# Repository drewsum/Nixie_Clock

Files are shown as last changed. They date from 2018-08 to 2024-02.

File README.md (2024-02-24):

# Nixie_Clock

Rev B Hardware designed with KiCad 7.0.1

Rev B MCU Firmware written with MPLAB X IDE v6.15, compiled with Microchip XC32 2.30 Compiler - NOT COMPATIBLE with newer compiler versions (4.30)

## Rev A Readme:
A nixie clock designed around a PIC16LF1519

Programming notes: PIC16LF1519 (U501) is programmed through PICKIT3 interface header (J501). Firmware included in GIT repository should already be built and the hex file can be programmed directly into the flash on the PIC. If you wish to build it yourself, use Microchip's XC8 compiler, and ensure that the User ID bytes located in NVM match the expected_user_ID[] byte array saved in RAM. The values programmed into NVM are set in /mcc_generated_files/mcc.c, and are set with the line #pragma config IDLOCx = _ . Reference page 44 of the PIC16LF1519 datasheet. If you don't feel like altering user ID's, leave them unchanged in source code, and just build it as is. If user IDs and device IDs do not match, the clock will brick itself until reprogrammed with matching values.

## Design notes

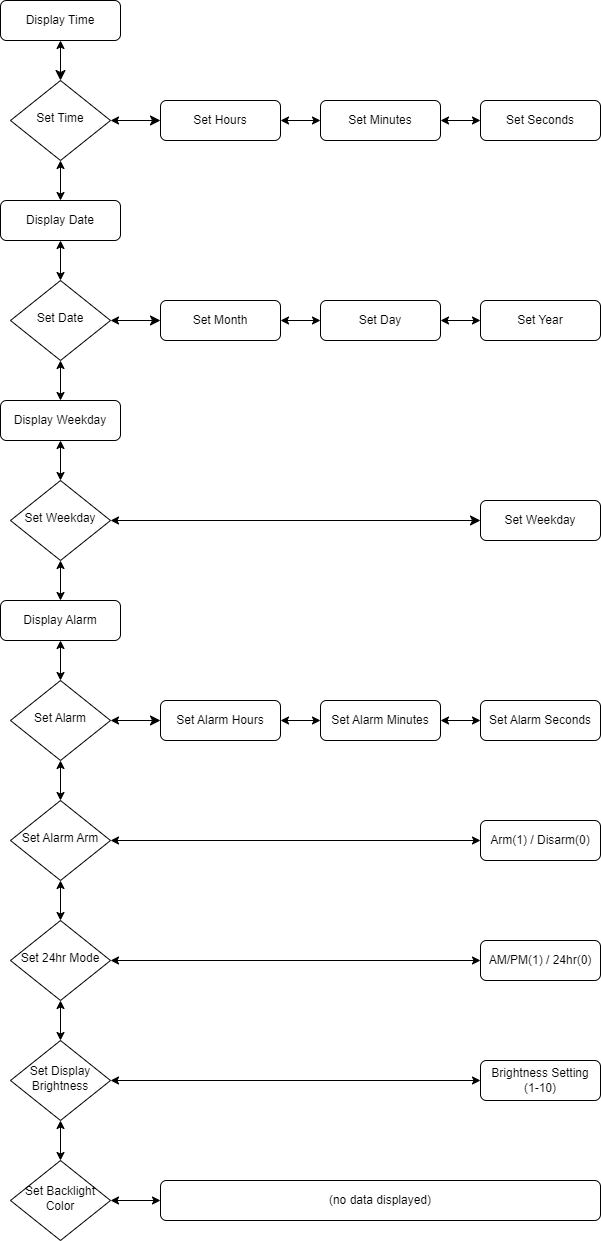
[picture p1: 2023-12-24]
rev_b/doc/pushbutton_menu_flow_chart.png

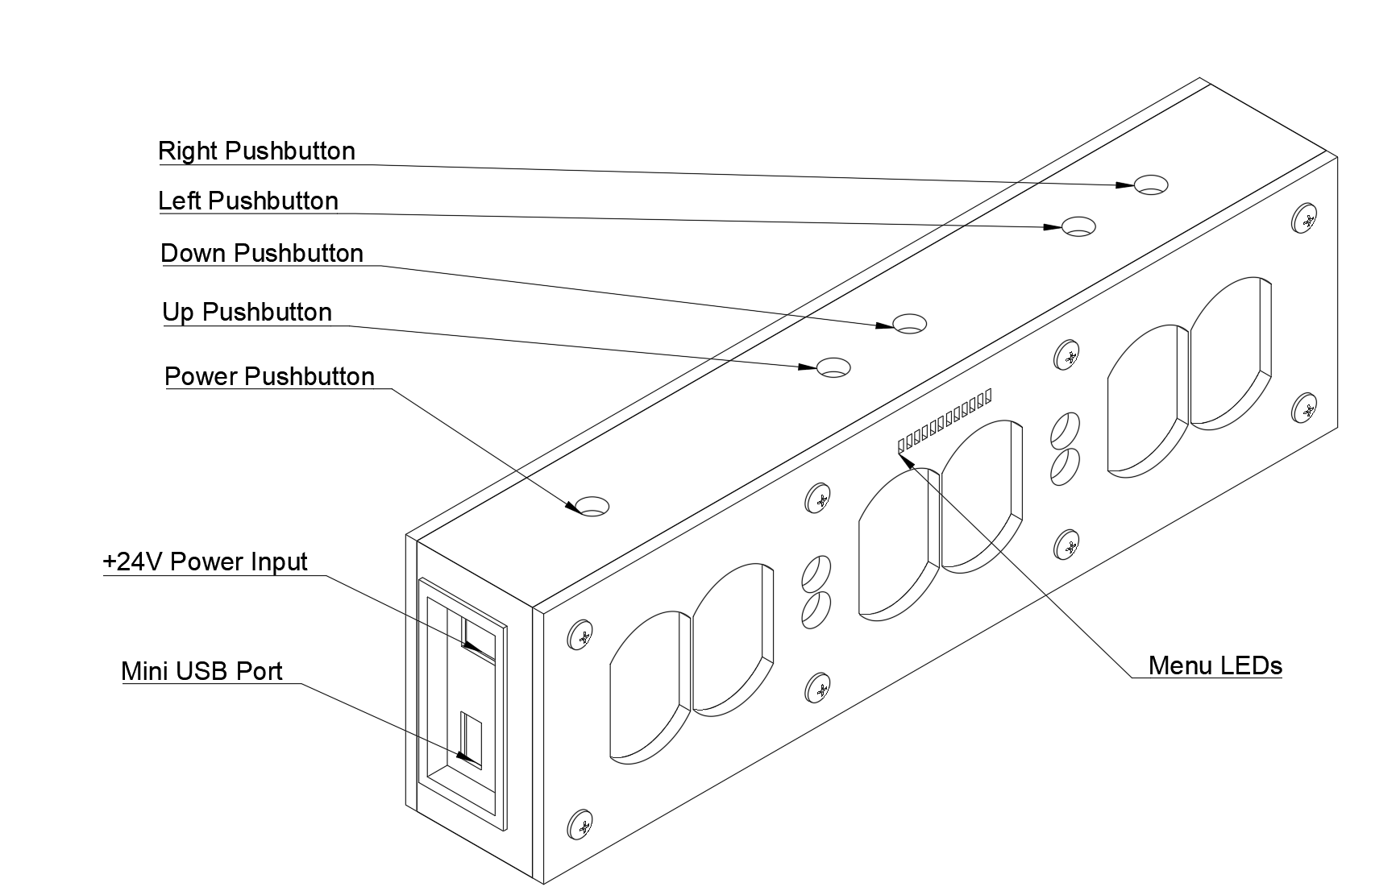
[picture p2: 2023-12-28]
rev_b/doc/IN-12_Variant_Iso_View.png

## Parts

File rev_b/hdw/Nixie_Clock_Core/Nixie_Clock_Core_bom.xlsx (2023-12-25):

References | Value | Configuration | Footprint | Quantity | Digi-Key PN
BT1201 | CR1616 | BACKUP_RTC |  | 1 | P034-ND
BT1202 | CR1616_Holder | BACKUP_RTC | BAT_BU1632SM-JJ-GTR | 1 | BU1632SM-JJ-GCT-ND
BZ2101 | CST-931RP-A |  | MagneticBuzzer_CUI_CST-931RP-A | 1 | 102-1461-ND
C409 C1308 C1309 | 47pF |  | C_0603 | 3 | 13-CC0603JPNPO9BN470CT-ND
C203 C404 C607 | 10nF |  | C_0603 | 3 | 1276-1009-1-ND
C204 C406 C604 C605 C610 C614 C801 C802 C901 C902 C905 C906 C909 C910 C913 C914 C1101 C1102 C1103 C1301 C1302 C1303 C1305 C1306 C1307 C1310 C1312 C1501 C1502 C1503 C1504 C1505 C1601 C1602 C1603 C1604 C1701 C1702 C1703 C1801 C1802 C1804 C2101 C2102 | 0.1uF |  | C_0603 | 44 | 1276-1935-1-ND
C1201 C1203 C1204 C1205 | 0.1uF | BACKUP_RTC | C_0603 | 4 | 1276-1935-1-ND
C1404 | 0.1uF | ETC | C_0603 | 1 | 1276-1935-1-ND
C609 C611 C612 | 0.1uF |  | C_1206 | 3 | 399-C1206C104K2RECAUTOCT-ND
C613 C1901 C1902 | 1.5uF |  | C_2220 | 3 | 565-4697-1-ND
C402 C608 C1803 C1805 | 4.7uF |  | C_0805 | 4 | 1276-2970-1-ND
C405 C903 C904 C907 C908 C911 C912 C915 C916 C1104 C1105 C1304 C1311 C1313 | 10uF |  | C_0603 | 14 | 1276-1871-1-ND
C1202 | 10uF | BACKUP_RTC | C_0603 | 1 | 1276-1871-1-ND
C1401 C1402 C1403 | 10uF | ETC | C_0603 | 3 | 1276-1871-1-ND
C201 C202 C205 C206 C401 C403 C407 C408 C601 C602 C603 C606 C1903 | 10uF |  | C_1206 | 13 | 1276-6767-1-ND
C207 | 47uF |  | CP_EIA-7343-43_Kemet-X | 1 | 399-16639-1-ND
D1401 | BAT48JFILM | ETC | D_SOD-323 | 1 | 497-5711-1-ND
D401 | BAT48JFILM |  | D_SOD-323 | 1 | 497-5711-1-ND
D1302 D1501 D1502 D1504 D1505 D1601 | Green |  | LED_0603 | 6 | 754-1121-1-ND
D801 | PESD3V3L5UY |  | SOT-363_SC-70-6 | 1 | 1727-3828-1-ND
D1503 D1602 D1603 D1604 | Red |  | LED_0603 | 4 | 754-1117-1-ND
D601 D602 D603 D2101 | SMD1200PL |  | D_SOD-123F | 4 | SMD1200PL-TPMSCT-ND
D1301 | Yellow |  | LED_0603 | 1 | 754-1124-1-ND
J1901 | Conn_02x32_Top_Bottom |  | CONN_5120527-1_TYC | 1 | A97407CT-ND
J1301 | USB_B_Mini |  | USB_Mini-B | 1 | 732-2109-1-ND
L401 | 2.2uH |  | L_Vishay_IHLP-2020 | 1 | 541-1268-1-ND
L601 | 680uH |  | Wurth_7447709681 | 1 | 732-1700-1-ND
L801 L802 L901 L902 L1101 L1102 L1301 L1302 | 600R 0.5A |  | L_0603 | 8 | 490-1014-1-ND
N201 | 24V PSU |  |  | 1 | 1939-1835-ND
Q401 Q801 Q2101 | BSS214NW |  | SOT-323_SC-70 | 3 | BSS214NWH6327XTSA1CT-ND
Q601 | IRFL214 |  | SOT-223-3_TabPin2 | 1 | IRFL214PBFCT-ND
Q402 | ZXMS6004FFTA |  | SOT-23 | 1 | ZXMS6004FFCT-ND
R206 R406 | 0.02 |  | R_0612 | 2 | P16010CT-ND
R611 | 0.36 |  | R_0805 | 1 | RL12S.36FCT-ND
R616 | 1.5 |  | R_0612 | 1 | RCL06121R20FKEA
R401 R801 R803 R1103 R1104 R2110 | 10 |  | R_0603 | 6 | 541-10.0HCT-ND
R2106 | 10 | ETC | R_0603 | 1 | 541-10.0HCT-ND
R2109 | 10 | BACKUP_RTC | R_0603 | 1 | 541-10.0HCT-ND
R1308 R1309 | 27 |  | R_0603 | 2 | 541-5306-1-ND
R602 | 330 |  | R_0603 | 1 | 541-330HCT-ND
R805 R1301 R1310 R1502 R1503 R1504 R1505 R1506 R1603 R1604 R1607 R1608 | 1k |  | R_0603 | 12 | 541-1.00KHCT-ND
R609 | 1.33k |  | R_0603 | 1 | 541-1.33KHCT-ND
R211 | 1.6k |  | R_0603 | 1 | 541-5237-1-ND
R201 | 1.78k |  | R_0603 | 1 | 541-1.78KHCT-ND
R603 | 3.4k |  | R_0603 | 1 | 541-3.40KHCT-ND
R1303 | 6.04k |  | R_0603 | 1 | 541-CRCW06036K04FKEBCT-ND
R610 | 6.49k |  | R_0603 | 1 | 541-5537-1-ND
R203 R204 R207 R210 R212 R402 R404 R605 R612 R802 R804 R1001 R1002 R1101 R1102 R1105 R1106 R1203 R1305 R1501 R1601 R1602 R1605 R1606 R1701 R1702 R1703 R1801 R1802 R1803 R1805 R1806 R2102 R2104 R2105 R2107 R2108 R2111 | 10k |  | R_0603 | 38 | 541-10.0KHCT-ND
R606 | 10k |  | R_0603 | 1 | 541-10.0KHCT-ND
R604 | 14k |  | R_0603 | 1 | 541-CRCW060314K0FKTACT-ND
R403 | 18.2k |  | R_0603 | 1 | 541-18.2KHCT-ND
R614 | 28.7k |  | R_0603 | 1 | 541-28.7KHCT-ND
R1304 | 40.2k |  | R_0603 | 1 | 541-5412-1-ND
R607 R1306 R1307 R1311 R1312 | 100k |  | R_0603 | 5 | 541-100KHCT-ND
R202 | 200k |  | R_0603 | 1 | 541-4027-1-ND
R1202 | 220k | BACKUP_RTC | R_0603 | 1 | 541-4039-1-ND
R409 | 309k |  | R_0603 | 1 | 541-309KHCT-ND
R1302 | 487k |  | R_0603 | 1 | 541-487KHCT-ND
R1201 | 1M | BACKUP_RTC | R_0603 | 1 | 541-1.00MHCT-ND
R408 | 1M |  | R_0603 | 1 | 541-1.00MHCT-ND
R2101 | 1.07M |  | R_0603 | 1 | 541-1.07MHCT-ND
R601 | 1.6M |  | R_0603 | 1 | 541-1.60MHCT-ND
R608 R613 | 1.6M |  | R_0603 | 2 | 541-1.60MHCT-ND
RN1701 RN1702 RN1703 RN1801 RN1802 | 10k |  | R_Array_Convex_8x0602 | 5 | Y1103CT-ND
U1101 | 74LVC1G97 |  | SOT-363_SC-70-6 | 1 | 296-15582-1-ND
U1303 U1601 U1602 U1603 U1604 | 74LVC1G97 |  | SOT-363_SC-70-6 | 5 | 296-15582-1-ND
U1501 U1502 U1504 U1505 | 74LVC1G97 |  | SOT-363_SC-70-6 | 4 | 296-15582-1-ND
U1503 | 74LVC1G97 |  | SOT-363_SC-70-6 | 1 | 296-15582-1-ND
U2102 | 74LVC1G97 |  | SOT-363_SC-70-6 | 1 | 296-15582-1-ND
U1701 U1702 U1703 U1802 | 74VHC541 |  | WQFN-20-1EP_2.5x4.5mm_P0.5mm_EP1x2.9mm | 4 | 1727-7068-1-ND
U1401 | DS1683 | ETC | SOIC-8_3.9x4.9mm_Pitch1.27mm | 1 | DS1683S+-ND
U1201 | DS3231MZ | BACKUP_RTC | SOIC-8_3.9x4.9mm_P1.27mm | 1 | DS3231MZ+-ND
U1302 | FT234XD |  | DFN-12-1EP_3x3mm_Pitch0.45mm | 1 | 768-1178-1-ND
U1304 | ISO7321C |  | SOIC-8_3.9x4.9mm_P1.27mm | 1 | 296-42102-1-ND
U602 | LT3757 |  | DFN-10-1EP_3x3mm_Pitch0.5mm | 1 | LT3757IDD#PBF
U401 | LT8609A-DD |  | DFN-10-1EP_3x3mm_Pitch0.5mm | 1 | 505-LT8609AEDDM#TRPBFCT-ND
U2101 | LTC6900 |  | SOT-23-5 | 1 | LTC6900CS5#TRMPBFCT-ND
U1001 | PIC32MZ2048EFG100_IPF |  | TQFP-100_14x14mm_Pitch0.5mm | 1 | PIC32MZ0512EFE100-I/PF-ND
U1801 | TCA9803 |  | VSSOP-8_3.0x3.0mm_P0.65mm | 1 | 296-47829-1-ND
U1202 | TLV6700 | BACKUP_RTC | SOT-23-6 | 1 | 296-51696-1-ND
U601 U603 U1301 | TLV6700 |  | SOT-23-6 | 3 | 296-51696-1-ND
U1305 | TPD3S014DBVR |  | SOT-23-6 | 1 | 296-38835-1-ND
U201 | TPS26600RHFT |  | QFN-24-1EP_4x5mm_Pitch0.5mm | 1 | 296-45478-1-ND
X1101 | ASE-8.000MHz |  | Oscillator_SMD_Abracon_ASE-4Pin_3.2x2.5mm | 1 | 535-9558-1-ND
X1102 | ECS-327KE |  | ECS-327KE | 1 | XC1751CT-ND

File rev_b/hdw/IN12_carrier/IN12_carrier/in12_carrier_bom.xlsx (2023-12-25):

References | Value | Configuration | Footprint | Quantity Per PCB | Digi-Key PN
C1007 C1008 C1009 C1010 C1016 | 10nF |  | C_0603 | 5 | 1276-1009-1-ND
C707 C708 C709 C1001 C1002 C1003 C1004 C1005 C1006 C1011 C1012 C1013 C1014 C1015 C1017 | 0.1uF |  | C_0603 | 15 | 1276-CL10B104KB8NNNLCT-ND
C304 C305 | 0.1uF | ETC | C_0603 | 2 | 1276-CL10B104KB8NNNLCT-ND
C301 C302 C303 | 10uF | ETC | C_0603 | 3 | 1276-1871-1-ND
C701 C702 C703 C704 C705 C706 | 10uF |  | C_0603 | 6 | 1276-1871-1-ND
D701 D702 D703 D704 D705 D706 D707 D708 | ASMB-MTB0-0A3A2 |  | LED_Avago_PLCC4_3.2x2.8mm_CW | 8 | 516-3279-1-ND
D901 D1001 D1002 D1003 D1004 D1005 D1006 D1007 D1008 D1009 D1010 D1011 | Amber |  | LED_0603 | 12 | 732-150060AS75000CT-ND
D301 | BAT48JFILM | ETC | D_SOD-323 | 1 | 497-5711-1-ND
J201 | Conn_02x32_Top_Bottom |  | CONN_5120528-1_TYC | 1 | A104089CT-ND
MK1107 MK1108 MK1115 MK1116 MK1123 MK1124 MK1131 MK1132 MK1133 MK1134 MK1135 MK1136 MK1137 MK1138 MK1139 MK1140 | Screw |  |  | 16 | 36-9900-ND
MK1101 MK1102 MK1103 MK1104 MK1105 MK1106 MK1109 MK1110 MK1111 MK1112 MK1113 MK1114 MK1117 MK1118 MK1119 MK1120 MK1121 MK1122 MK1125 MK1126 MK1127 MK1128 MK1129 MK1130 | Standoff |  |  | 8 | 1772-2080-ND
MK1101 MK1102 MK1103 MK1104 MK1105 MK1106 MK1109 MK1110 MK1111 MK1112 MK1113 MK1114 MK1117 MK1118 MK1119 MK1120 MK1121 MK1122 MK1125 MK1126 MK1127 MK1128 MK1129 MK1130 | Standoff |  |  | 16 | 1772-1220-ND
Q401 Q402 Q403 Q407 Q408 Q409 Q501 Q502 Q503 Q504 Q505 Q506 Q507 Q508 Q509 Q510 Q511 Q512 Q513 Q514 Q515 | MMSTA42 |  | SOT-323_SC-70 | 21 | MMSTA42-FDICT-ND
Q404 Q405 Q406 Q410 Q411 Q412 | MMSTA92 |  | SOT-323_SC-70 | 6 | MMSTA92-TPCT-ND
R901 R1001 R1002 R1003 R1004 R1005 R1006 R1007 R1008 R1009 R1010 R1011 R1016 R1017 R1018 R1019 R1021 | 499 |  | R_0603 | 17 | 541-CRCW0603499RFKEBCT-ND
R704 R705 R706 | 3.65k |  | R_0603 | 3 | 541-3.65KHCT-ND
R701 R1012 R1013 R1014 R1015 R1020 | 10k |  | R_0603 | 6 | 541-10.0KHCT-ND
R301 R302 R305 | 10k | ETC | R_0603 | 3 | 541-10.0KHCT-ND
R401 R402 R403 R413 R414 R415 R501 R502 R503 R504 R505 R506 R507 R508 R509 R510 R511 R512 R513 R515 R516 | 10k |  | R_0603 | 21 | 541-10.0KHCT-ND
R601 R602 R603 R604 | 10k |  | R_0805 | 4 | 541-3015-1-ND
R410 R411 R412 R422 R423 R424 R514 | 18k |  | R_0805 | 7 | 541-18.0KCCT-ND
R407 R408 R409 R419 R420 R421 | 100k |  | R_0805 | 6 | 541-4318-1-ND
R303 | 392k | ETC | R_0603 | 1 | 541-392KHCT-ND
R404 R405 R406 R416 R417 R418 R801 R802 R803 R804 R805 R806 R807 R808 R809 R810 R811 R812 R813 R814 R815 R816 R817 | 470k |  | R_0805 | 23 | 541-470KCCT-ND
R304 | 1M | ETC | R_0603 | 1 | 541-2990-1-ND
U1002 | 24AA02-OT |  | SOT-23-5 | 1 | 24AA02E64T-I/OT
U1003 U1004 U1005 U1006 U1007 | AT42QT1010-TSHR |  | SOT-23-6 | 5 | AT42QT1010-TSHRCT-ND
U301 | DS1683 | ETC | SOIC-8_3.9x4.9mm_Pitch1.27mm | 1 | DS1683S+-ND
U701 U702 U703 | LP5009 |  | UQFN-20-1EP_3x3mm_Pitch0.4mm | 3 | 296-LP5009RUKRCT-ND
U302 | LTC4316DD | ETC | DFN-10-1EP_3x3mm_Pitch0.5mm | 1 | LTC4316IDD#PBF-ND
U1001 | TCA9555RGER |  | QFN-24-1EP_4x4mm_P0.5mm_EP2.6x2.6mm | 1 | 296-44537-1-ND
MK1001 | Pushbutton Cable |  |  | 1 | SAM8931-ND
MK1002 MK1003 MK1004 MK1005 MK1006 | Pushbuttons |  |  | 5 | 36-7600-ND
MK1101 | Feet |  |  | 1 | SJ5523-0-ND

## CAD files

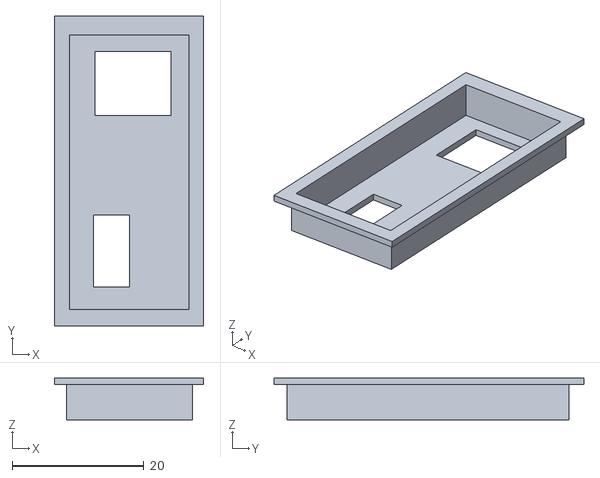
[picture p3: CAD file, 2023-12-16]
rev_b/misc/Nixie_Clock_Case_Connector Plate v2.stl
22.6 x 47.1 x 6.35

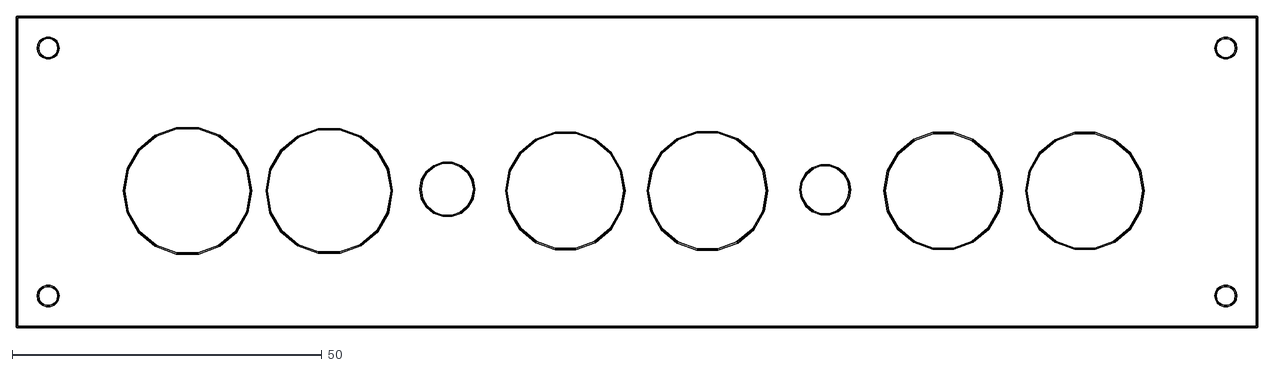
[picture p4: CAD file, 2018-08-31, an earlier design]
rev_a/Nixie Clock/Models/Nixie Test-Dwgs.User.dxf
200.2 x 50.2

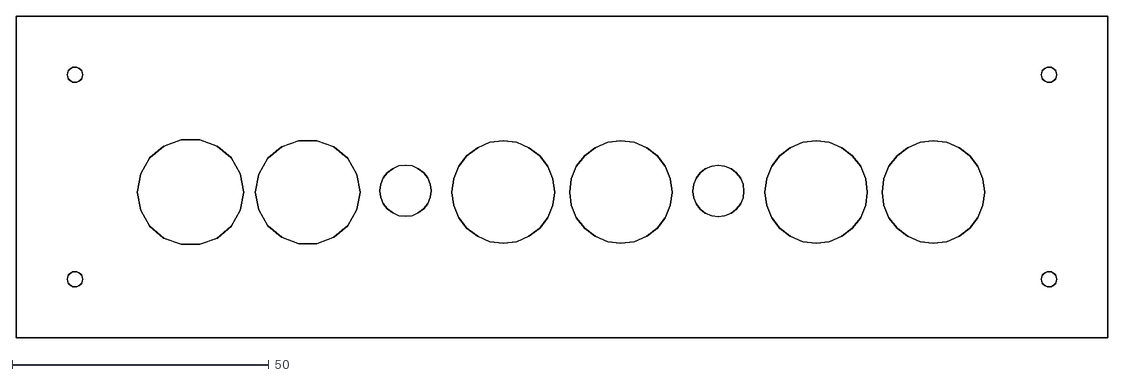
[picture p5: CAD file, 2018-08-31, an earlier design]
rev_a/Nixie Clock/Models/TopPlate.dxf
212.7 x 62.7

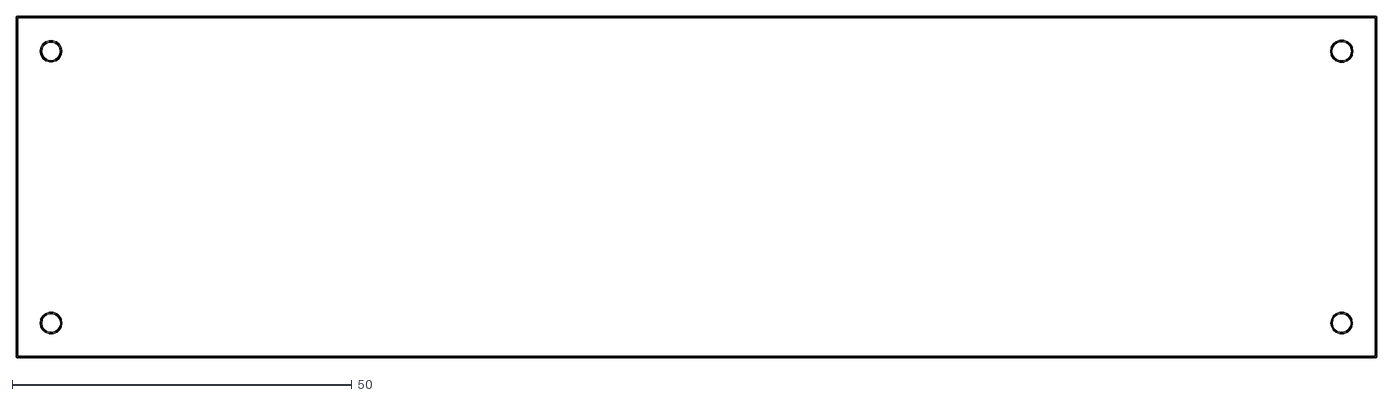
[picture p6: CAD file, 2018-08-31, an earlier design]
rev_a/Nixie Clock/Models/Nixie Clock-Dwgs.User.dxf
200.2 x 50.2

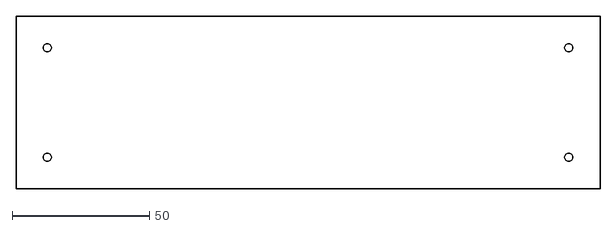
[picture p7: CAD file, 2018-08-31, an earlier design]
rev_a/Nixie Clock/Models/BottomPlate.dxf
212.7 x 62.7

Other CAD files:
rev_a/sfw/U501_Firmware/NixieClock.X/dist/default/production/NixieClock.X.production.obj
rev_a/Nixie Clock/Gerbers/SketchupModel.skp
rev_a/Nixie Clock/Gerbers/SketchupModel~.skp
rev_a/Nixie Clock/Models/BottomPlate.skp
rev_a/Nixie Clock/Models/BottomPlate~.skp
rev_a/Nixie Clock/Models/EnclosureWalls.skp
rev_a/Nixie Clock/Models/EnclosureWalls~.skp
rev_a/Nixie Clock/Models/SketchupModel.skp
rev_a/Nixie Clock/Models/TopPlate.skp
rev_b/misc/Nixie_Clock_Case v67.f3z

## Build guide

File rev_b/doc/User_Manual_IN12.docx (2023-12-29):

Drew Maatman

# Nixie clock redux

IN-12 VARIANT (ИН-12Б)

User Manual

# 1. Warnings

- This design contains high voltages that can be dangerous
- Ever effort has been made to keep this project safe, but the user assumes all risk
- The high voltage power supply has been designed with a low current limit to try to mitigate risk
- If any internal circuitry becomes exposed, do not touch it while the power cord is plugged in
- Do not use this project outside of its casing
- If the nixie tubes break, do not touch the metal elements inside. Remove power from the clock immediately
- The case is not waterproof
- The USB port is electrically isolated to mitigate risk of electrical stress to a host PC should a fault occur
- If the internal battery (CR1616 coin cell) needs to be replaced, do not leave the clock powered while changing the battery
- I am always willing to help troubleshoot issues, reach me at drewmaatman@gmail.com
- Nixie tubes age and degrade over time. Every effort has been made to maximize their lifetime within this design. The nixie tubes can be replaced if elements within them fail. Only do this when the clock is unpowered, and use care to not damage adjacent tubes

# 2. Clock Overview


Figure 1: Overview

- The clock requires a +24V DC power supply which can provide at least 12W of power
- The DC barrel jack for power input is center positive polarity
- The USB port is a USB 2.0 Mini B connector. This provides a serial interface and cannot power the clock (see USB/Serial Interface)
- The menu LEDs indicate the following menu settings, from left to right (see Pushbutton Interface)
  - Display Time
  - Set Time
  - Display Date
  - Set Date
  - Display Weekday
  - Set Weekday
  - Display Alarm
  - Set Alarm
  - Set Alarm Arm/Disarm
  - Set 24hr or AM/PM Format
  - Set Tube Brightness
  - Set RGB Backlight Color

# 3. Clock Features

- The tubes can be configured to display:
  - Time (24 hour or AM/PM)
  - Date (MM/DD/YY)
  - Weekday (Numbered from 1 to 7)
  - Alarm Time (24 hour or AM/PM)
  - Alarm Arm (Armed or Disarmed), see Setting the Alarm, Arming/Disarming the Alarm (with pushbuttons) as well as Setting the Alarm and Arming the Alarm (with USB/Serial Interface).
  - Time/Date/Weekday and Alarm Setting Modes (set through pushbuttons or USB serial port)
  - Tube Brightness Setting (10% to 100%)
  - Tube RGB Backlight Color (build option)
- Additional Features:
  - USB Serial Port
  - Tube Elapsed Time Counter (build option, see Supported Serial Commands)
    - Nixie tubes age, this can track how long voltage has been applied, as well as how many times voltage has been cycled
  - Clock Elapsed Time Counter (build option, see Supported Serial Commands)
    - Tracks total time clock has input power applied, power cycles
  - Capacitive Touch Pushbuttons for Power On/Off and user interface
  - Battery Backed Real Time Clock (build option), battery backed time is updated whenever time is set on clock through pushbuttons or USB serial port
  - Internal Telemetry (build option, see Supported Serial Commands)
  - Input Power Protection
    - Reverse Polarity Protection
    - Input Under/Overvoltage Protection
    - Input Current Limit
  - Tube RGB Backlight Brightness (adjustable over USB, see Supported Serial Commands)

# 4. Pushbutton Interface


Figure 2: Pushbutton Menus

## A. Description

The pushbuttons allow setting time, date, weekday, alarm time, arming and disarming the alarm, the time hours format (AM/PM vs 24hr), tube brightness, and the tube RGB backlight color, if supported. The pushbuttons also allow for the selection of which data to be displayed on the clock, including time, date, weekday, and alarm time.

The up, down, left, and right pushbuttons allow for navigation through the menu displayed in Figure 2: Pushbutton Menus. The current menu item setting (leftmost column in Figure 2: Pushbutton Menus) is set using the up/down pushbuttons, and the menu item setting is displayed on the menu LEDs on the top edge of the clock. This is slightly counter-intuitive, as the menu items are visualized vertically and set using up/down pushbuttons, but the menu item LEDs are arranged left to right, for circuit layout reasons.

The top menu item (Display Time) is the left-most indicator when displayed on the menu LEDs, and the bottom menu item (Set Backlight Color) is the right-most indicator when displayed on the menu LEDs.

When navigating through the menu items using the up/down pushbuttons, the menu LEDs will update, and the data displayed on the tubes will change. The menu sub-items (the items further to the right within the menus described in Figure 2: Pushbutton Menus) can be navigated to using the left/right pushbuttons. The menu sub-item current selected for changing will blink on the tubes when it is selected. That data can then be changed using the up/down pushbuttons.

To finalize the change, the left/right pushbuttons should be used to move back to the menu item, such that no tubes are blinking. The sub-menus “wrap around,” such that when the user selects the sub-menu furthest to the right, a single push of the right pushbutton will leave the sub-menu for the main menu item. Then, the up/down pushbuttons can be used to navigate back to the “display time” menu item, or any other menu item desired.

## B. Setting the Time

            a. The clock must be powered on
            b. Start from the “Display Time” menu item (upper-most menu item in Figure 2, no tubes will be blinking). The left-most menu LED should be illuminated
            c. Press the down pushbutton once. The “Set Time” menu LED (second from the left) will be the only menu LED illuminated. No tubes will blink, but all four colons will be solid, instead of blinking
            d. Press the right pushbutton once. The “Set Hours” sub menu is now active. The left set of nixie tubes will be blinking, indicating the user is setting the hours
            e. Use the up and down pushbuttons to increase or decrease the hour displayed on the clock
            f. Press the right pushbutton again. The hour tubes will stop blinking, and the minute tubes will now blink, indicating that minutes are now what are being changed
            g. Use the up and down pushbuttons to increase or decrease the minutes displayed on the clock
            h. Press the right pushbutton again. The minute tubes will stop blinking, and now the second tubes will blink
            i. Use the up and down pushbuttons to set the seconds
            j. Finally, either press the right pushbutton once (to wrap around from the set-seconds sub-menu to the set time menu item), or press the left pushbutton three times. No tubes will be blinking, indicating the “Set Time” menu item is selected
            k. Press the up pushbutton once. This will change the menu item from “Set Time” to “Display Time.” The menu LEDs update, and the left-most menu LED should now be illuminated. The colons will now blink.

## C. Setting the Date

            a. The clock must be powered on
            b. Start from the “Display Time” menu item (upper-most menu item in Figure 2). The left-most menu LED should be illuminated
            c. Press the down pushbutton three times. The “Set Date” menu LED (fourth from the left) will be the only menu LED illuminated. No tubes will blink, but the lower colons will be solid, instead of blinking
            d. Press the right pushbutton once. The “Set Month” sub menu is now active. The left set of nixie tubes will be blinking, indicating the user is setting the month
            e. Use the up and down pushbuttons to increase or decrease the month displayed on the clock
            f. Press the right pushbutton again. The month tubes will stop blinking, and the day tubes will now blink, indicating that day of the month is now what is being changed
            g. Use the up and down pushbuttons to increase or decrease the day of the month displayed on the clock
            h. Press the right pushbutton again. The day tubes will stop blinking, and now the year tubes will blink (furthest to right)
            i. Use the up and down pushbuttons to set the last two digits of the year (from 2000 to 2099)
            j. Finally, either press the right pushbutton once (to wrap around from the set-year sub-menu to the set date menu item), or press the left pushbutton three times. No tubes will blink
            k. Press the up pushbutton three times. This will change the menu item from “Set Date” to “Display Time.” The menu LEDs update, and the left-most menu LED should now be illuminated. The colons will now blink.
            l. Date can be displayed by pressing the down pushbutton twice when starting at the “Display Time” menu item. This will change the menu item from “Display Time” to “Display Date.” The menu LED lit should be third from the left.

## D. Setting the Weekday

            a. The clock must be powered on
            b. Start from the “Display Time” menu item (upper-most menu item in Figure 2). The left-most menu LED should be illuminated
            c. Press the down pushbutton five times. The “Set Weekday” menu LED (sixth from the left) will be the only menu LED illuminated. No tubes will blink
            d. Press the right pushbutton once. The “Set Weekday” sub menu is now active. The right set of nixie tubes will be blinking, indicating the user is setting the weekday (1-7, 1 being Sunday)
            e. Use the up and down pushbuttons to increase or decrease the weekday displayed on the clock
            f. Either press the right pushbutton once (to wrap around from the set-weekday sub-menu to the set weekday menu item), or press the left pushbutton once. No tubes will blink
            g. Press the up pushbutton five times. This will change the menu item from “Set Weekday” to “Display Time.” The menu LEDs update, and the left-most menu LED should now be illuminated. The colons will now blink.
            h. Weekday can be displayed by pressing the down pushbutton four times when starting at the “Display Time” menu item. This will change the menu item from “Display Time” to “Display Weekday.” The menu LED lit should be fifth from the left.

## E. Setting the Alarm

            a. The clock must be powered on
            b. Start from the “Display Time” menu item (upper-most menu item in Figure 2). The left-most menu LED should be illuminated
            c. Press the down pushbutton seven times. The “Set Alarm” menu LED (fourth from the right) will be the only menu LED illuminated. No tubes will blink
            d. Press the right pushbutton once. The “Set Alarm Hours” sub menu is now active. The left set of nixie tubes will be blinking, indicating the user is setting the alarm hours
            e. Use the up and down pushbuttons to increase or decrease the alarm hour displayed on the clock
            f. Press the right pushbutton again. The alarm hour tubes will stop blinking, and the alarm minute tubes will now blink, indicating that alarm minutes are now what are being changed
            g. Use the up and down pushbuttons to increase or decrease the alarm minutes displayed on the clock
            h. Press the right pushbutton again. The alarm minute tubes will stop blinking, and now the alarm seconds tubes will blink
            i. Use the up and down pushbuttons to set the alarm seconds
            j. Finally, either press the right pushbutton once (to wrap around from the set-alarm seconds sub-menu to the set alarm menu item), or press the left pushbutton three times. No tubes will blink
            k. Press the up pushbutton seven times. This will change the menu item from “Set Alarm” to “Display Time.” The menu LEDs update, and the left-most menu LED should now be illuminated. The colons will now blink.
            l. The time that the alarm is set to can be displayed by pressing the down pushbutton six times when starting at the “Display Time” menu item. This will change the menu item from “Display Time” to “Display Alarm.” The menu LED lit should be sixth from the right.

## F. Arming/Disarming the Alarm

            a. The clock must be powered on
            b. Start from the “Display Time” menu item (upper-most menu item in Figure 2). The left-most menu LED should be illuminated
            c. Press the down pushbutton eight times. The “Set Alarm Arm” menu LED (fourth from the right) will be the only menu LED illuminated. No tubes will blink
            d. Press the right pushbutton once. The “Set Alarm Arm” sub menu is now active. The right set of nixie tubes will be blinking, indicating the user is setting if the alarm is armed or not. “1” corresponds to the alarm being armed, “0” corresponds to the alarm being disarmed.
            e. Use the up and down pushbuttons to change the alarm arming setting, between 0 and 1.
            f. Either press the right pushbutton once (to wrap around from the set-alarm-arm sub-menu to the set alarm arm menu item), or press the left pushbutton once. No tubes will blink
            g. Press the up pushbutton eight times. This will change the menu item from “Set Alarm Arm” to “Display Time.” The menu LEDs update, and the left-most menu LED should now be illuminated. The colons will now blink. The alarm will be armed if the set-alarm-arm sub-menu is set to 1.
            h. Checking to see if the alarm is armed or disarmed is done by navigating to the same “Set Alarm Arm” menu item (by pushing the down pushbutton 8 times, from “Display Time”). There is no separate menu to view the alarm arming setting
            i. When the alarm sounds, it can be disabled by pressing any pushbutton a single time. There is no snooze feature

## G. Setting the Time Format (24hr/ AM/PM)

            a. The clock must be powered on
            b. Start from the “Display Time” menu item (upper-most menu item in Figure 2). The left-most menu LED should be illuminated
            c. Press the down pushbutton nine times, or press the up pushbutton three times. The “Set 24 Hour Mode” menu LED (third from the right) will be the only menu LED illuminated. No tubes will blink
            d. Press the right pushbutton once. The “Set 24 Hour Mode” sub menu is now active. The right set of nixie tubes will be blinking, indicating the user is setting the time format. “1” corresponds to the hours being displayed in 24 hour format (0 to 23 hours), “0” corresponds to the time being displayed in AM/PM format.
            e. Use the up and down pushbuttons to change the time format setting, between 0 and 1.
            f. Either press the right pushbutton once (to wrap around from the set-24-hour mode sub-menu to the set 24 hour menu item), or press the left pushbutton once. No tubes will blink
            g. Press the up pushbutton nine times. This will change the menu item from “Set 24 hr mode” to “Display Time”. The menu LEDs update, and the left-most menu LED should now be illuminated. The colons will now blink.
            h. When in 24 hour mode, the time is reflected in 24 hour format. When in AM/PM mode, a small decimal point is illuminated on the hours tubes to indicate if the time is PM or AM (AM lacking decimal point, PM includes decimal point). All time modes are displayed based on this setting, including “Display Time,” “Set Time,” “Display Alarm,” and “Set Alarm”

## H. Setting the Display Brightness

            a. The clock must be powered on
            b. Start from the “Display Time” menu item (upper-most menu item in Figure 2). The left-most menu LED should be illuminated
            c. Press the down pushbutton ten times, or press the up pushbutton twice. The “Set Brightness” menu LED (second from the right) will be the only menu LED illuminated. No tubes will blink
            d. Press the right pushbutton once. The “Set Brightness” sub menu is now active. The right set of nixie tubes will be blinking, indicating the user is setting the display brightness. “10” corresponds to the brightness being set to 100%. “1” corresponds to the brightness being set to 10%. Increments of 10% are available.
            e. Use the up and down pushbuttons to change the display brightness setting, between 1 and 10. The tube brightness will be actively adjusted.
            f. Either press the right pushbutton once (to wrap around from the set brightness sub-menu to the set brightness menu item), or press the left pushbutton once. No tubes will blink
            g. Press the up pushbutton ten times. This will change the menu item from “Set Brightness” to “Display Time.” The menu LEDs update, and the left-most menu LED should now be illuminated. The colons will now blink.

## I. Setting the RGB Backlight Color (if supported)

            a. The clock must be powered on
            b. Start from the “Display Time” menu item (upper-most menu item in Figure 2). The left-most menu LED should be illuminated
            c. Press the down pushbutton eleven times, or press the up pushbutton once. The “Set Color” menu LED (furthest to the right) will be the only menu LED illuminated. No tubes will blink, and no data will be displayed.
            d. Unlike other menu items, there are no submenus, so pressing the right and left pushbuttons are what change the backlight color
            e. Use the left and right pushbuttons to select the desired backlight color
            f. Press the up pushbutton eleven times. This will change the menu item from “Set Color” to “Display Time.” The menu LEDs update, and the left-most menu LED should now be illuminated. The colons will now blink.
            g. The RGB backlight brightness cannot be adjusted using the pushbuttons, see Setting the Tube RGB Backlight

# 5. USB/Serial Interface

## A. Establishing a Connection

The Nixie Clock can be communicated with through its USB port. It enumerates as an FTDI virtual COM port on Windows, Macintosh, and Linux machines. The following serial settings should be used:

- 115.2kBaud
- 8-bit Data Length
- No Parity
- 1 stop bit
- No flow control

A serial client such as PuTTY or TeraTerm can be used on Windows machines. Macintosh and Linux machines allow serial communication through the command line using the screen command. If using PuTTY, ensure that Implicit CR in every LF is enabled, Local Echo is set to Force on, and Local Line Editing is set to Force on.

## J. Beginning Communication

On reset (power on or software/hardware reset), the Nixie Clock will print startup messages and debug information about the startup code as it configures itself. This will not appear if the serial terminal is opened after boot is complete. An easy way to determine if a connection is established after boot-up is to call the *IDN? command. The clock will respond with an identification string used for automation scripts.

## K. Serial Color Scheme

- Help messages and neutral responses appear in yellow
- System parameters and affirmative responses appear in green
- Measurement responses appear in cyan
- Urgent/interrupt messages appear in magenta
- Errors and negative responses appear in red
- User input appears in white

## L. Help command

All supported serial commands, as well as arguments that can be passed with them, can be printed with the Help command. A one-line description of each supported command is also printed.

## M. Setting the Time

The internal real-time clock and calendar (RTCC) can be set over the USB interface. The real-time clock and calendar tracks time, date, and weekday. All RTCC settings can be adjusted using the Set RTCC command, which requires an argument passed for what should be adjusted, along with the value that the RTCC should be adjusted to. For example:

Set RTCC: Time: 09:30:25 would set the current time to 9:30 and 25 seconds, AM

Set RTCC: Time: 21:30:25 would set the current time to 9:30 and 25 seconds, PM (regardless of time format displayed, RTCC time must be entered in a 24-hour format)

Set RTCC: Date: 04/24/2023 would set the current date to April 24th, 2023 (only years between 2000 and 2099 are supported. All four digits of year must be entered)

Set RTCC: Weekday: Friday would set the current weekday as Friday. The RTCC weekday is set with a string, while it is displayed on the Nixie tubes as a number (1 to 7)

The Nixie Clock will respond to each of these commands indicating what RTCC settings have been adjusted to

## N. Selecting what is Displayed

The clock can be configured to display information through the USB interface in a similar fashion to what the pushbuttons can select what to display.

Set Display Mode: Time would configure the clock to show the current time (most use cases)

Set Display Mode: Date would configure the clock to show the current date

Set Display Mode: Weekday would configure the clock to show the current weekday (numbered 1 through 7, 1 being Sunday)

Set Display Mode: Alarm would configure the clock to show the time that the alarm is set for

## O. Setting the Alarm

Set Alarm: 09:30:25 would set the alarm time for 9:30 AM and 25 seconds. This must be entered in 24-hour time format. This does not actually arm the alarm to sound.

## P. Arming the Alarm

Arm Alarm: Arm would enable the alarm to sound at the time set by the Set Alarm command. Once the alarm sounds, it can be disarmed/silenced by pressing any pushbutton once, or by sending the Arm Alarm: Disarm command. There is no snooze function.

## Q. Setting the Tube RGB Backlight Settings

Set Backlight Color: Red would set the RGB tube backlight, if installed, to be a solid red color. Supported colors include Black (off, default), Red, Green, Blue, Cyan, Magenta, Yellow, and White. Any 24-bit RGB hex code can also be sent for custom colors (FFFFFF would correspond to white, for instance, while FF0000 would correspond to Red)

Set Backlight Brightness: 90 would set the RGB tube backlight, if installed, to a brightness level of 90%.

## R. Turning the clock On and Off

Set Power: On enables the clock. Set Power: Off disables the clock. Whenever the clock is turned on through either the power pushbutton or the USB interface, Time is always selected to be displayed, and the RGB backlight is disabled.

## S. Supported Serial Commands

All supported serial commands and their help messages are listed below:

Help: Prints help message for all supported serial commands

Reset: Executes an MCU software reset

Clear Screen: Clears the serial port terminal

*IDN?: Prints identification string

Repository?: Prints project Git repo location

Host Status?: Prints status of MCU host device (IDs, WDT, DMT, Prefetch, Cause of Reset, up time)

Peripheral Status? <peripheral_name>: Prints status of passed host peripheral.

Available peripherals:

Interrupts

Clocks

PMD

WDT

DMT

Prefetch

DMA

ADC

ADC Channels

I2C Master

RTCC

Timer <x> (x = 1-9)

Error Status?: Prints the status of various error handler flags

Clear Errors: Clears all error handler flags

Platform Status?: Prints current state of surrounding circuitry, including PGOOD, clock elapsed time, I2C slaves

Live Telemetry: Toggles live updates of system level telemetry

Time and Date?: Prints the current system time and date

Set RTCC: <parameter>: <parameter args>: sets a time parameter within the Real Time Clock and Calendar. Available parameters:

Date: <mm>/<dd>/<yyyy>: Sets the RTCC date

Time: <hh>:<mm>:<ss>: Sets the RTCC time. (Must be 24 hr time format)

Weekday: <weekday>: Sets the RTCC weekday

Unix Time: <decimal unix time>, <hour offset from UTC to local time>: sets the RTCC to the supplied UNIX time with hour offset from UTC

Set Backlight Color: <color/hex>: Sets the tube backlight color. Colors include Red, Green, Blue, Yellow, Magenta, Cyan, White, and any 24 bit hex color (eg FFFFFF)

Set Backlight Brightness: <percentage>: Sets the brightness of the tube backlight

Set Power: <On/Off>: Turns the clock on or off

Set Display Mode: <Time, Date, Weekday, or Alarm>: Sets the display to show different clock functions

Display Lamp Test: Tests all IN12 display Elements. This should look like a giant blur on each digit

Set Display Brightness: <percent>: Sets the IN12 display to the entered brightness as a percentage

Set Time Format: <24/AM_PM>: Sets time display format. This only impacts tube display, not USB user interface

Alarm Status?: Prints clock alarm settings

Set Alarm: <hh>:<mm>:<ss>: Sets the alarm time. (Must be 24 hr time)

Arm Alarm: <Arm/Disarm>: Arms or disarms the clock alarm

IN-12 Status?: Prints status of devices on IN-12 Carrier Board, as well as carrier SPD data. This includes tube elapsed time counter.

# 6. Project History

Git Repository: https://github.com/drewsum/Nixie_Clock

## A. Rev A

The first incarnation of this project was completed in October of 2017. It ran on a PIC16LF1519 8-bit microcontroller, supporting IN-14 tubes. It featured a 1.65F supercapacitor stack backup circuit (charge pump, LDO) that allowed the PIC16 to continue timekeeping for up to a day after being unplugged without a battery. The PIC16 utilized extensive sleep modes and low power techniques to continue operation with this supercapacitor stack. This design was only able to display and track time, it could not track date or weekday, and did not have an alarm. Time was tracked directly in RAM as standard C variables. Due to the low pin count on the PIC16, binary coded decimal encoding (and hardware decoding) was used to control all the multiplexing signals. Like the rev B design, the rev A was constructed using two printed circuit boards. The top circuit board was entirely passive, only hosting the tubes. All power, processing and multiplexing was done on the lower PCB. There was no USB port, telemetry, or debug functionality. Also like the rev B design, the rev A featured an input protection circuit for under and overvoltage lockout, and reverse polarity protection. It sports a similar, yet less refined boost converter design to the rev B project. Due to the extreme step-up ratio required to boost the +24V input to the +180V strike voltage, the boost converter is a hybrid topology, with a standard non-synchronous boost design, but with a diode/capacitor voltage doubler added to the switch node. The regulator regulates to +90V, and the diode/capacitor double doubles this to the +180V strike voltage. Both voltages are needed to properly drive nixie tubes. The upper and lower PCBs are connected through three different connectors, which makes mating the two PCBs difficult within the enclosure.

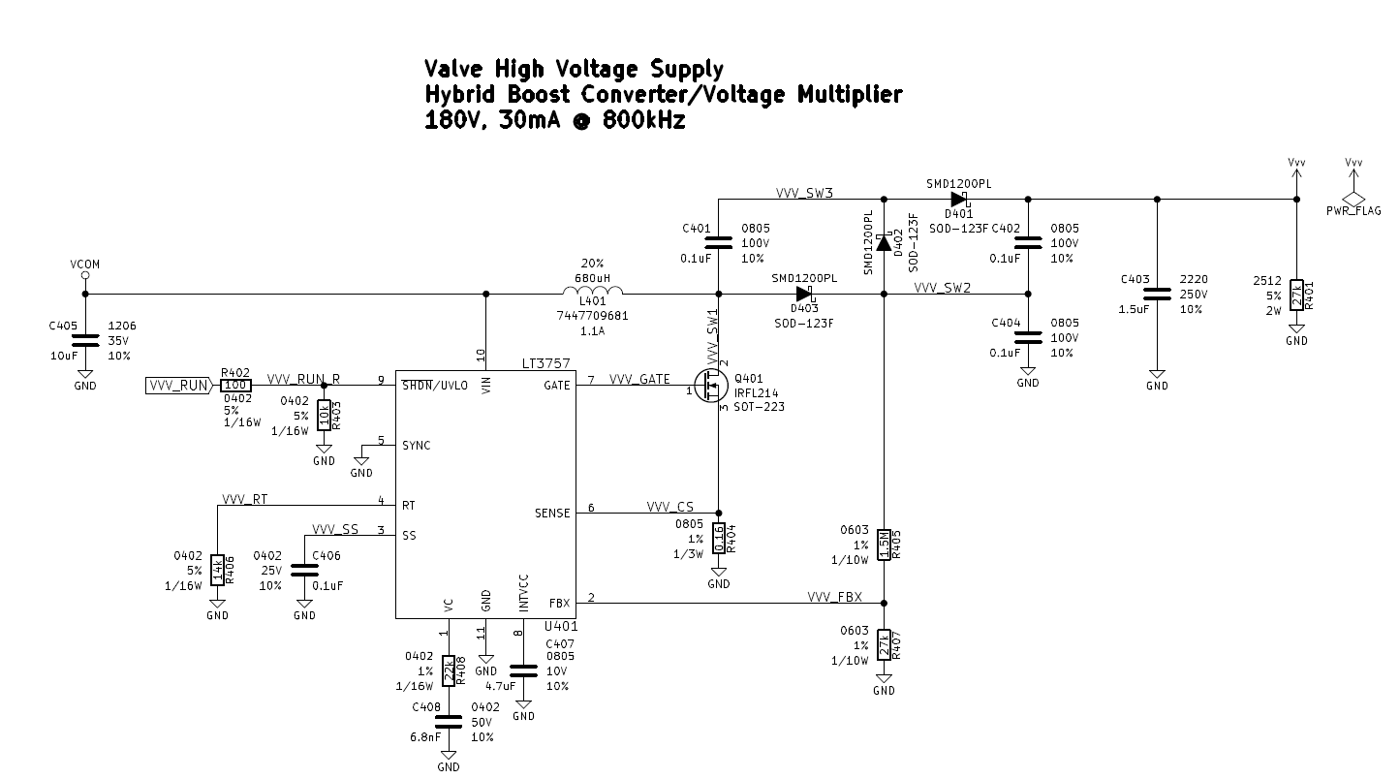
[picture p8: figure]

Figure 3: Rev A Boost Converter

## T. Rev B

The rev B design has many similar elements to rev A, but has been extensively redesigned. The original boost converter remains, although with more refined component selection. This design runs on a PIC32MZ EF 200MHz 32-bit microcontroller, which is extremely, extremely overkill. It is designed to be much more flexible from a user-interface and functionality standpoint, as well as from a configuration standpoint. Power and processing live on the lower PCB, but multiplexing and user interface support live on the upper PCB. This means that multiple tube types can be supported by swapping out the upper PCB. A single tall stacking height PMC connector bridges the two PCBs. The lower control PCB “core board” is able to detect which kinds of tubes and features are installed on the upper PCB “carrier board.”

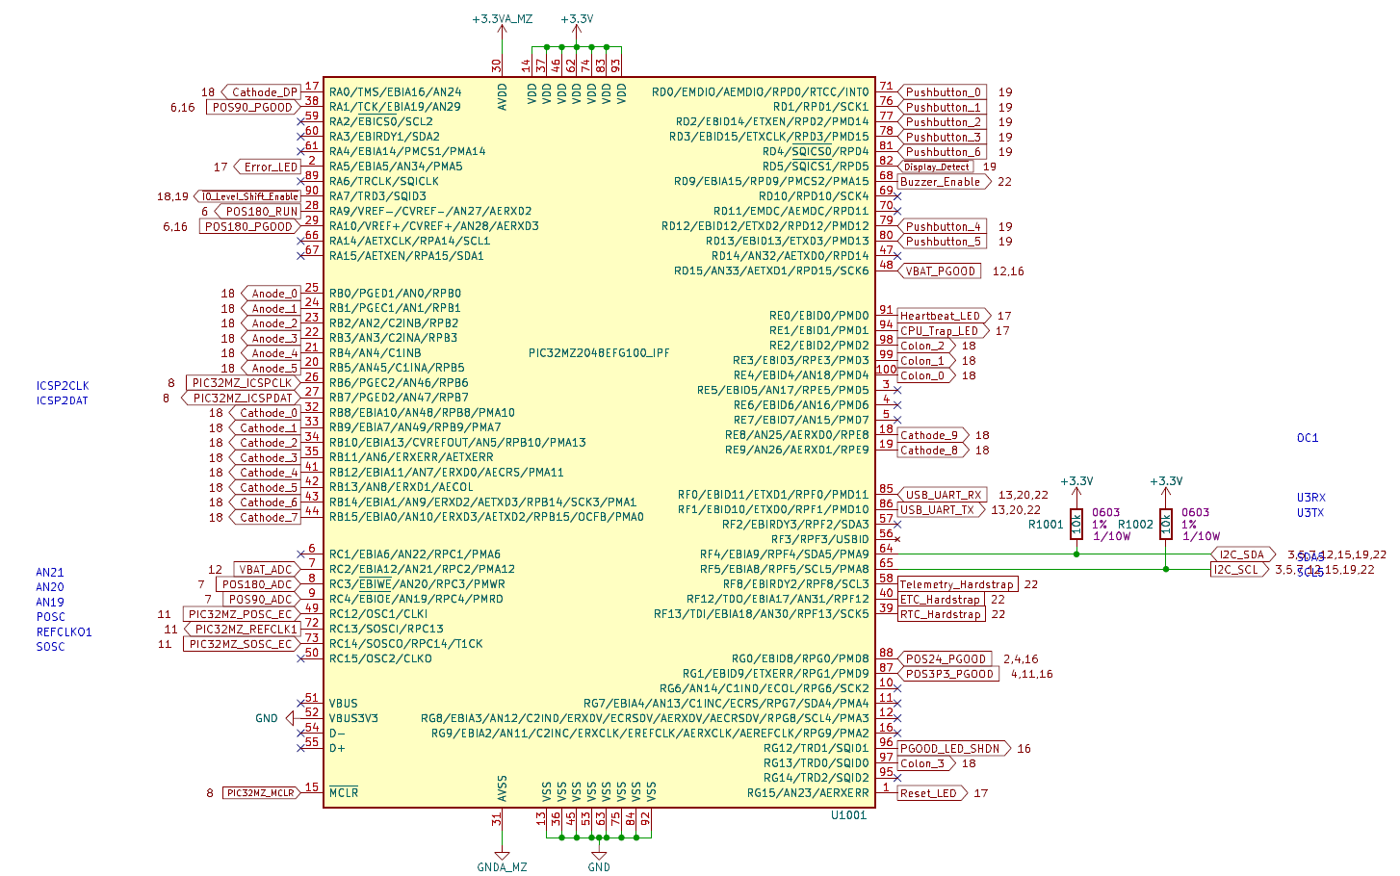
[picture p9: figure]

Figure 4: Rev B Microcontroller

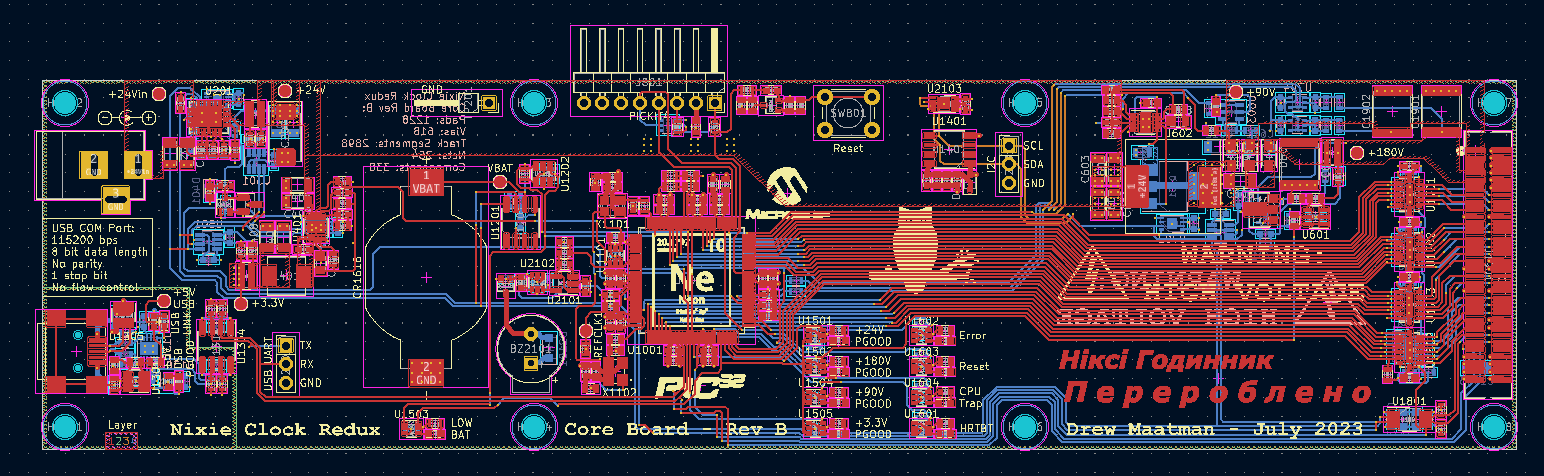
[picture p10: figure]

Figure 5: Rev B Lower/Core PCB

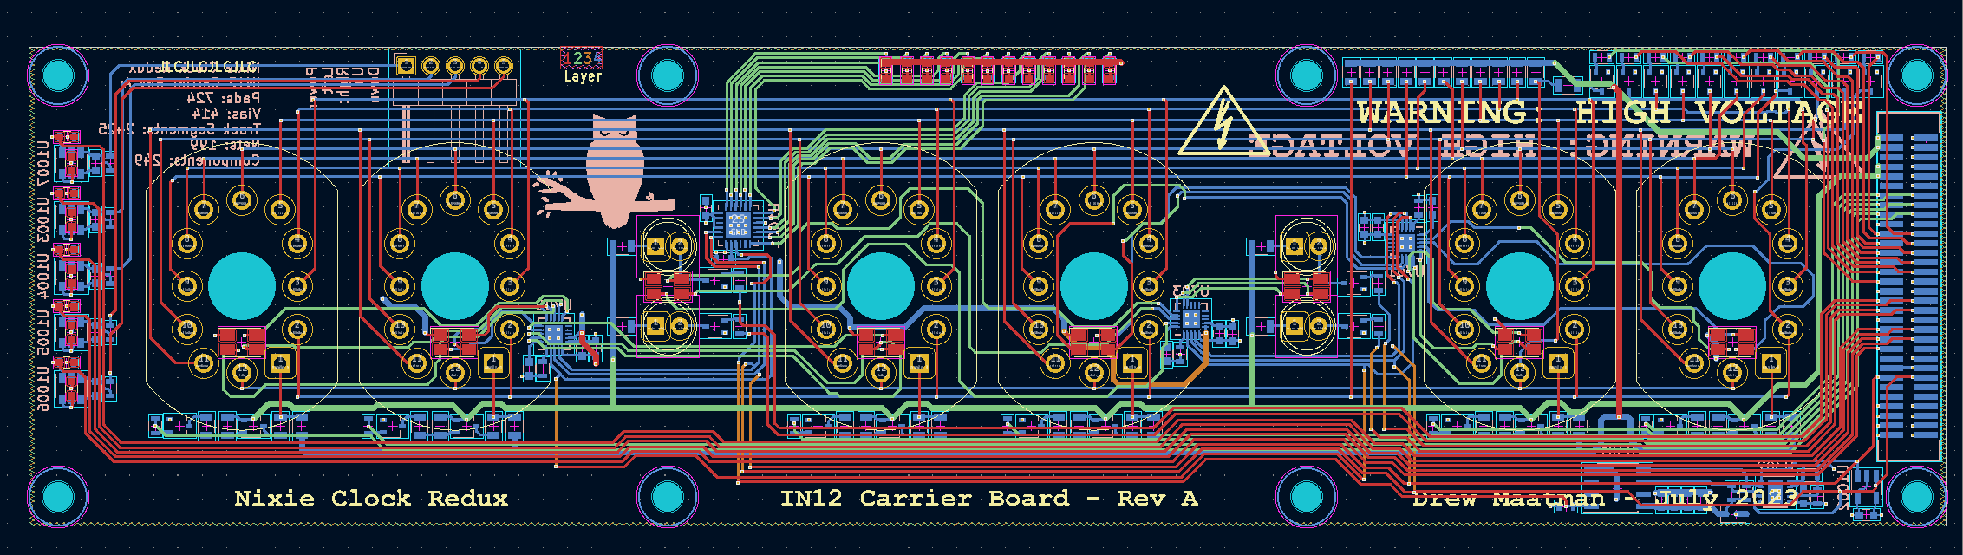
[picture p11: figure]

Figure 6: Rev B Upper/Carrier PCB (IN-12 Variant)

# 7. Nixie Tube Working Principle

## A. (Not) a Vacuum Tube

Despite appearing like a vacuum tube, Nixie tubes do not contain a vacuum. Sealed inside the tube is neon gas. This is what gives nixie tubes their orange glow when energized. Some more modern tubes also contain a mixture of mercury, which reduces sputtering – see below. This mercury creates a small blueish glow along the cathode in addition to the orange glow due to neon ionization.

## U. Ionization

Nixie tubes have anodes and cathodes, much like modern PN junction semiconductors. When a high voltage is applied from anode to cathode, electrons are stripped from the valence electron bands of the neon gas inside the tube. When a neon atom is stripped of an electron, it becomes a positive charged ion (ionization), which wants to flow towards the cathode – which is at a lower voltage potential. This is similar in principle to a neon tube sign. When these neon atoms hit the cathode, metal atoms are displaced from the cathode into the space within the tube (called sputtering). Electrons are attracted to the positively charged anode. This movement of ions and electrons is what forms an electric current, and allows charge to flow. This electric current is relatively small (~2.5mA). The light within a nixie tube is emitted through both ionization and sputtering.

## V. Common Anode

Much like some LED common-anode seven segment displays, most Nixie tubes have a single anode, constructed as a mesh, which has the high voltage applied to it through a single current limiting anode resistor. To illuminate a number within the tube, one of many cathodes is grounded, or driven to 0V. This creates the voltage potential needed for neon ionization. Most tubes have 10 cathodes and a single anode – the 10 cathodes correspond to the digits 0 to 9. The cathodes are physically arranged front to back within the tube, so that when any cathode is illuminated, they appear in the same location. Some tubes also have a decimal point cathode, which typically is rated to a much lower current. Other more rare tubes have common electrical symbols such as Ω or µ, since Nixie tubes were used within electrical measurement equipment. IN-12 tubes have their cathodes in the order 3 8 9 4 0 5 7 2 6 1. The cathodes are arranged in this manner to minimize more forward cathodes from obscuring the rear cathodes. The digit 5 is an upside down 2 to reduce unique materials, per the Soviet Union’s cost saving design philosophy.

## W. Cold Cathode

Nixie tubes do not heat up very much. There is no heating element within the tube, unlike most vacuum tubes electrical engineers would be familiar with. Other graphical tubes, such as VFDs, do require a heating element. A lack of a heater does not mean they are efficient, though. IN-12 nixie tubes dissipate approximately 0.36W each when a single cathode is lit.

## X. Strike Voltage

To light a nixie tube, a high voltage must be applied. This first voltage application, and the voltage drop developed across the tube, is known as the strike voltage. This clock design utilizes a strike voltage of +180V, which is the output of an internal boost converter on one of two internal printed circuit boards. This high DC voltage gives the neon atom valence electrons the motivation they need to be stripped from the neon atoms, turning the atoms into neon ions. The nixie tube sustains the strike voltage across its anode to the selected grounded cathode for about 100µs before the neon gas is sufficiently ionized to begin conduction. There is no current flow during this time.

## Y. Sustain Voltage

After about 100µs of strike voltage application, the voltage across the tube drops to about 140V. This is called the sustain voltage. Conduction begins and the cathode begins to glow. The tube will hold the sustain voltage across it if the cathode is grounded and the anode voltage (pre-resistor) is sustained.

## Z. Negative Resistance

The decrease in anode to cathode voltage drop from strike voltage to sustain voltage, and how this corresponds to an increase in current draw (from 0mA to around 2.5mA when conduction occurs) gives a nixie tube a negative resistance characteristic, since voltage drop is reducing while current draw is increased.

## AA. Multiplexing

Only one nixie tube within this design is on at a time. This is because the circuitry required to have all tubes on at the same time would be much more complex and require a set of 10 or 11 high voltage bipolar transistors for each tube, which is not economical or efficient. In addition, nixie tubes have a limited lifespan. Having all the tubes on constantly would wear down the lifetime more quickly.

Instead, a multiplexing technique is used. Each tube has its own anode driven individually, and the cathodes for each tube are all tied together. To turn one number in one tube on, the anode for that tube has +180V applied to it with a PNP transistor, and the shared cathode signal for the numeral desired within that tube is grounded with an NPN transistor.

The timing for multiplexing is carefully controlled such that all 6 tubes (and two sets of neon bulb colons) are cycled through in 1/60th of a second, to give a display refresh rate of 60Hz. The changes are too fast for the human eye to distinguish; the human brain blends the light for all tubes together, so that all digits appear to be on at the same time.

The timing is generated with hardware timers within the microcontroller (brains of the clock), and the code is interrupt based, meaning that the timing is deterministic, accurate and exact.

## BB. Anti-Ghosting

Nixie tubes are highly capacitive. Because the anodes and cathodes are driven with either an NPN or PNP transistor (open-collector or open-emitter instead of a push-pull or totem pole circuit topology), when a tube is energized, it holds residual charge on the anodes and cathodes (instead of being discharged to ground). If this charge has nowhere to bleed to, it will move to the subsequent tube that is next in the multiplexing sequence when voltage is applied. This would cause adjacent tubes to appear to have the same numerals falsely illuminated. This phenomenon is called ghosting. The cleanest approach to mitigating ghosting is to terminate the anode and cathode signals that are shared across all tubes together through a high value resistor. This “termination” connection is then tied to half of the strike voltage, or +90V. This is a low enough voltage to not energize the tube, but high enough to minimize switching losses when turning tubes on and off. The boost converter which generates the +180V strike voltage was also carefully designed to break out half of the output voltage magnitude for this termination level. This is a similar working principle to termination in DDR4 memory in modern computer design, just on a roughly ~100x voltage magnitude scale, and much, much slower in frequency.

# 8. Nixie Tube History

## A. From Wikipedia:

“Nixie tubes were invented by David Hagelbarger. The early Nixie displays were made by a small vacuum tube manufacturer called Haydu Brothers Laboratories, and introduced in 1955 by Burroughs Corporation, who purchased Haydu. The name Nixie was derived by Burroughs from "NIX I", an abbreviation of "Numeric Indicator eXperimental No. 1", although this may have been a backronym designed to justify the evocation of the mythical creature with this name. Hundreds of variations of this design were manufactured by many firms, from the 1950s until the 1990s. The Burroughs Corporation introduced "Nixie" and owned the name Nixie as a trademark. Nixie-like displays made by other firms had trademarked names including Digitron, Inditron and Numicator. A proper generic term is cold cathode neon readout tube, though the phrase Nixie tube quickly entered the vernacular as a generic name.”

## CC. In Soviet Russia:

From “Medium.com”:

Although the first mass-market nixie tubes were produced in the United States and created by the Hungarian Haydu Brothers, who were proudly outspoken of their hatred of the Soviet Union and their occupation of their home country: the Nixie tubes were most famously known as a Soviet technology. The Soviet Union produced more Nixie Tubes than any country in the world, they produced and used the technology up until their dissolution in 1991. As could be expected, the Soviet Union never paid any royalties to the Haydu brothers or Burroughs Corporation.

While the stealing of the Nixie Tube technology can be best described as a perfect example of copyright infringement, it is interesting to see how the Soviets modified the Nixie Tubes. As a perfect example of the Soviet school of thought, the “2” and “5” metal inserts were the exact same form — just flipped to their respective orientation. The Soviets valued simplicity and low production cost, opting for volume. The IN-18 nixie tube or biggie nixie, one of the most popular versions of the Soviet produced Nixie Tube, made use of this cost saving measure and many others.

For more than 30 years the Soviets used nixie tubes as an alternative to the new American LEDs for military and industry concerns. While the United States was able to move on to more cost effective and new technologies, the Soviet Union was stuck in the early 1960s in digital number display technology. For this reason, Nixie Tubes are abundant in ex-Soviet states.

## DD. IN-12A/B:

The IN-12 tube design dates back to the 1980s in the USSR. The datasheets available online are dated 1988. The IN-12 is offered in an “A” variant, which does not include a decimal point cathode, as well as a “B” variant, which does include a decimal point cathode. They are otherwise interchangeable.

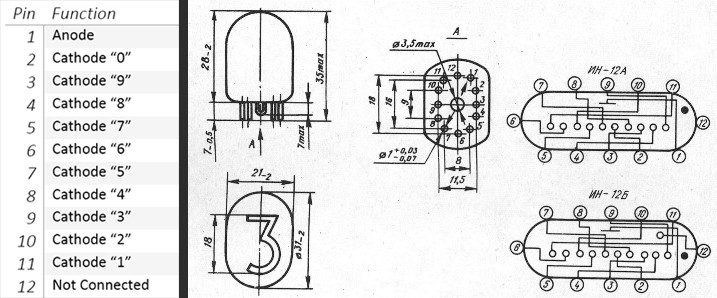
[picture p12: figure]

Figure 7: IN-12A/B Pinout

2 | Page IN-12 Variant

Nixie Clock Redux

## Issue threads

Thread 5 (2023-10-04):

Known Redux Core Board Issues/ECOs

drewsum, 2023-10-04:
- Heartbeat LED was intended to be PWM driven for breathing effect, but was driven by a non-OCx PPS compatible pin, so heartbeat LED can only be toggled (firmware toggles once per second)
- ~IO_Level_Shift_Enable net was tied to I2C carrier buffer (U1801, TCA9803) but should have been inverted. Therefore, either the I2C buffer or parallel buffers (U1700-U1802) can be active at once, not all together. The net trace was cut between U1801 and U1702 on top layer, and R1802.2 was grounded with modwire to always enable U1700-U1802. I2C buffer (U1803) is what can be toggled by firmware. U1700-U1802 will always be enabled.

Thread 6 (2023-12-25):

Pricing

drewsum, 2023-12-25:
| Item | Price for Qty:3 | Price/Unit |
|---|---|---|
| Digi-Key Cart | TBD | TBD |
| IN-12 Tubes | TBD | TBD |
| IN-3 Tubes | TBD | TBD |
| Acrylic Plates | TBD | TBD |
| Wood Case | TBD | TBD |

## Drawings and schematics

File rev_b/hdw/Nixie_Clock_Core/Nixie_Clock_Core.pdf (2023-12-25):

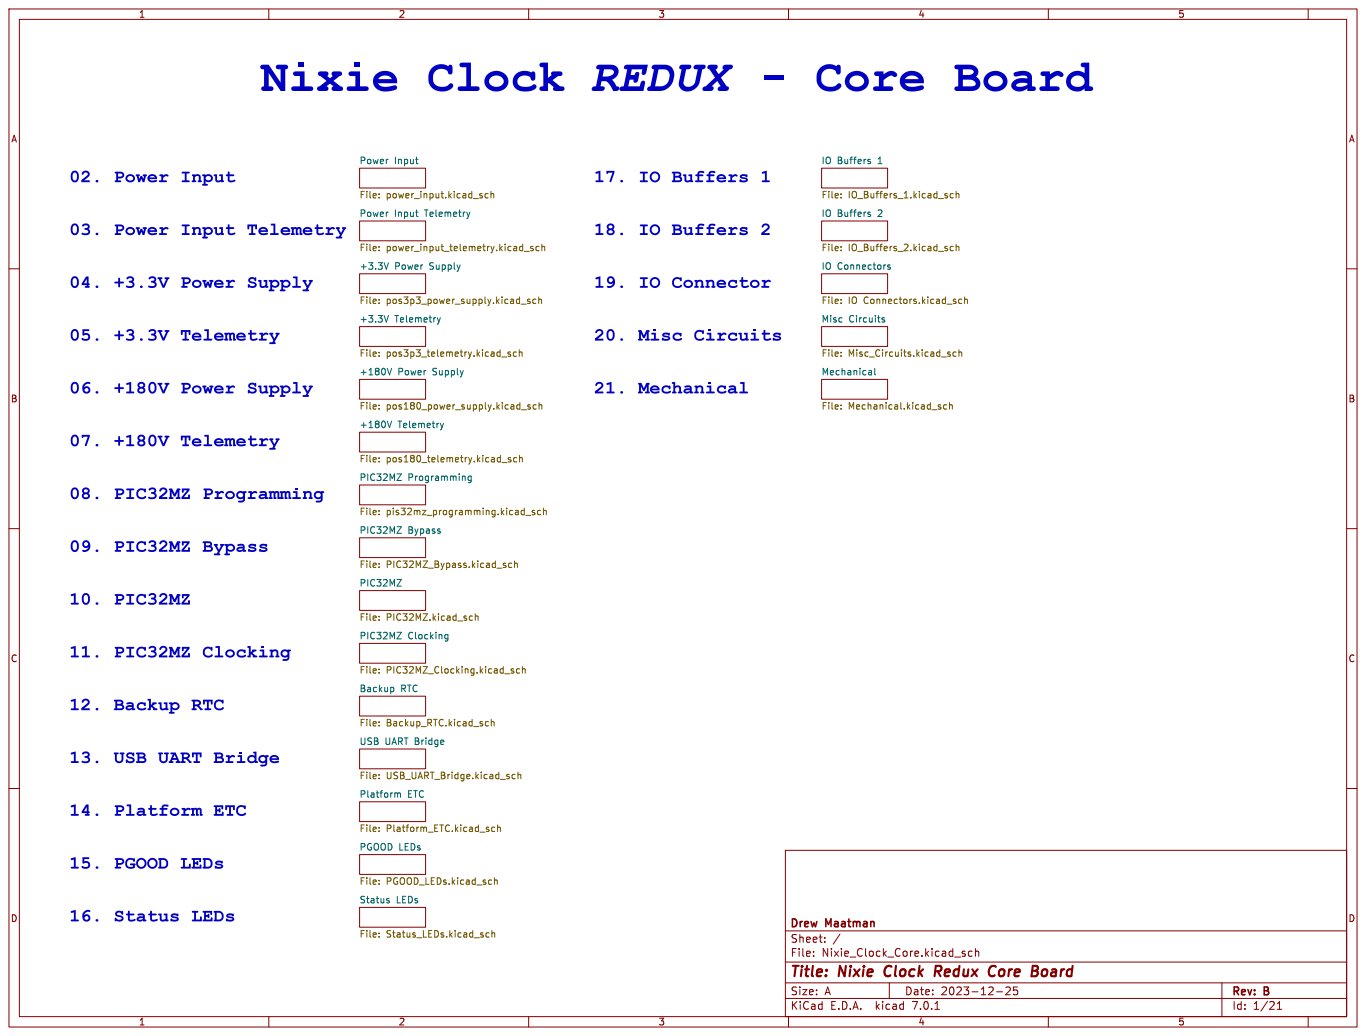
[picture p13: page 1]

+180V Telemetry File: pos180_telemetry.kicad_sch Power Input Telemetry File: power_input_telemetry.kicad_sch PIC32MZ

IO Buffers 2 File: IO_Buffers_2.kicad_sch +3.3V Telemetry File: pos3p3_telemetry.kicad_sch PIC32MZ Bypass File: PIC32MZ_Bypass.kicad_sch +3.3V Power Supply File: pos3p3_power_supply.kicad_sch PIC32MZ Programming File: pis32mz_programming.kicad_sch +180V Power Supply File: pos180_power_supply.kicad_sch

IO Connectors File: IO Connectors.kicad_sch Mechanical File: Mechanical.kicad_sch

Id: 1/21 Title: Nixie Clock Redux Core Board

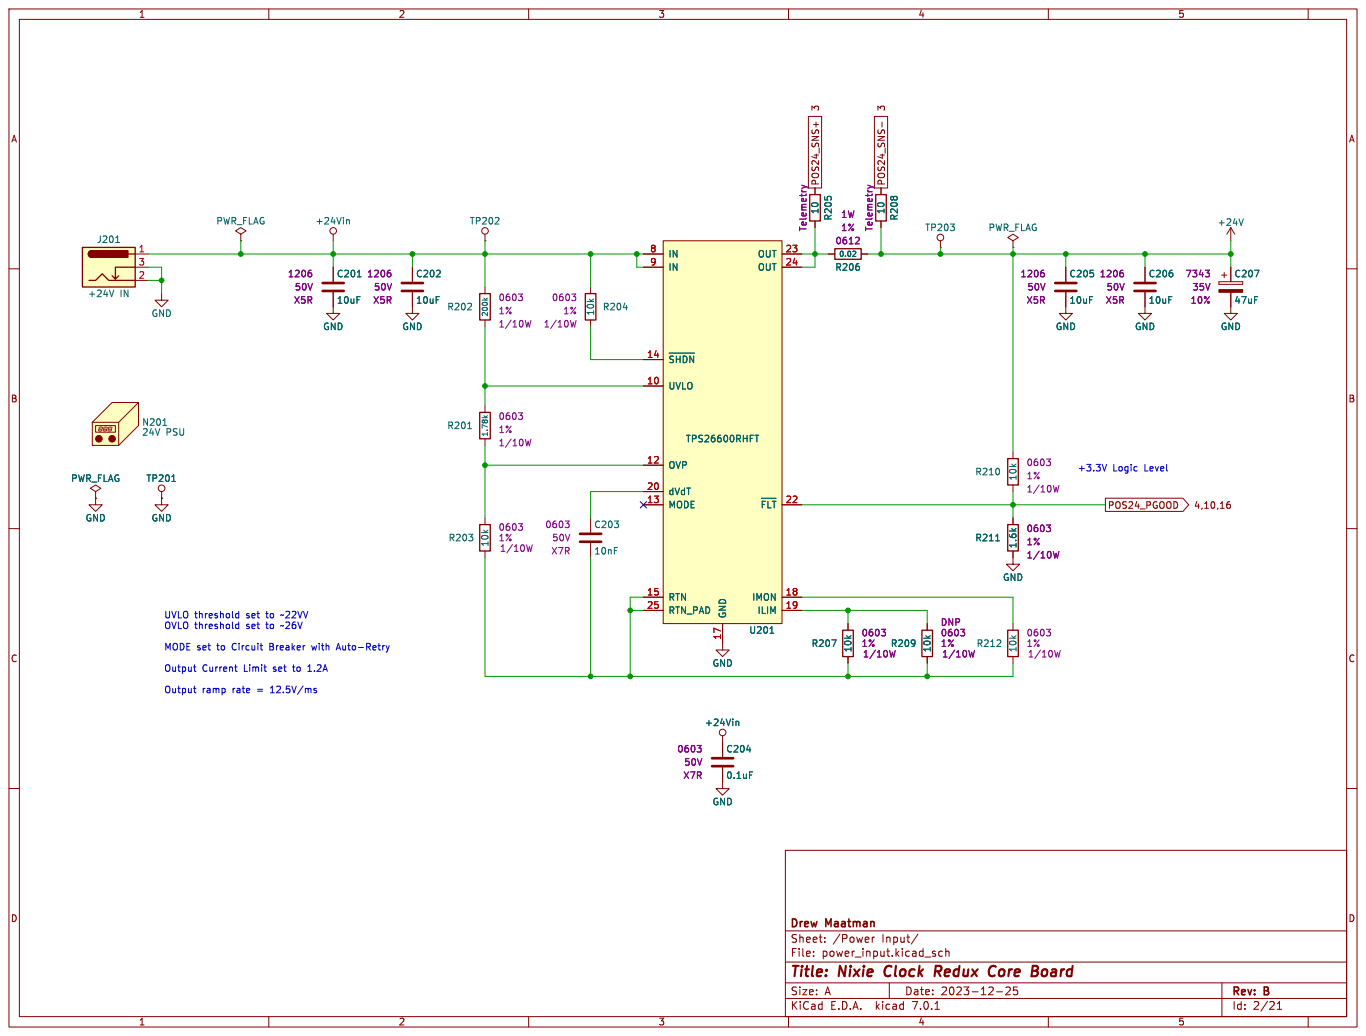
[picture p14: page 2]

Id: 2/21 Title: Nixie Clock Redux Core Board

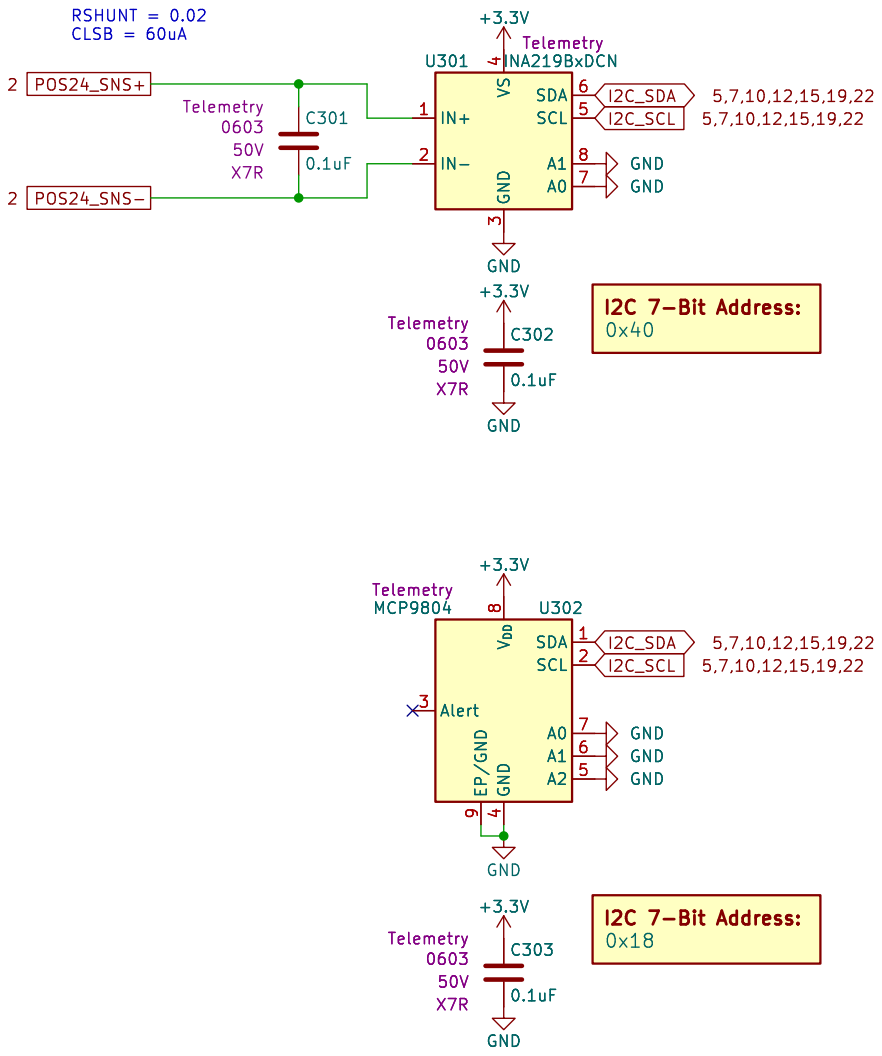
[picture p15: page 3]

Id: 3/21 Title: Nixie Clock Redux Core Board

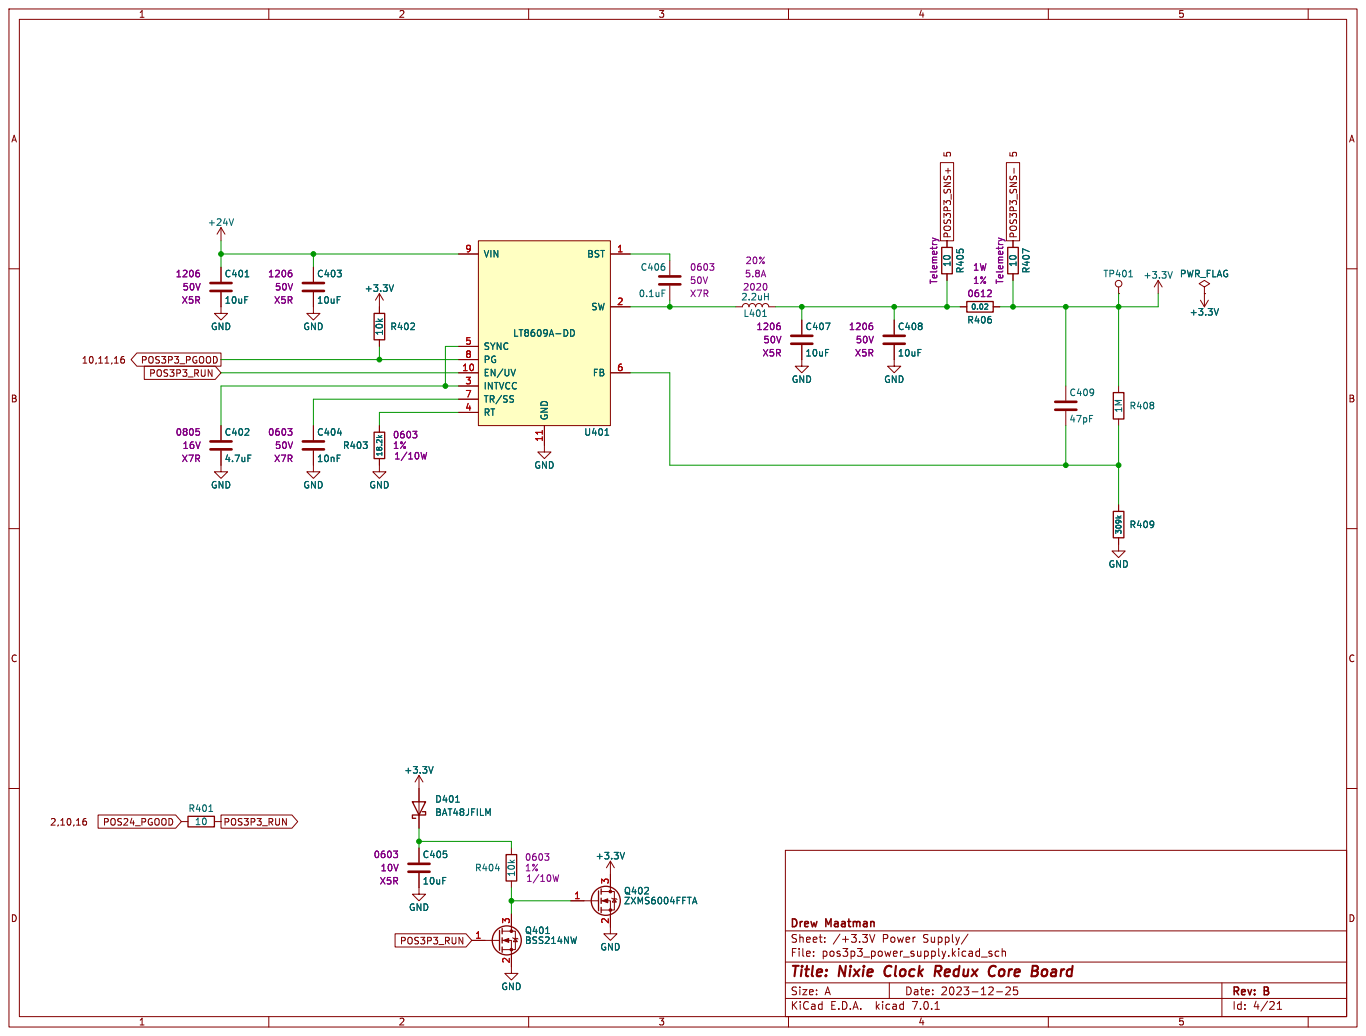
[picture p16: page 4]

Id: 4/21 Title: Nixie Clock Redux Core Board

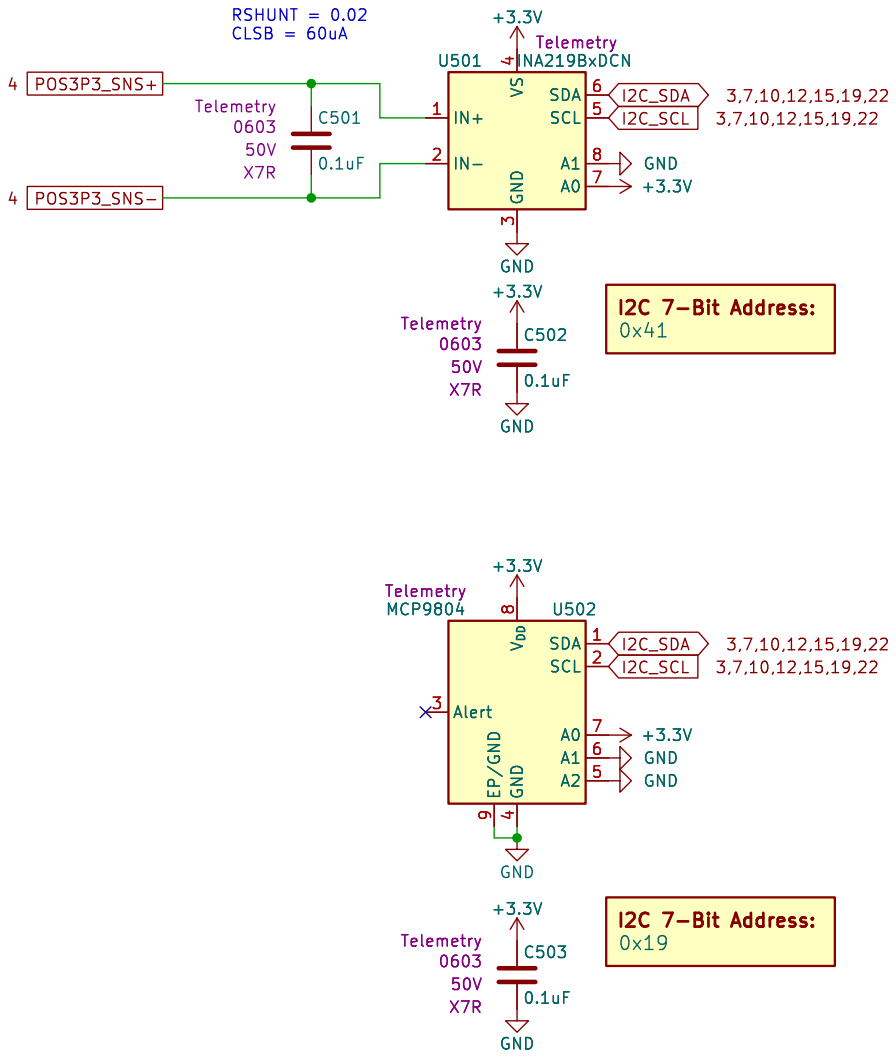
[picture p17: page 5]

4 SCL 5 SDA 6 A0 7 A1 8 +3.3V GND GND

Id: 5/21 Title: Nixie Clock Redux Core Board

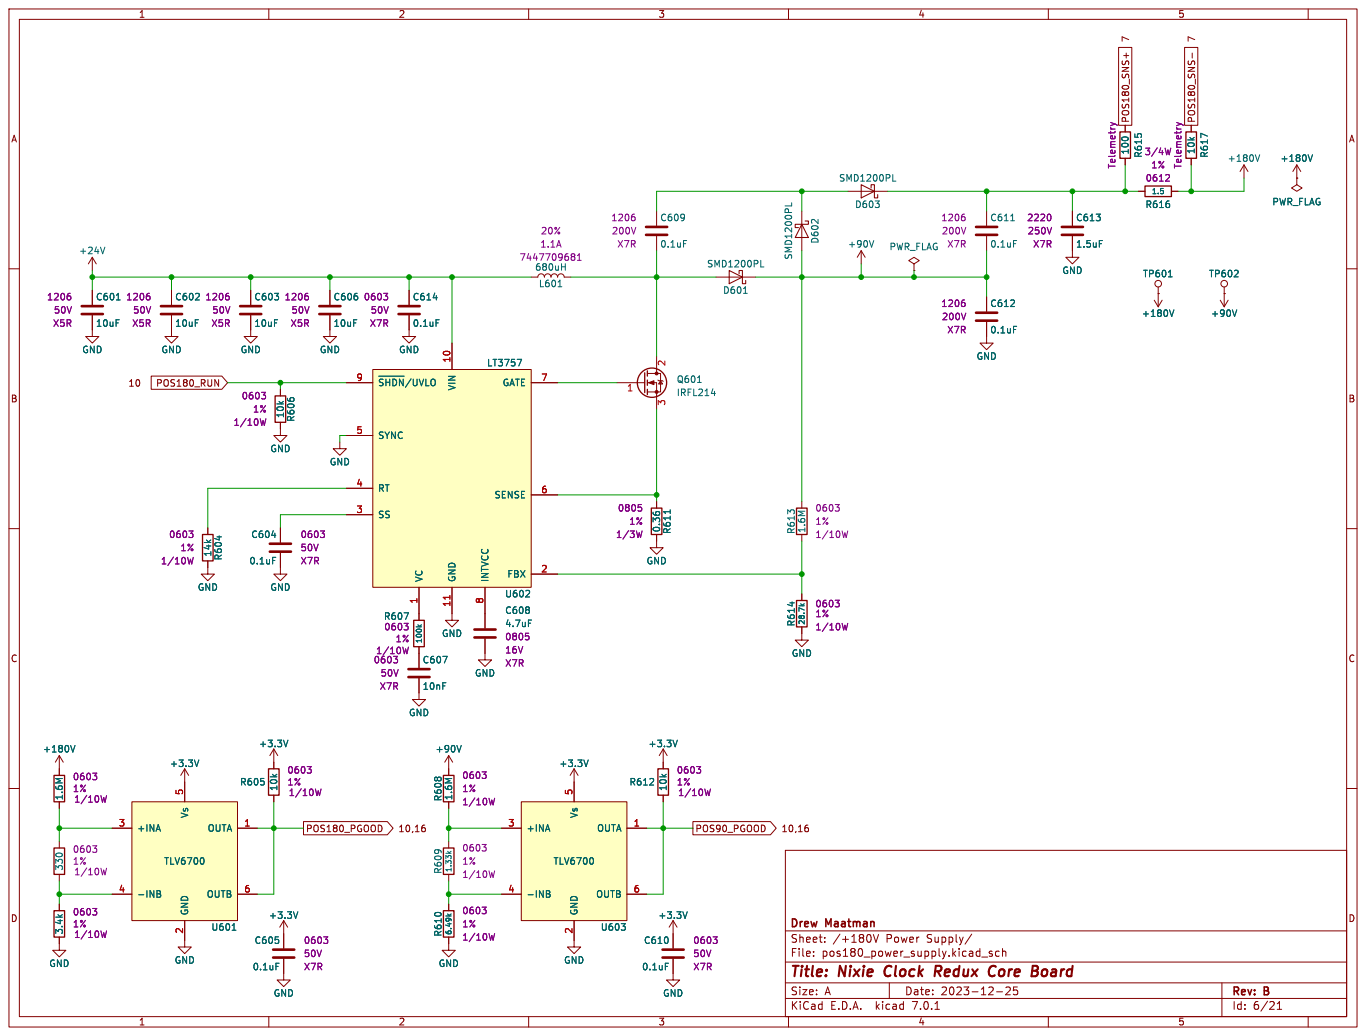
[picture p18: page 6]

1 VIN 10 GND 11 FBX 2 SS 3 RT 4 SYNC 5 SENSE 6 GATE 7 INTVCC

Id: 6/21 Title: Nixie Clock Redux Core Board

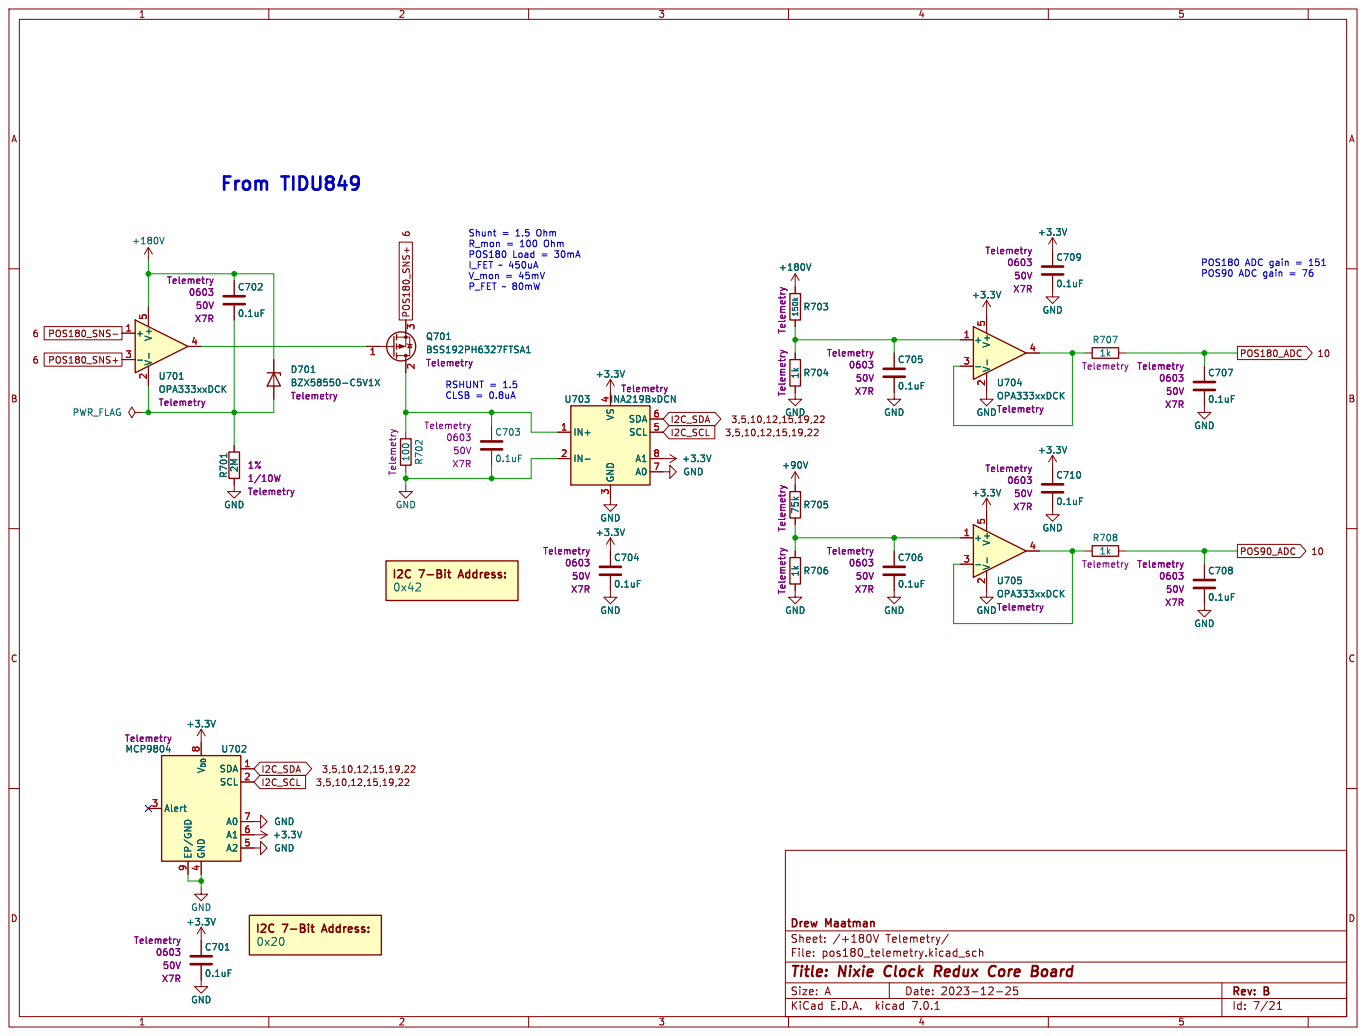
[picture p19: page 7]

POS180 ADC gain = 151 POS90 ADC gain = 76 GND R701 2M

4 SCL 5 SDA 6 A0 7 A1 8 GND GND

Id: 7/21 Title: Nixie Clock Redux Core Board

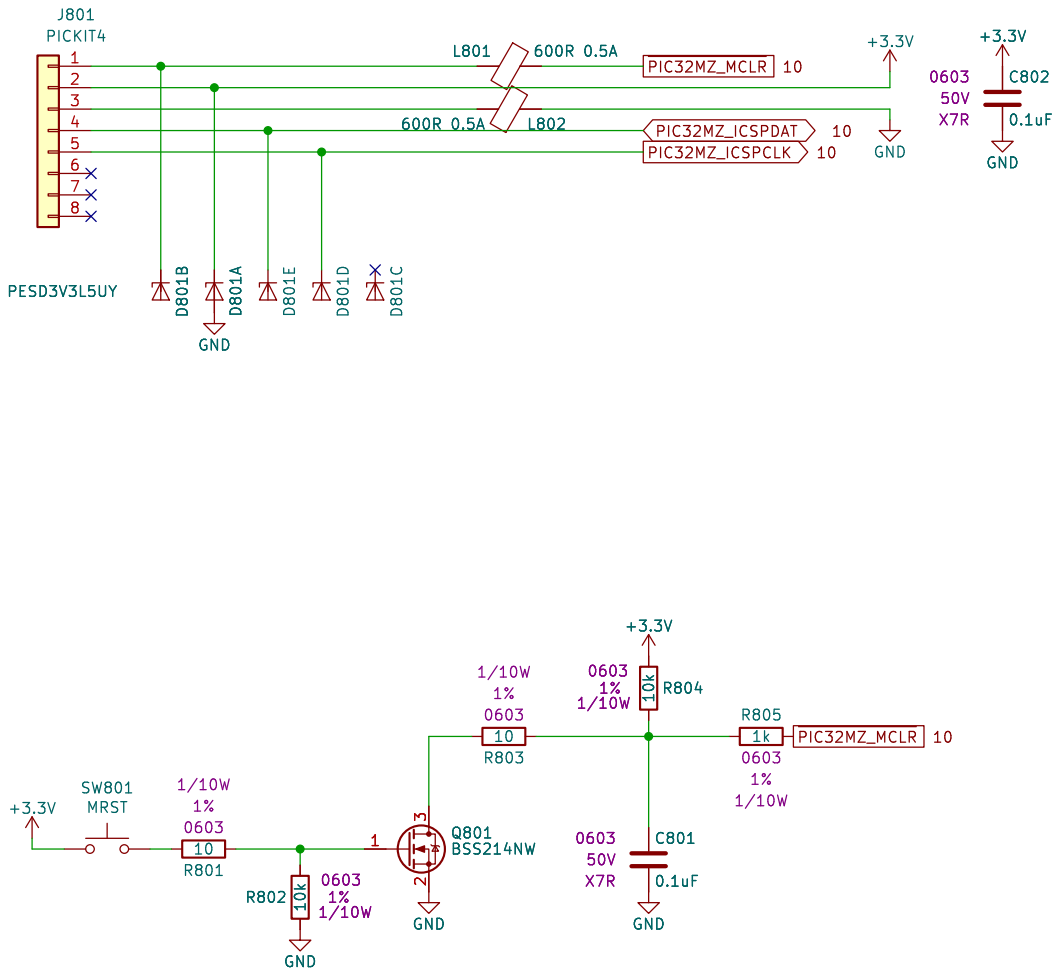
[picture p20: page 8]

Id: 8/21 Title: Nixie Clock Redux Core Board

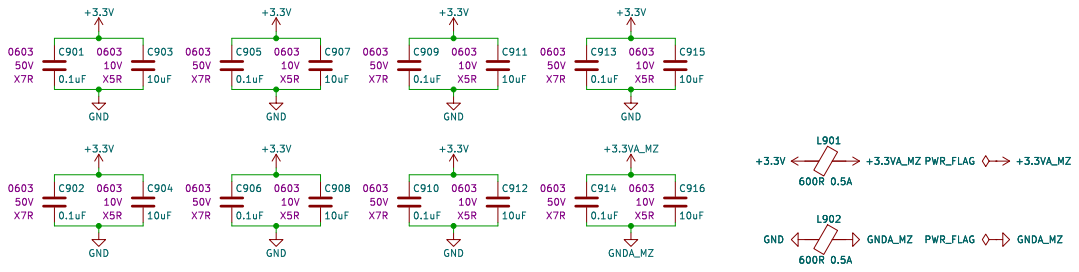
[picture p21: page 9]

Id: 9/21 Title: Nixie Clock Redux Core Board

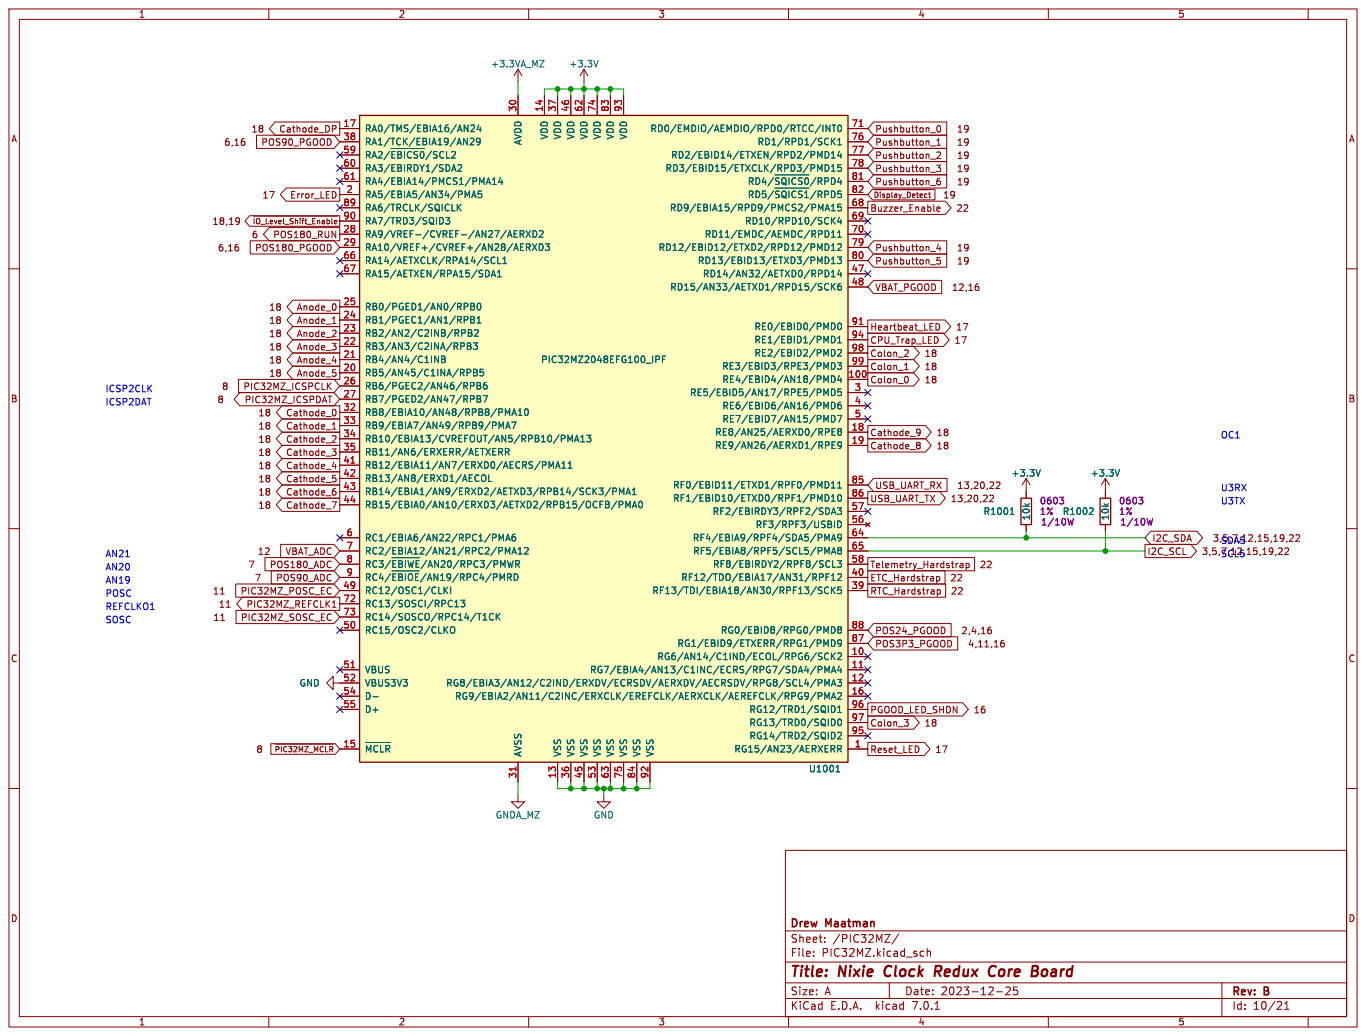
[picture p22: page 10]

Id: 10/21 Title: Nixie Clock Redux Core Board

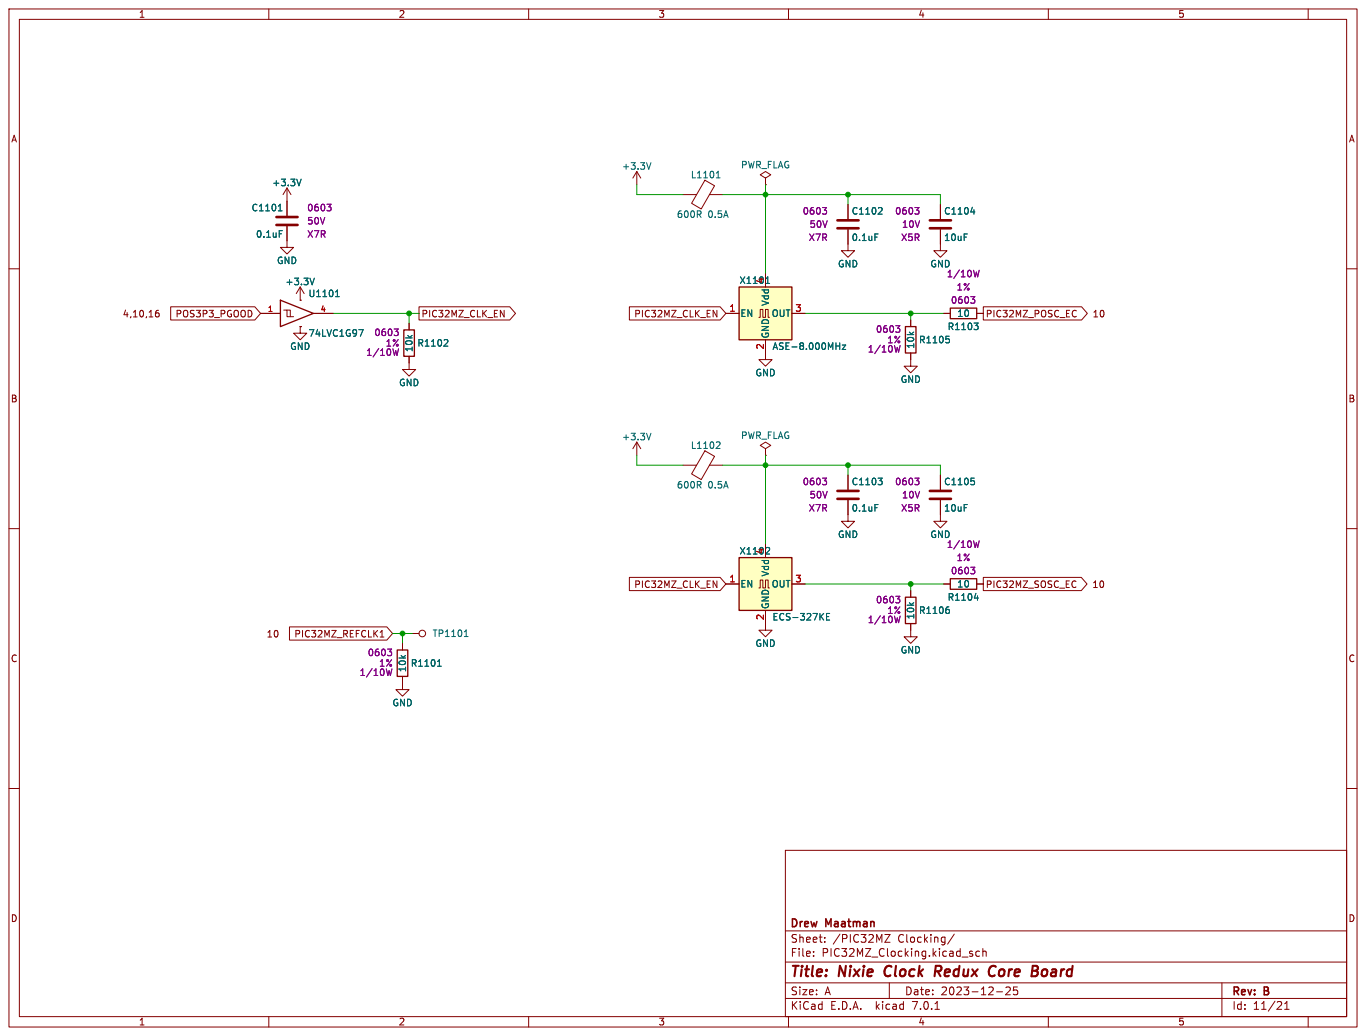
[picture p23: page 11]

2 OUT 3 Vdd X11024 ECS-327KE GND GND GND

Id: 11/21 Title: Nixie Clock Redux Core Board

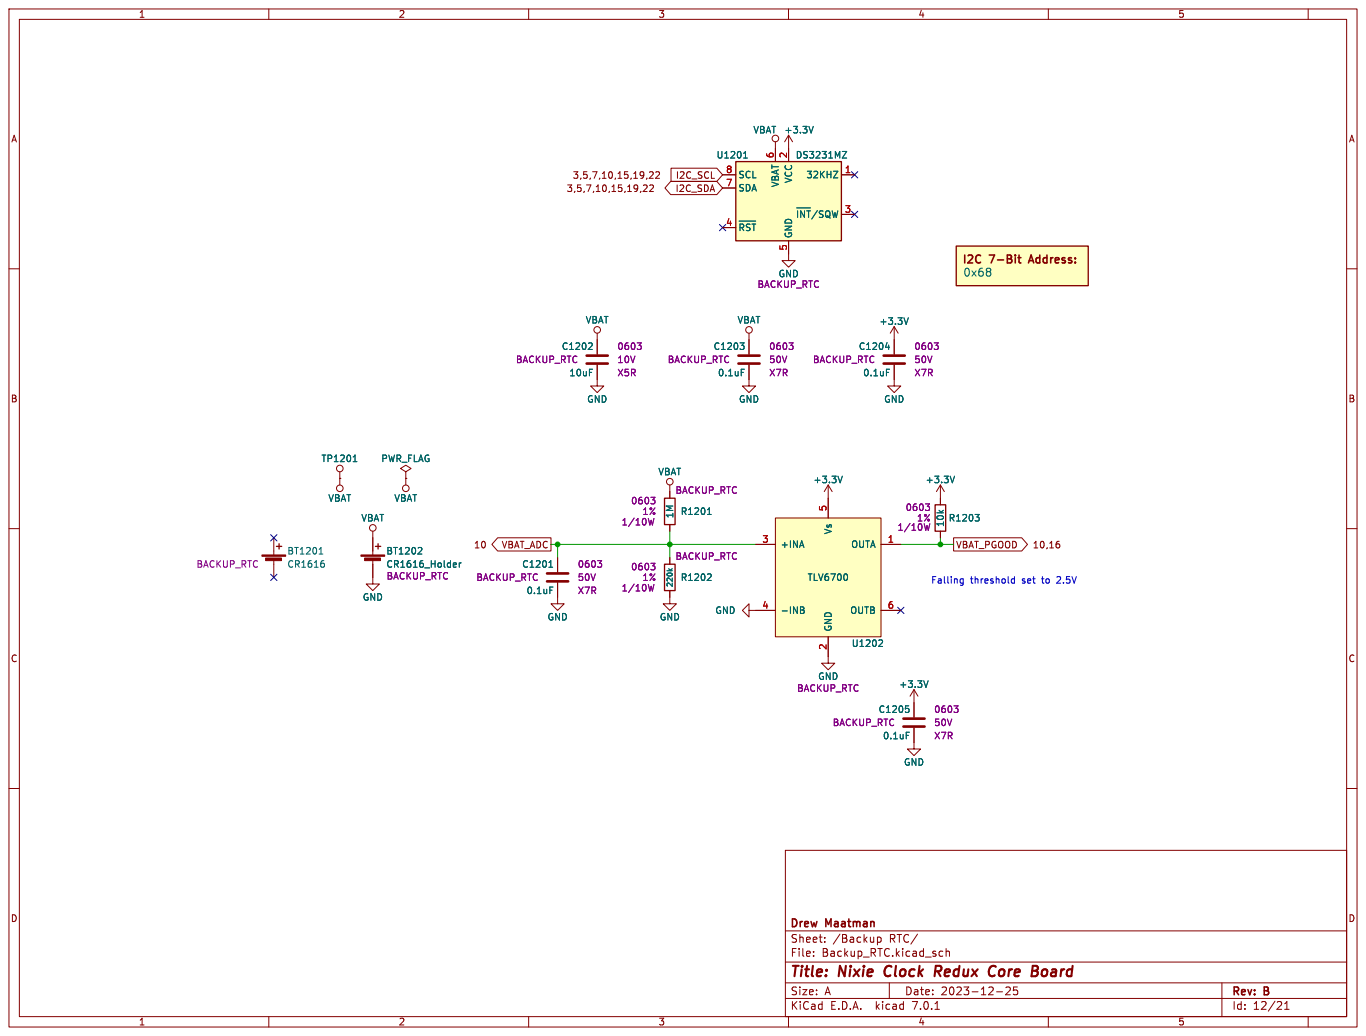
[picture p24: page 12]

Id: 12/21 Title: Nixie Clock Redux Core Board


600R 0.5A Baud Rate: Data Length: Flow Control:

Stop Bits: USB Virtual COM Port Settings: 115200 bps 8 bit None

Id: 13/21 Title: Nixie Clock Redux Core Board


Id: 15/21 Title: Nixie Clock Redux Core Board


Id: 16/21 Title: Nixie Clock Redux Core Board


Id: 17/21 Title: Nixie Clock Redux Core Board


Id: 18/21 Title: Nixie Clock Redux Core Board


4 EN 5 SDAB 6 SCLB 7 VCCB U1801 8TCA9803 R1803 10K GND

4 EN 5 SDAB 6 SCLB 7 VCCB

Id: 19/21 Title: Nixie Clock Redux Core Board


Id: 20/21 Title: Nixie Clock Redux Core Board


Id: 21/21 Title: Nixie Clock Redux Core Board


Id: 22/21 Title: Nixie Clock Redux Core Board

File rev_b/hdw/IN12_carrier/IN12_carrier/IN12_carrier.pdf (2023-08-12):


IO Connector File: IO_Connector.kicad_sch Elapsed Time Counter File: Elapsed_Time_Counter.kicad_sch

IN12 Tubes File: IN12_Tubes.kicad_sch Anode Drive File: Anode_Drive.kicad_sch

LED Driver File: LED_Driver.kicad_sch Cathode Drive File: Cathode_Drive.kicad_sch


GND GND


4 Enable 5 READY 6 SDAIN 7 SDAOUT 8 SCLOUT 9

4 Enable 5 READY 6 SDAIN 7 SDAOUT 8 SCLOUT 9 GND








5 SYNC 6 +3.3V U1003 AT42QT1010-TSHR OUT 1 VSS


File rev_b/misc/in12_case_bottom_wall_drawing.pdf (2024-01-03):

30.98 ²¹².7 | 206.35 45° 45° | (81")


1 A 2 3 4 5 6 7 8 1 2 3 4 5 6 7 8 FEDCB FEDCBA Dept. Technical reference Created by Approved by Title DWG No. Document type Document status Rev. Date of issue Sheet 1/3/2024 1/1 Bottom Wall Nixie_Clock_Case Patrick Star Drew Maatman 3.18 212.7

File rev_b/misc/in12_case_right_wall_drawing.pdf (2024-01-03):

30.98 ⁵⁶.35 62.7 | 3.18 54 ° 45° | (81")


1 A 2 3 4 5 6 7 8 1 2 3 4 5 6 7 8 FEDCB FEDCBA Dept. Technical reference Created by Approved by Title DWG No. Document type Document status Rev. Date of issue Sheet 1/3/2024 1/1 Right Wall Nixie_Clock_Case Patrick Star Drew Maatman 62.7

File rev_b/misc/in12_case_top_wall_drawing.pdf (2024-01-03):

30.98 ²⁰⁶.35 212.7 45° 54 ° | 3.18 | (81") Ø6.35Ø6.35 Ø6.35Ø6.35 Ø6.35 (41")


1 A 2 3 4 5 6 7 8 1 2 3 4 5 6 7 8 FEDCB FEDCBA Dept. Technical reference Created by Approved by Title DWG No. Document type Document status Rev. Date of issue Sheet 1/3/2024 1/1 Top Wall Nixie_Clock_Case Patrick Star Drew Maatman 212.7

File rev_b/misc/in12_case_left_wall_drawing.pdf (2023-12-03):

3.18 9.35 9.35

2.95 7.95 ⁴⁴


1 A 2 3 4 5 6 7 8 1 2 3 4 5 6 7 8 FEDCB FEDCBA Dept. Technical reference Created by Approved by Title DWG No. Document type Document status Rev. Date of issue Sheet 12/3/2023 1/1 Left Wall Nixie_Clock_Case Patrick Star Drew Maatman 62.7 56.35 45° 54 °

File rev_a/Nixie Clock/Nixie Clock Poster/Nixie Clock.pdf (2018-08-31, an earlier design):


DTM Nixie Tube Clock

Valve High Voltage Supply

Hybrid Boost Converter/Voltage Multiplier

Input power enters from a center-positive DC barrel jack, and is gated by an LTC4365 input monitor and two series N-channel
MOSFETs. Input voltage is a nominal 24V with a 22V undervoltage lockout and 26V overvoltage lockout. Input voltage presence is
sensed by two signals sent to the microcontroller. The input power is fused at 3 Amps and the 24V monitored output voltage is
the common voltage to all power converts, VCOM.

Designed from March of 2016 to October of 2017

Monolithic Buck Switching Regulator
+3.3V, 300mA @ 2.2MHz

5 VOUT 6 FAULT 7 SHDN 8 GND
LTC4365IDDB GND GND

1 OV 2 UV 3 Vin 4 Gate

Common Voltage VCOM is switched by an LT3973, a wide input voltage buck converter with an integrated switch.
This buck converter operates at a blistering 2.2MHz and supplies the main logic voltage rail, VDD/VCC depending on logic technology,
at 300mA. It has a power good signal (VCC_PGOOD) that notifies the microcontroller that the logic rail is up and running when input power
is applied.

This boost converter, controlled by an LT3757, boosts the
24V VCOM bus up to 180VDC, at a lethal 30mA. This high
voltage is needed to "strike" the nixie tubes and neon bulbs
into conduction so that they will illuminate. The controller is
actually regulating a 90V output, which is then doubled
using diodes and high voltage ceramic capacitors. The
output of this supply is the common vacuum voltage rail, VVV

5 SW 6 BOOST 7 BD 8 PG 9 RT 10 GND 11U301

This PIC16LF1519 8-bit microcontroller is the heart
of the control circuitry for the clock. It takes in various
input signals and operates on them To accurately keep
time, multiplex the nixie tubes, and keep track of time
when input power is removed. Its program was written
in the C programming language and compiled and
assembled using Microchip's MP Lab X IDE. The firmware
is uploaded via a pickit 3 programmer in circuit. It

This Binary-Coded-Decimal to Decimal decoder takes in 4-bit BCD parallel
signals from the PIC and decodes them to individual decimal bits to drive
the 10 low side switches that control the multiplexed cathodes of the
Nixie tubes. Essentially this allows four digital signals from the PIC to control
10 high voltage signals from the Nixie tubes, selecting which numeral to display
in any of the six digits on the clock. BCD and BCO encoding for the main display
signals was chosen to free up other I/O signals from the PIC for other purposes.

This LT6700-1 window comparator monitors the VVV tube
supply voltage (+180V) and presents a digital signal to the
PIC representing if the output is in regulation or not. The
digital signal "VVV_PGOOD" will be high if the VVV rail is
within 10% of 180 Volts. If it is not, the PIC will enter an
error state since something is wrong with the boost supply
circuit above, or the supply is starting up, so the PIC will
wait to start displaying the time. Surpisingly, with 1% tolerance
resistors, this window comparator is fairly accurate even when
monitoring such a high voltage.

number is chosen since it can easily be divided down with a pre-scalar in the pic to an
accurate and stable 1Hz signal, which is used for timekeeping and flashing the colons. This
part is physically built using a precisely cut piece of quartz, which vibrates electrically at a
fundamental frequency of 32.768kHz. This weak high impedance signal is buffered within
the part to drive a stronger signal to the PIC for timekeeping.

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

































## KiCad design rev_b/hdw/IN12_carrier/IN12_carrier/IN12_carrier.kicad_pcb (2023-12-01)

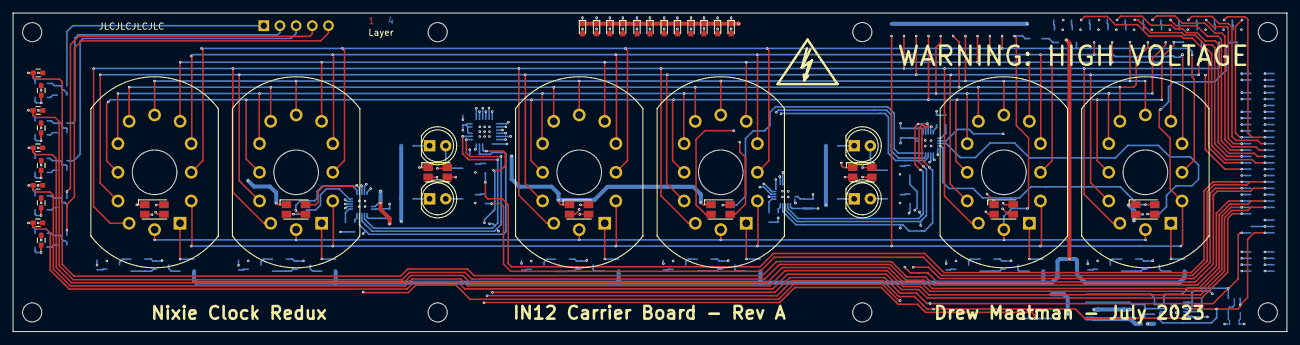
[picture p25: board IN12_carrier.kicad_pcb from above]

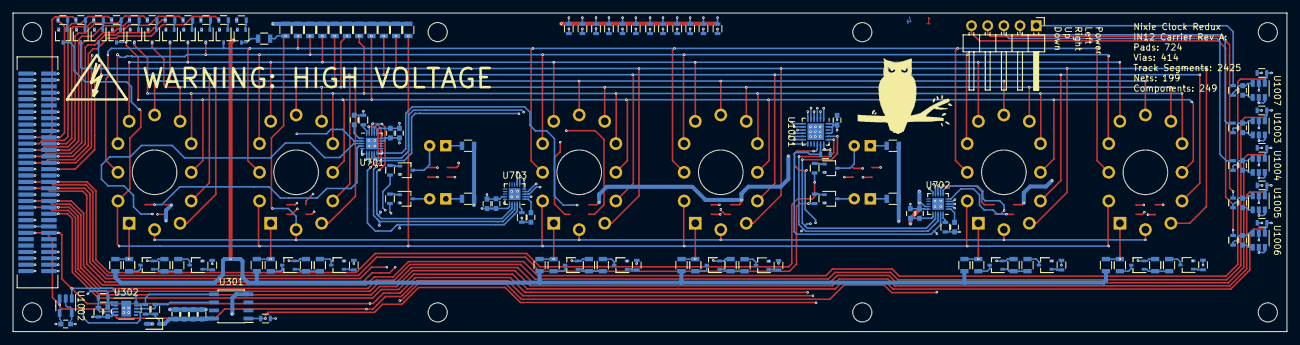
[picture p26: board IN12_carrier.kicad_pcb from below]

Board: 4 copper layers, 200.0 x 50.0 mm, 203 parts (155 on the bottom side), 172 nets.

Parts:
C301, C302, C303, C701, C702, C703, C704, C705, C706: 10uF; C_0603
C304, C305, C707, C708, C709, C1001, C1002, C1003, C1004, C1005, C1006, C1011, C1012, C1013, C1014, C1015, C1017: 0.1uF; C_0603
C1007, C1008, C1009, C1010, C1016: 10nF; C_0603
D301: BAT48JFILM; D_SOD-323
D701, D702, D703, D704, D705, D706, D707, D708: ASMB-MTB0-0A3A2; LED_Avago_PLCC4_3.2x2.8mm_CW
D901, D1001, D1002, D1003, D1004, D1005, D1006, D1007, D1008, D1009, D1010, D1011: Orange; LED_0603
H1201, H1202, H1203, H1204, H1205, H1206, H1207, H1208: MountingHole; MountingHole_3mm
J201: Conn_02x32_Top_Bottom; CONN_5120528-1_TYC
J1001: Cap SNS; PinHeader_1x05_P2.54mm_Horizontal
Q401, Q402, Q403, Q407, Q408, Q409, Q501, Q502, Q503, Q504, Q505, Q506, Q507, Q508, Q509, Q510, Q511, Q512, Q513, Q514, Q515: MMSTA42; SOT-323_SC-70
Q404, Q405, Q406, Q410, Q411, Q412: MMSTA92; SOT-323_SC-70
R301, R302, R305, R401, R402, R403, R413, R414, R415, R501, R502, R503, R504, R505, R506, R507, R508, R509, R510, R511, R512, R513, R515, R516, R701, R1012, R1013, R1014, R1015, R1020: 10k; R_0603
R303: 392k; R_0603
R304: 1M; R_0603
R404, R405, R406, R416, R417, R418, R801, R802, R803, R804, R805, R806, R807, R808, R809, R810, R811, R812, R813, R814, R815, R816, R817: 470k; R_0805
R407, R408, R409, R419, R420, R421: 100k; R_0805
R410, R411, R412, R422, R423, R424, R514: 18k; R_0805
R601, R602, R603, R604: 10k; R_0805
R704, R705, R706: 3.65k; R_0603
R901, R1001, R1002, R1003, R1004, R1005, R1006, R1007, R1008, R1009, R1010, R1011, R1016, R1017, R1018, R1019, R1021: 499; R_0603
U301: DS1683; SOIC-8_3.9x4.9mm_Pitch1.27mm
U302: LTC4316DD; DFN-10-1EP_3x3mm_Pitch0.5mm
U701, U702, U703: LP5009; UQFN-20-1EP_3x3mm_Pitch0.4mm
U1001: TCA9555RGER; QFN-24-1EP_4x4mm_P0.5mm_EP2.6x2.6mm
U1002: 24AA02-OT; SOT-23-5
U1003, U1004, U1005, U1006, U1007: AT42QT1010-TSHR; SOT-23-6
V601, V602, V603, V604, V605, V608: IN12B; IN-12B
V606, V607, V609, V610: IN3; LED_D5.0mm

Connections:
24HR_Mode_LED: R1010.1, U1001.11
+3.3V: C305.1, C704.1, C705.1, C706.1, C707.1, C708.1, C709.1, C1001.1, C1002.1, C1011.1, C1012.1, C1013.1, C1014.1, C1017.1, D301.2 (A), D701.1 (A), D702.1 (A), D703.1 (A), D704.1 (A), D705.1 (A), D706.1 (A), D707.1 (A), D708.1 (A), J201.61, J201.62, J201.63, J201.64, R304.1, U302.4 (VCC), U302.5 (Enable), U701.16 (VCC), U702.14 (ADDR0), U702.16 (VCC), U703.15 (ADDR1), U703.16 (VCC), U1001.18 (A0), U1001.21 (VCC), U1001.23 (A1), U1001.24 (A2), U1002.4 (V_{CC}), U1003.5 (VDD), U1003.6 (SYNC), U1004.5 (VDD), U1004.6 (SYNC), U1005.5 (VDD), U1005.6 (SYNC), U1006.5 (VDD), U1006.6 (SYNC), U1007.5 (VDD), U1007.6 (SYNC)
+90V: J201.33, J201.34, R801.2, R802.2, R803.2, R804.2, R805.2, R806.2, R807.2, R808.2, R809.2, R810.2, R811.2, R812.2, R813.2, R814.2, R815.2, R816.2, R817.2
+180V: J201.36, J201.37, Q404.2 (E), Q405.2 (E), Q406.2 (E), Q410.2 (E), Q411.2 (E), Q412.2 (E), R407.2, R408.2, R409.2, R419.2, R420.2, R421.2, R601.1, R602.1, R603.1, R604.1
Alarm_Enable_LED: R1009.1, U1001.10
Anode_0: R410.1, R801.1, V604.1 (Anode)
Anode_0_DSP: J201.39, R401.1
Anode_1: R422.1, R802.1, V602.1 (Anode)
Anode_1_DSP: J201.7, R413.1
Anode_2: R411.1, R803.1, V608.1 (Anode)
Anode_2_DSP: J201.40, R402.1
Anode_3: R423.1, R804.1, V605.1 (Anode)
Anode_3_DSP: J201.8, R414.1
Anode_4: R412.1, R805.1, V603.1 (Anode)
Anode_4_DSP: J201.41, R403.1
Anode_5: R424.1, R806.1, V601.1 (Anode)
Anode_5_DSP: J201.9, R415.1
COLON0_LED_B: D703.2 (BK), U703.4 (OUT2)
COLON0_LED_G: D703.3 (GK), U703.3 (OUT1)
COLON0_LED_R: D703.4 (RK), U703.2 (OUT0)
COLON1_LED_B: D706.2 (BK), U703.7 (OUT5)
COLON1_LED_G: D706.3 (GK), U703.6 (OUT4)
COLON1_LED_R: D706.4 (RK), U703.5 (OUT3)
Cathode_0: Q501.3 (C), R807.1, V601.2 (Digit0), V602.2 (Digit0), V603.2 (Digit0), V604.2 (Digit0), V605.2 (Digit0), V608.2 (Digit0)
Cathode_0_DSP: J201.43, R501.1
Cathode_1: Q506.3 (C), R808.1, V601.11 (Digit1), V602.11 (Digit1), V603.11 (Digit1), V604.11 (Digit1), V605.11 (Digit1), V608.11 (Digit1)
Cathode_1_DSP: J201.11, R506.1
Cathode_2: Q502.3 (C), R809.1, V601.10 (Digit2), V602.10 (Digit2), V603.10 (Digit2), V604.10 (Digit2), V605.10 (Digit2), V608.10 (Digit2)
Cathode_2_DSP: J201.44, R502.1
Cathode_3: Q507.3 (C), R810.1, V601.9 (Digit3), V602.9 (Digit3), V603.9 (Digit3), V604.9 (Digit3), V605.9 (Digit3), V608.9 (Digit3)
Cathode_3_DSP: J201.12, R507.1
Cathode_4: Q503.3 (C), R811.1, V601.8 (Digit4), V602.8 (Digit4), V603.8 (Digit4), V604.8 (Digit4), V605.8 (Digit4), V608.8 (Digit4)
Cathode_4_DSP: J201.45, R503.1
Cathode_5: Q508.3 (C), R812.1, V601.7 (Digit5), V602.7 (Digit5), V603.7 (Digit5), V604.7 (Digit5), V605.7 (Digit5), V608.7 (Digit5)
Cathode_5_DSP: J201.13, R508.1
Cathode_6: Q504.3 (C), R813.1, V601.6 (Digit6), V602.6 (Digit6), V603.6 (Digit6), V604.6 (Digit6), V605.6 (Digit6), V608.6 (Digit6)
Cathode_6_DSP: J201.46, R504.1
Cathode_7: Q509.3 (C), R814.1, V601.5 (Digit7), V602.5 (Digit7), V603.5 (Digit7), V604.5 (Digit7), V605.5 (Digit7), V608.5 (Digit7)
Cathode_7_DSP: J201.14, R509.1
Cathode_8: Q505.3 (C), R815.1, V601.4 (Digit8), V602.4 (Digit8), V603.4 (Digit8), V604.4 (Digit8), V605.4 (Digit8), V608.4 (Digit8)
Cathode_8_DSP: J201.47, R505.1
Cathode_9: Q510.3 (C), R816.1, V601.3 (Digit9), V602.3 (Digit9), V603.3 (Digit9), V604.3 (Digit9), V605.3 (Digit9), V608.3 (Digit9)
Cathode_9_DSP: J201.15, R510.1
Cathode_DP: R514.2, R817.1, V601.12 (DP), V602.12 (DP), V603.12 (DP), V604.12 (DP), V605.12 (DP), V608.12 (DP)
Cathode_DP_DSP: J201.48, R511.1
Colon_0_Cathode: Q513.3 (C), V606.2 (Kathode)
Colon_0_DSP: J201.50, R513.1
Colon_1_Cathode: Q512.3 (C), V607.2 (Kathode)
Colon_1_DSP: J201.18, R512.1
Colon_2_Cathode: Q515.3 (C), V609.2 (Kathode)
Colon_2_DSP: J201.51, R516.1
Colon_3_Cathode: Q514.3 (C), V610.2 (Kathode)
Colon_3_DSP: J201.19, R515.1
Display_Alarm_LED: R1007.1, U1001.7 (P06)
Display_Date_LED: R1003.1, U1001.3 (P02)
Display_Time_LED: R1001.1, U1001.1 (P00)
Display_Weekday_LED: R1005.1, U1001.5 (P04)
GND: C301.2, C302.2, C303.2, C304.2, C305.2, C701.2, C702.2, C703.2, C704.2, C705.2, C706.2, C707.2, C708.2, C709.2, C1001.2, C1002.2, C1003.2, C1004.2, C1005.2, C1006.2, C1011.2, C1012.2, C1013.2, C1014.2, C1015.2, C1017.2, D901.1 (K), D1001.1 (K), D1002.1 (K), D1003.1 (K), D1004.1 (K), D1005.1 (K), D1006.1 (K), D1007.1 (K), D1008.1 (K), D1009.1 (K), D1010.1 (K), D1011.1 (K), J201.1, J201.2, J201.3, J201.4, J201.5, J201.6, J201.10, J201.16, J201.17, J201.20, J201.24, J201.25, J201.29, J201.30, J201.31, J201.32, J201.42, J201.49, J201.52, J201.57, Q401.2 (E), Q402.2 (E), Q403.2 (E), Q407.2 (E), Q408.2 (E), Q409.2 (E), Q501.2 (E), Q502.2 (E), Q503.2 (E), Q504.2 (E), Q505.2 (E), Q506.2 (E), Q507.2 (E), Q508.2 (E), Q509.2 (E), Q510.2 (E), Q511.2 (E), Q512.2 (E), Q513.2 (E), Q514.2 (E), Q515.2 (E), R303.2, R305.2, R701.2, R704.2, R705.2, R706.2, R1012.2, R1013.2, R1014.2, R1015.2, R1020.2, U301.4 (GND), U302.1 (GND), U302.2 (XORH), U302.11 (GND), U701.14 (ADDR0), U701.15 (ADDR1), U701.21 (GND), U702.15 (ADDR1), U702.21 (GND), U703.14 (ADDR0), U703.21 (GND), U1001.9 (GND), U1001.25 (EPAD), U1002.2 (V_{SS}), U1002.5 (WP), U1003.2 (VSS), U1004.2 (VSS), U1005.2 (VSS), U1006.2 (VSS), U1007.2 (VSS)
I2C_DSP_SCL: J201.58, U302.10 (SCLIN), U701.18 (SCL), U702.18 (SCL), U703.18 (SCL), U1001.19 (SCL), U1002.1 (SCL)
I2C_DSP_SDA: J201.26, U302.7 (SDAIN), U701.17 (SDA), U702.17 (SDA), U703.17 (SDA), U1001.20 (SDA), U1002.3 (SDA)
unnamed: C301.1, C302.1, C303.1, C304.1, D301.1 (K), R301.1, R302.1, U301.8 (VCC)
unnamed: D901.2 (A), R901.2
unnamed: D1001.2 (A), R1001.2
unnamed: D1002.2 (A), R1002.2
unnamed: D1003.2 (A), R1003.2
unnamed: D1004.2 (A), R1004.2
unnamed: D1005.2 (A), R1005.2
unnamed: D1006.2 (A), R1006.2
unnamed: D1007.2 (A), R1007.2
unnamed: D1008.2 (A), R1008.2
unnamed: D1009.2 (A), R1009.2
unnamed: D1010.2 (A), R1010.2
unnamed: D1011.2 (A), R1011.2
unnamed: Q401.1 (B), R401.2
unnamed: Q401.3 (C), R404.1
unnamed: Q402.1 (B), R402.2
unnamed: Q402.3 (C), R405.1
unnamed: Q403.1 (B), R403.2
unnamed: Q403.3 (C), R406.1
unnamed: Q404.1 (B), R404.2, R407.1
unnamed: Q404.3 (C), R410.2
unnamed: Q405.1 (B), R405.2, R408.1
unnamed: Q405.3 (C), R411.2
unnamed: Q406.1 (B), R406.2, R409.1
unnamed: Q406.3 (C), R412.2
unnamed: Q407.1 (B), R413.2
unnamed: Q407.3 (C), R416.1
unnamed: Q408.1 (B), R414.2
unnamed: Q408.3 (C), R417.1
unnamed: Q409.1 (B), R415.2
unnamed: Q409.3 (C), R418.1
unnamed: Q410.1 (B), R416.2, R419.1
unnamed: Q410.3 (C), R422.2
unnamed: Q411.1 (B), R417.2, R420.1
unnamed: Q411.3 (C), R423.2
unnamed: Q412.1 (B), R418.2, R421.1
unnamed: Q412.3 (C), R424.2
unnamed: Q501.1 (B), R501.2
unnamed: Q502.1 (B), R502.2
unnamed: Q503.1 (B), R503.2
unnamed: Q504.1 (B), R504.2
unnamed: Q505.1 (B), R505.2
unnamed: Q506.1 (B), R506.2
unnamed: Q507.1 (B), R507.2
unnamed: Q508.1 (B), R508.2
unnamed: Q509.1 (B), R509.2
unnamed: Q510.1 (B), R510.2
unnamed: Q511.1 (B), R511.2
unnamed: Q511.3 (C), R514.1
unnamed: Q512.1 (B), R512.2
unnamed: Q513.1 (B), R513.2
unnamed: Q514.1 (B), R515.2
unnamed: Q515.1 (B), R516.2
unnamed: R301.2, U301.5 (SCL), U302.9 (SCLOUT)
unnamed: R302.2, U301.6 (SDA), U302.8 (SDAOUT)
unnamed: R303.1, R304.2, U302.3 (XORL)
unnamed: R704.1, U701.20 (IREF)
unnamed: C701.1, U701.1 (VCAP)
unnamed: R705.1, U702.20 (IREF)
unnamed: C702.1, U702.1 (VCAP)
unnamed: R706.1, U703.20 (IREF)
unnamed: C703.1, U703.1 (VCAP)
unnamed: C1007.1, U1003.4 (SNS)
unnamed: C1007.2, R1016.2, U1003.3 (SNSK)
unnamed: C1008.1, U1004.4 (SNS)
unnamed: C1008.2, R1017.2, U1004.3 (SNSK)
unnamed: C1009.1, U1005.4 (SNS)
unnamed: C1009.2, R1018.2, U1005.3 (SNSK)
unnamed: C1010.1, U1006.4 (SNS)
unnamed: C1010.2, R1019.2, U1006.3 (SNSK)
unnamed: C1016.1, U1007.4 (SNS)
unnamed: C1016.2, R1021.2, U1007.3 (SNSK)
unnamed: R601.2, V606.1 (Anode)
unnamed: R602.2, V607.1 (Anode)
unnamed: R603.2, V609.1 (Anode)
unnamed: R604.2, V610.1 (Anode)
Pushbutton_Down: C1005.1, J201.55, R1014.1, U1006.1 (OUT)
Pushbutton_Down_SNS: J1001.5, R1019.1
Pushbutton_Left: C1015.1, J201.21, R1020.1, U1003.1 (OUT)
Pushbutton_Left_SNS: J1001.2, R1016.1
Pushbutton_Power: C1006.1, J201.53, R1015.1, U1007.1 (OUT)
Pushbutton_Power_SNS: J1001.1, R1021.1
Pushbutton_Right: C1003.1, J201.54, R1012.1, U1004.1 (OUT)
Pushbutton_Right_SNS: J1001.3, R1017.1
Pushbutton_Up: C1004.1, J201.22, R1013.1, U1005.1 (OUT)
Pushbutton_Up_SNS: J1001.4, R1018.1
Set_Alarm_LED: R1008.1, U1001.8 (P07)
Set_Brightness_LED: R1011.1, U1001.12
Set_Color_LED: R901.1, U1001.13
Set_Date_LED: R1004.1, U1001.4 (P03)
Set_Time_LED: R1002.1, U1001.2 (P01)
Set_Weekday_LED: R1006.1, U1001.6 (P05)
TUBE0_LED_B: D701.2 (BK), U701.4 (OUT2)
TUBE0_LED_G: D701.3 (GK), U701.3 (OUT1)
TUBE0_LED_R: D701.4 (RK), U701.2 (OUT0)
TUBE1_LED_B: D704.2 (BK), U701.7 (OUT5)
TUBE1_LED_G: D704.3 (GK), U701.6 (OUT4)
TUBE1_LED_R: D704.4 (RK), U701.5 (OUT3)
TUBE2_LED_B: D707.2 (BK), U701.10 (OUT8)
TUBE2_LED_G: D707.3 (GK), U701.9 (OUT7)
TUBE2_LED_R: D707.4 (RK), U701.8 (OUT6)
TUBE3_LED_B: D702.2 (BK), U702.4 (OUT2)
TUBE3_LED_G: D702.3 (GK), U702.3 (OUT1)
TUBE3_LED_R: D702.4 (RK), U702.2 (OUT0)
TUBE4_LED_B: D705.2 (BK), U702.7 (OUT5)
TUBE4_LED_G: D705.3 (GK), U702.6 (OUT4)
TUBE4_LED_R: D705.4 (RK), U702.5 (OUT3)
TUBE5_LED_B: D708.2 (BK), U702.10 (OUT8)
TUBE5_LED_G: D708.3 (GK), U702.9 (OUT7)
TUBE5_LED_R: D708.4 (RK), U702.8 (OUT6)
Tube_ETC_Enable: R305.1, U301.1 (EVENT), U1001.16
Tube_LED_Enable: R701.1, U701.19 (EN), U702.19 (EN), U703.19 (EN), U1001.17

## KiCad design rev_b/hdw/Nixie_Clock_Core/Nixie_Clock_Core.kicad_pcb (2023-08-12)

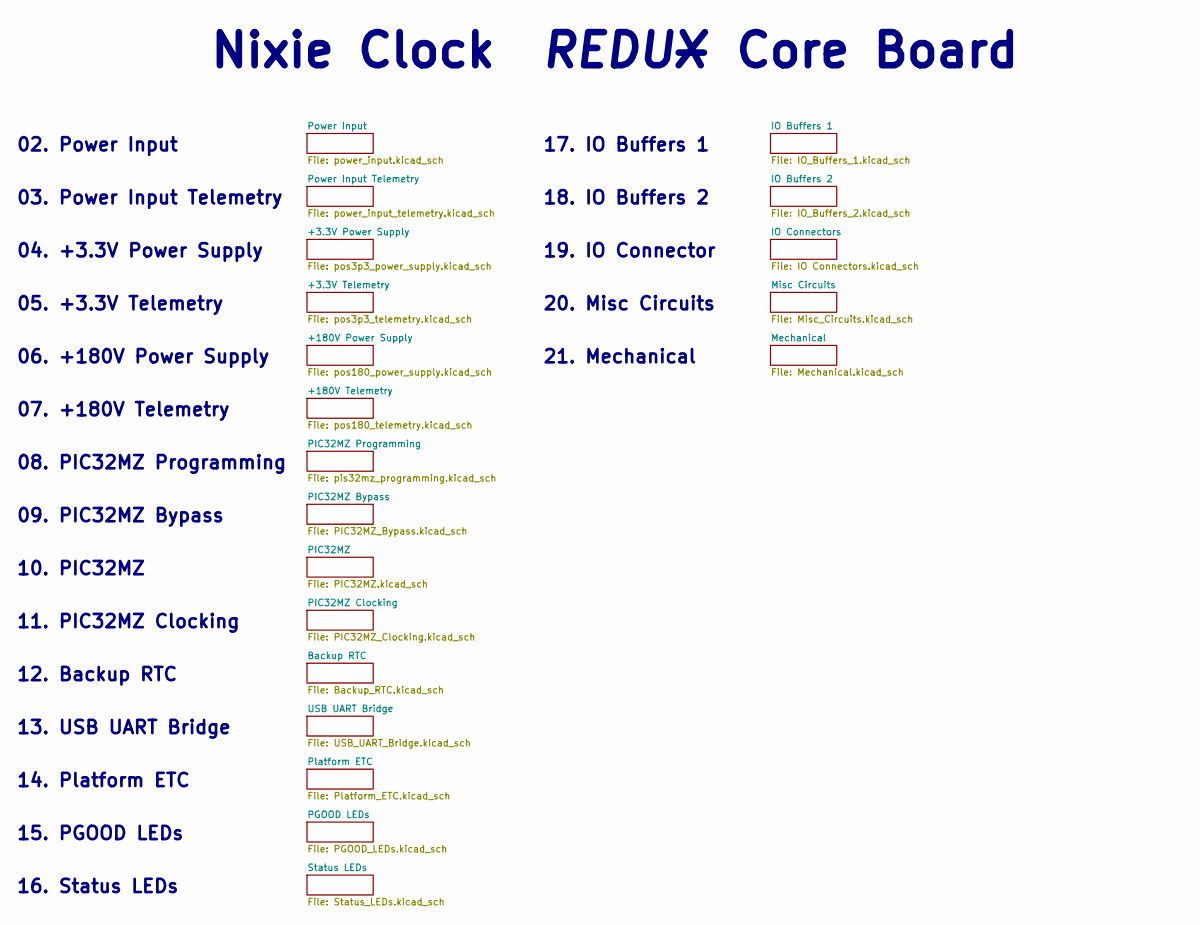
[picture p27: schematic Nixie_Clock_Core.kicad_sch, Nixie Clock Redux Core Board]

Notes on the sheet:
04. +3.3V Power Supply
Nixie Clock - Core Board
12. Backup RTC
20. Misc Circuits
02. Power Input
11. PIC32MZ Clocking
09. PIC32MZ Bypass
06. +180V Power Supply
17. IO Buffers 1
08. PIC32MZ Programming
07. +180V Telemetry
13. USB UART Bridge
16. Status LEDs
15. PGOOD LEDs
REDUX
21. Mechanical
18. IO Buffers 2
05. +3.3V Telemetry
14. Platform ETC
03. Power Input Telemetry
19. IO Connector
10. PIC32MZ

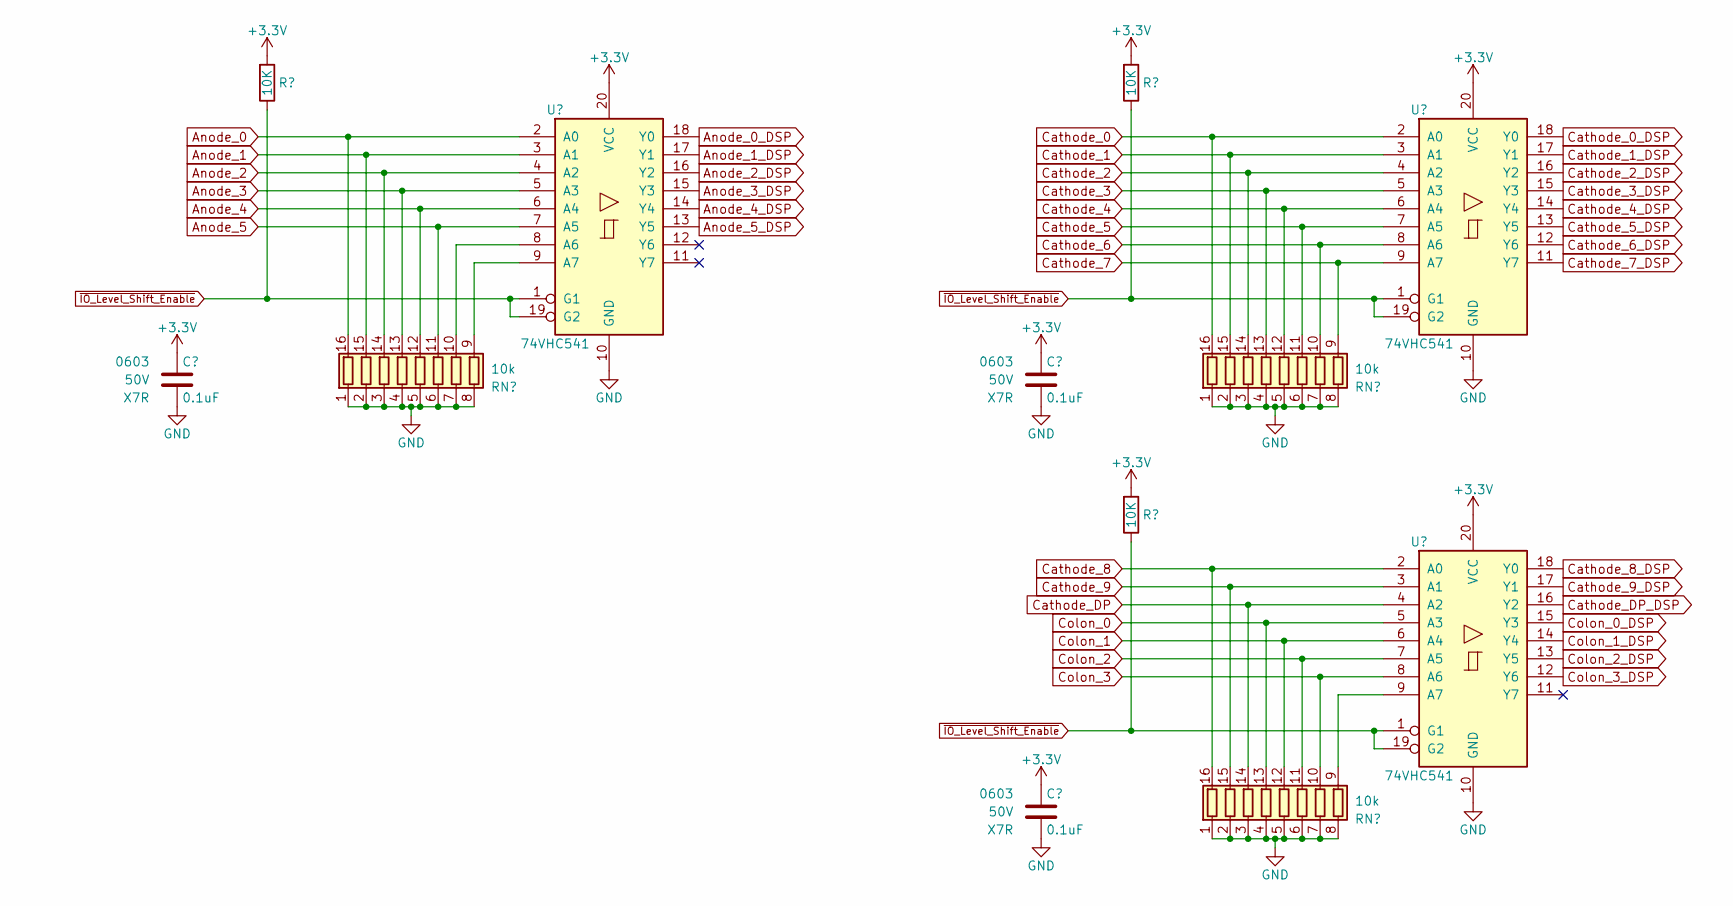
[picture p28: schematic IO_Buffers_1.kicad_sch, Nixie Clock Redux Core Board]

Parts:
C1701, C1702, C1703: 0.1uF; C_0603; Voltage 50V; Digi-Key PN 1276-1935-1-ND
R1701, R1702, R1703: 10K; R_0603; Tolerance 1%; Digi-Key PN 541-10.0KHCT-ND
RN1701, RN1702, RN1703: 10k; R_Array_Convex_8x0602; Tolerance 1%; Digi-Key PN Y1103CT-ND
U1701, U1702, U1703: 74VHC541; WQFN-20-1EP_2.5x4.5mm_P0.5mm_EP1x2.9mm; Digi-Key PN 1727-7068-1-ND

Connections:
Anode_0: RN1701.16 (R1.2), U1701.2 (A0); also elsewhere on the board
Anode_0_DSP: U1701.18 (Y0); also elsewhere on the board
Anode_1: RN1701.15 (R2.2), U1701.3 (A1); also elsewhere on the board
Anode_1_DSP: U1701.17 (Y1); also elsewhere on the board
Anode_2: RN1701.14 (R3.2), U1701.4 (A2); also elsewhere on the board
Anode_2_DSP: U1701.16 (Y2); also elsewhere on the board
Anode_3: RN1701.13 (R4.2), U1701.5 (A3); also elsewhere on the board
Anode_3_DSP: U1701.15 (Y3); also elsewhere on the board
Anode_4: RN1701.12 (R5.2), U1701.6 (A4); also elsewhere on the board
Anode_4_DSP: U1701.14 (Y4); also elsewhere on the board
Anode_5: RN1701.11 (R6.2), U1701.7 (A5); also elsewhere on the board
Anode_5_DSP: U1701.13 (Y5); also elsewhere on the board
Cathode_0: RN1702.16 (R1.2), U1702.2 (A0); also elsewhere on the board
Cathode_0_DSP: U1702.18 (Y0); also elsewhere on the board
Cathode_1: RN1702.15 (R2.2), U1702.3 (A1); also elsewhere on the board
Cathode_1_DSP: U1702.17 (Y1); also elsewhere on the board
Cathode_2: RN1702.14 (R3.2), U1702.4 (A2); also elsewhere on the board
Cathode_2_DSP: U1702.16 (Y2); also elsewhere on the board
Cathode_3: RN1702.13 (R4.2), U1702.5 (A3); also elsewhere on the board
Cathode_3_DSP: U1702.15 (Y3); also elsewhere on the board
Cathode_4: RN1702.12 (R5.2), U1702.6 (A4); also elsewhere on the board
Cathode_4_DSP: U1702.14 (Y4); also elsewhere on the board
Cathode_5: RN1702.11 (R6.2), U1702.7 (A5); also elsewhere on the board
Cathode_5_DSP: U1702.13 (Y5); also elsewhere on the board
Cathode_6: RN1702.10 (R7.2), U1702.8 (A6); also elsewhere on the board
Cathode_6_DSP: U1702.12 (Y6); also elsewhere on the board
Cathode_7: RN1702.9 (R8.2), U1702.9 (A7); also elsewhere on the board
Cathode_7_DSP: U1702.11 (Y7); also elsewhere on the board
Cathode_8: RN1703.16 (R1.2), U1703.2 (A0); also elsewhere on the board
Cathode_8_DSP: U1703.18 (Y0); also elsewhere on the board
Cathode_9: RN1703.15 (R2.2), U1703.3 (A1); also elsewhere on the board
Cathode_9_DSP: U1703.17 (Y1); also elsewhere on the board
Cathode_DP: RN1703.14 (R3.2), U1703.4 (A2); also elsewhere on the board
Cathode_DP_DSP: U1703.16 (Y2); also elsewhere on the board
Colon_0: RN1703.13 (R4.2), U1703.5 (A3); also elsewhere on the board
Colon_0_DSP: U1703.15 (Y3); also elsewhere on the board
Colon_1: RN1703.12 (R5.2), U1703.6 (A4); also elsewhere on the board
Colon_1_DSP: U1703.14 (Y4); also elsewhere on the board
Colon_2: RN1703.11 (R6.2), U1703.7 (A5); also elsewhere on the board
Colon_2_DSP: U1703.13 (Y5); also elsewhere on the board
Colon_3: RN1703.10 (R7.2), U1703.8 (A6); also elsewhere on the board
Colon_3_DSP: U1703.12 (Y6); also elsewhere on the board
GND: C1701.2, C1702.2, C1703.2, RN1701.1 (R1.1), RN1701.2 (R2.1), RN1701.3 (R3.1), RN1701.4 (R4.1), RN1701.5 (R5.1), RN1701.6 (R6.1), RN1701.7 (R7.1), RN1701.8 (R8.1), RN1702.1 (R1.1), RN1702.2 (R2.1), RN1702.3 (R3.1), RN1702.4 (R4.1), RN1702.5 (R5.1), RN1702.6 (R6.1), RN1702.7 (R7.1), RN1702.8 (R8.1), RN1703.1 (R1.1), RN1703.2 (R2.1), RN1703.3 (R3.1), RN1703.4 (R4.1), RN1703.5 (R5.1), RN1703.6 (R6.1), RN1703.7 (R7.1), RN1703.8 (R8.1), U1701.10 (GND), U1701.21 (GND), U1702.10 (GND), U1702.21 (GND), U1703.10 (GND), U1703.21 (GND); also elsewhere on the board
unnamed: RN1701.10 (R7.2), U1701.8 (A6)
unnamed: RN1701.9 (R8.2), U1701.9 (A7)
unnamed: RN1703.9 (R8.2), U1703.9 (A7)
~IO_Level_Shift_Enable: R1701.2, R1702.2, R1703.2, U1701.1 (G1), U1701.19 (G2), U1702.1 (G1), U1702.19 (G2), U1703.1 (G1), U1703.19 (G2); also elsewhere on the board

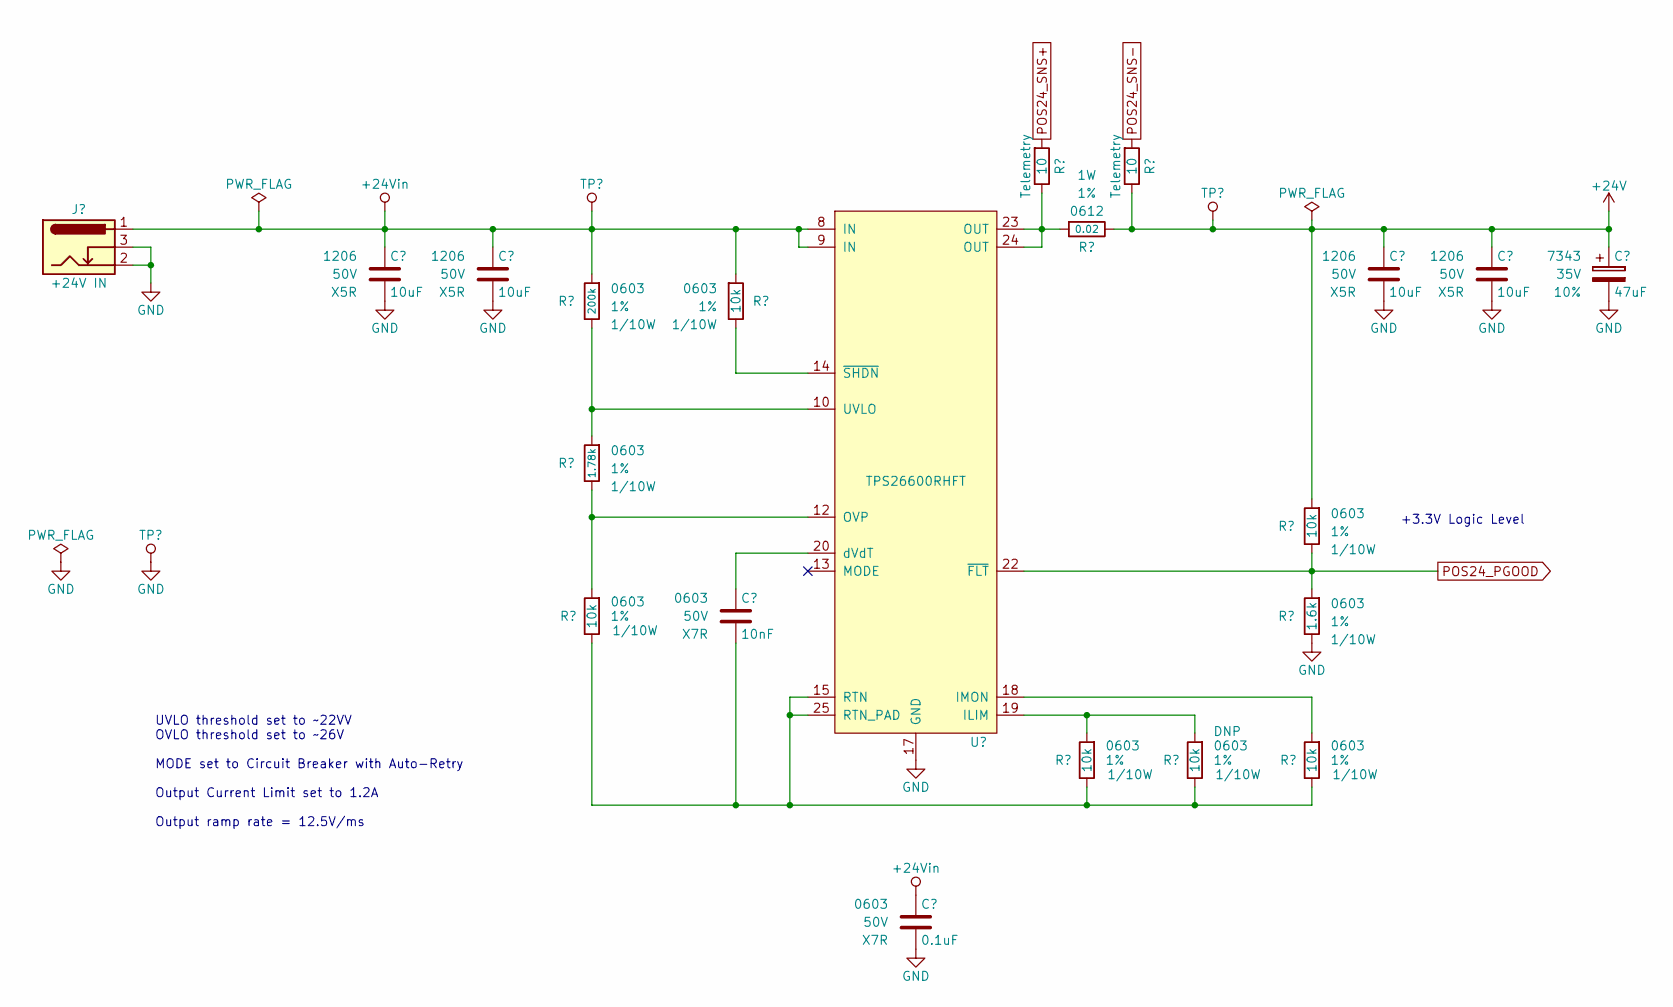
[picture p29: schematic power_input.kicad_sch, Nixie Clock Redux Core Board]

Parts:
C201, C202, C205, C206: 10uF; C_1206; Voltage 50V; Digi-Key PN 1276-6767-1-ND
C203: 10nF; C_0603; Voltage 50V; Digi-Key PN 1276-1009-1-ND
C204: 0.1uF; C_0603; Voltage 50V; Digi-Key PN 1276-1935-1-ND
C207: 47uF; CP_EIA-7343-43_Kemet-X; Voltage 35V; Tolerance 10%; Digi-Key PN 399-16639-1-ND
J201: +24V IN; BARREL_JACK
R201: 1.78k; R_0603; Tolerance 1%; Digi-Key PN 541-1.78KHCT-ND
R202: 200k; R_0603; Tolerance 1%; Digi-Key PN 541-4027-1-ND
R203, R204, R207, R209, R210, R212: 10k; R_0603; Tolerance 1%; Digi-Key PN 541-10.0KHCT-ND
R205, R208: 10; R_0603; Tolerance 1%; Digi-Key PN 541-10.0HCT-ND
R206: 0.02; R_0612; Tolerance 1%; Digi-Key PN P16010CT-ND
R211: 1.6k; R_0603; Tolerance 1%; Digi-Key PN 541-5237-1-ND
TP201: TP; PinHeader_1x01_P2.54mm_Horizontal
TP202, TP203: TP; Test_Point
U201: TPS26600RHFT; QFN-24-1EP_4x5mm_Pitch0.5mm; Digi-Key PN 296-45478-1-ND

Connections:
+24V: C205.1, C206.1, C207.1, R206.2, R208.2, R210.1, TP203.1 (TP); also elsewhere on the board
+24Vin: C201.1, C202.1, C204.1, J201.1, R202.1, R204.1, TP202.1 (TP), U201.8 (IN), U201.9 (IN)
GND: C201.2, C202.2, C204.2, C205.2, C206.2, C207.2, J201.2, J201.3, R211.2, TP201.1 (TP), U201.17 (GND); also elsewhere on the board
unnamed: R205.2, R206.1, U201.23 (OUT), U201.24 (OUT)
unnamed: R207.1, R209.1, U201.19 (ILIM)
unnamed: R212.1, U201.18 (IMON)
unnamed: R201.2, R203.1, U201.12 (OVP)
unnamed: C203.2, R203.2, R207.2, R209.2, R212.2, U201.15 (RTN), U201.25 (RTN_PAD)
unnamed: R201.1, R202.2, U201.10 (UVLO)
unnamed: C203.1, U201.20 (dVdT)
unnamed: R204.2, U201.14 (~SHDN)
POS24_PGOOD: R210.2, R211.1, U201.22 (~FLT); also elsewhere on the board
POS24_SNS+: R205.1; also elsewhere on the board
POS24_SNS-: R208.1; also elsewhere on the board

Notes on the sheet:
+3.3V Logic Level
UVLO threshold set to ~22VV OVLO threshold set to ~26V MODE set to Circuit Breaker with Auto-Retry Output Current Limit set to 1.2A Output ramp rate = 12.5V/ms

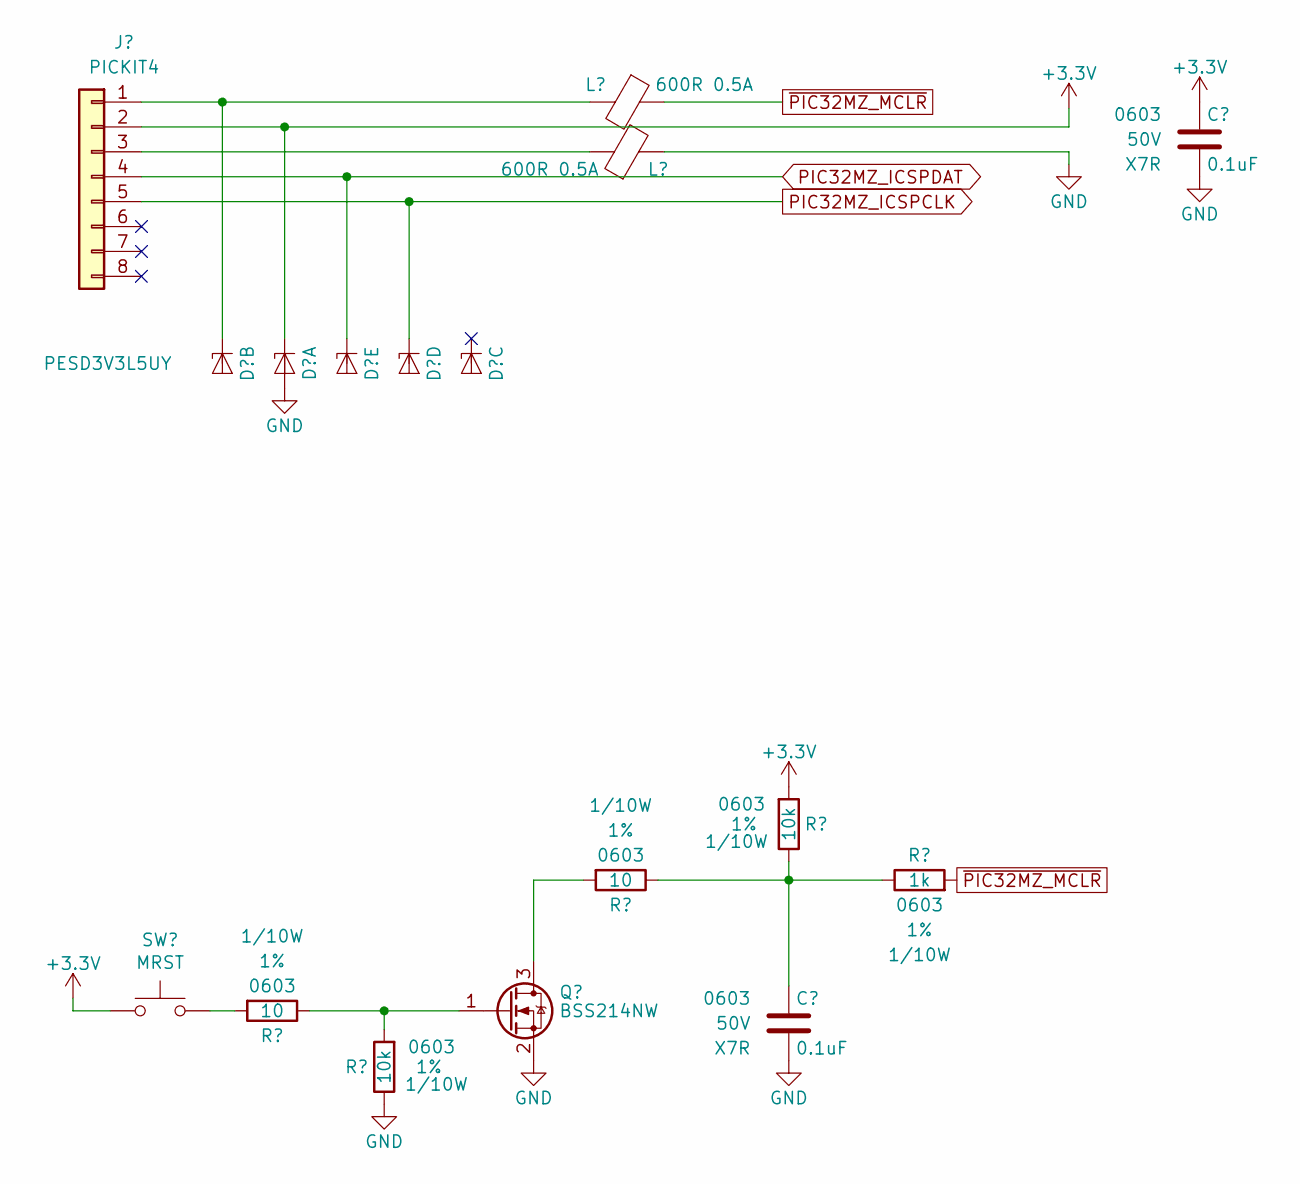
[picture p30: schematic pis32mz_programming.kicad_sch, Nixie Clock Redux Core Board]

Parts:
C801, C802: 0.1uF; C_0603; Voltage 50V; Digi-Key PN 1276-1935-1-ND
D801: PESD3V3L5UY; SOT-363_SC-70-6; Digi-Key PN 1727-3828-1-ND
J801: PICKIT4; PICKIT4_Header
L801, L802: 600R 0.5A; L_0603; Digi-Key PN 490-1014-1-ND
Q801: BSS214NW; SOT-323_SC-70; Digi-Key PN BSS214NWH6327XTSA1CT-ND
R801, R803: 10; R_0603; Tolerance 1%; Digi-Key PN 541-10.0HCT-ND
R802, R804: 10k; R_0603; Tolerance 1%; Digi-Key PN 541-10.0KHCT-ND
R805: 1k; R_0603; Tolerance 1%; Digi-Key PN 541-1.00KHCT-ND
SW801: MRST; SW_PUSH_6mm

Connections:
GND: C801.2, C802.2, D801.2 (A), L802.2, Q801.2 (S), R802.2; also elsewhere on the board
unnamed: C801.1, R803.2, R804.2, R805.2
unnamed: D801.3 (K2), J801.1, L801.2
unnamed: J801.3, L802.1
unnamed: Q801.3 (D), R803.1
unnamed: Q801.1 (G), R801.2, R802.1
unnamed: R801.1, SW801.2
PIC32MZ_ICSPCLK: D801.5 (K4), J801.5; also elsewhere on the board
PIC32MZ_ICSPDAT: D801.6 (K5), J801.4; also elsewhere on the board
~PIC32MZ_MCLR: L801.1, R805.1; also elsewhere on the board

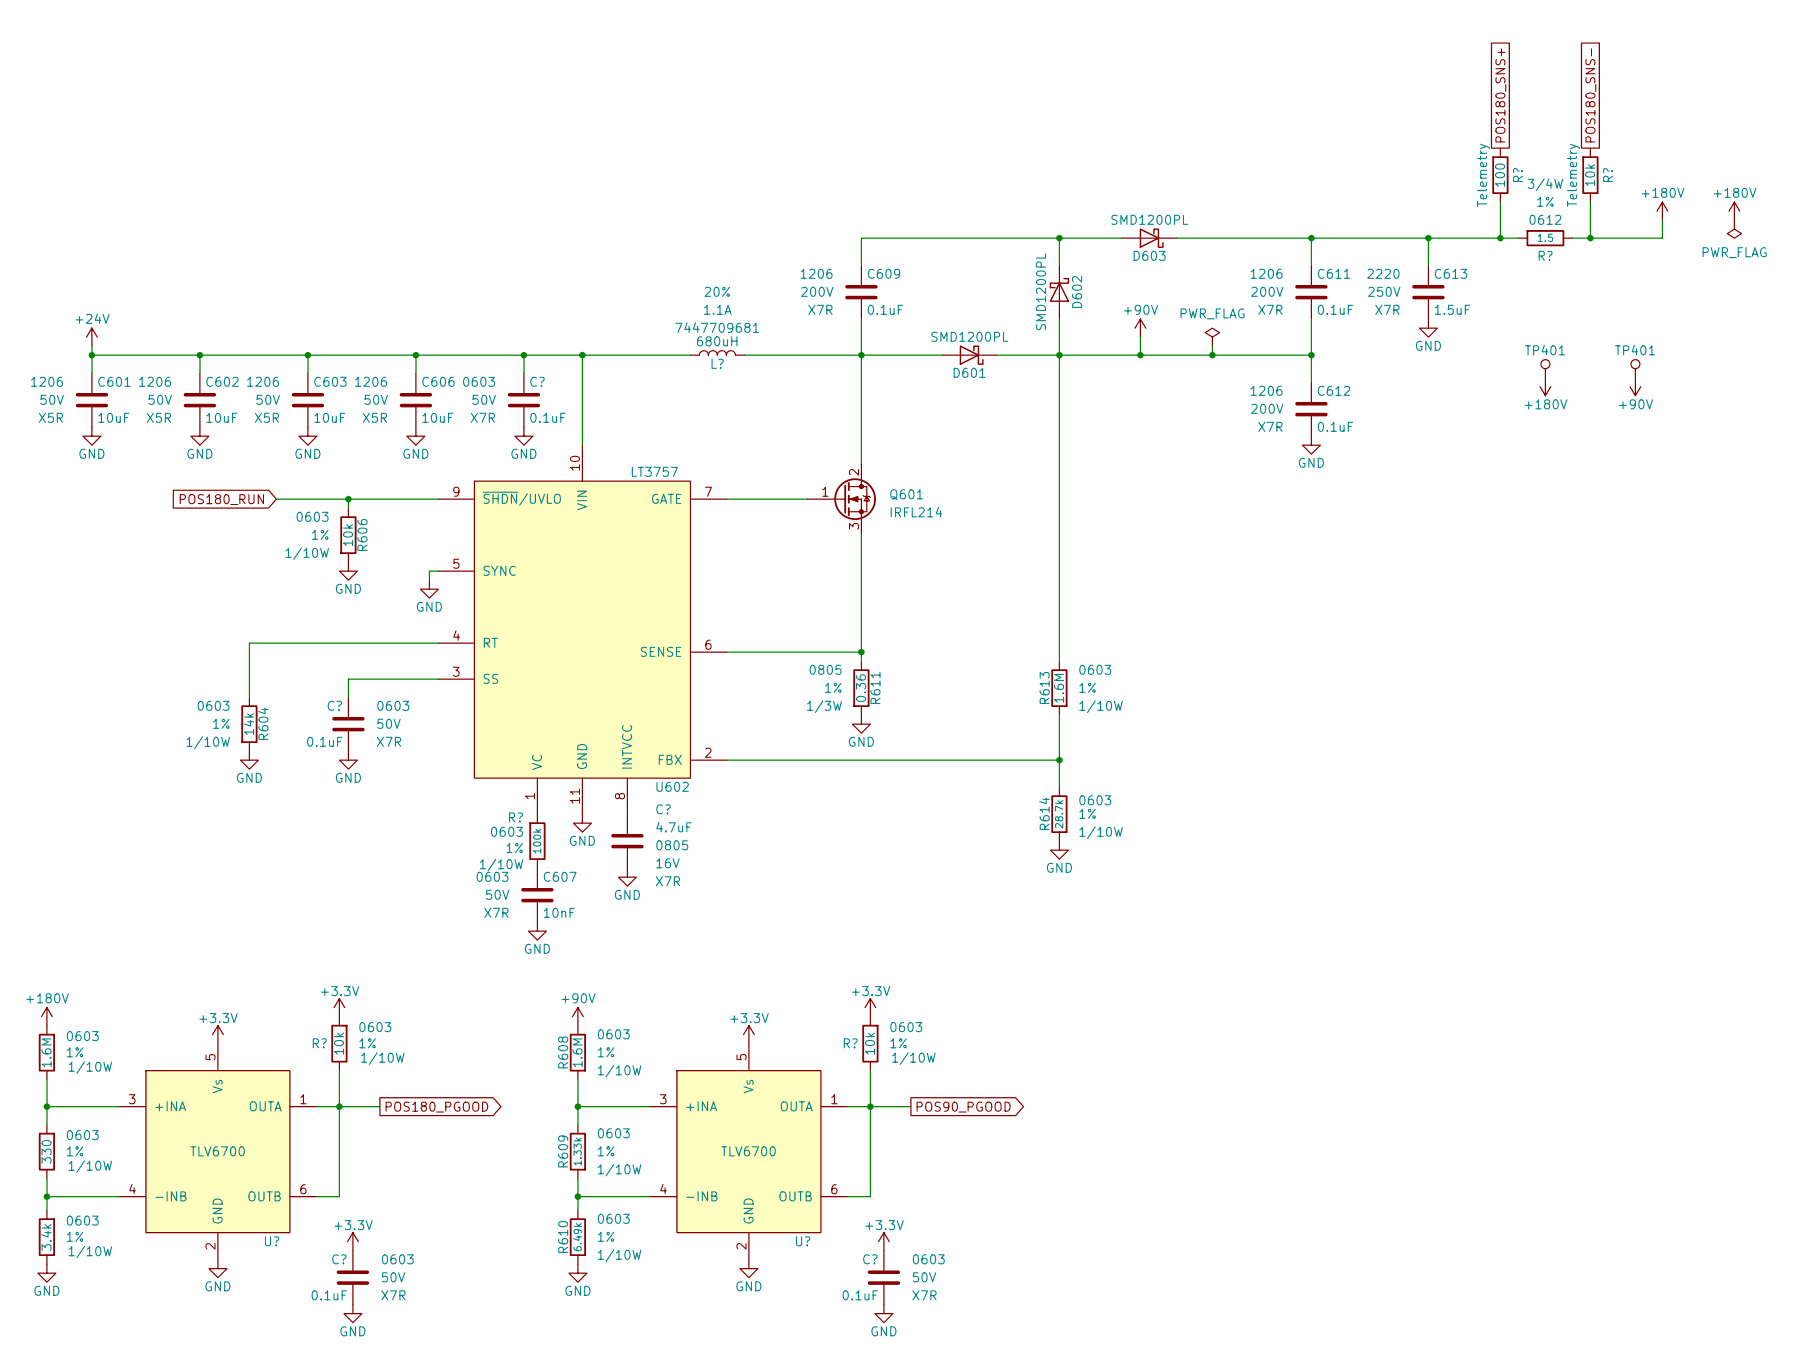
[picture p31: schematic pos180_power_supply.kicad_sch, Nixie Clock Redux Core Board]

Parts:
C601, C602, C603, C606: 10uF; C_1206; Voltage 50V; Digi-Key PN 1276-6767-1-ND
C604, C605, C610, C614: 0.1uF; C_0603; Voltage 50V; Digi-Key PN 1276-1935-1-ND
C607: 10nF; C_0603; Voltage 50V; Digi-Key PN 1276-1009-1-ND
C608: 4.7uF; C_0805; Voltage 16V; Digi-Key PN 1276-2970-1-ND
C609, C611, C612: 0.1uF; C_1206; Voltage 200V; Digi-Key PN 399-C1206C104K2RECAUTOCT-ND
C613: 1.5uF; C_2220; Voltage 250V; Digi-Key PN 565-4697-1-ND
D601, D602, D603: SMD1200PL; D_SOD-123F; Digi-Key PN SMD1200PL-TPMSCT-ND
L601: 680uH; Wurth_7447709681; Tolerance 20%; Digi-Key PN 732-1700-1-ND
Q601: IRFL214; SOT-223-3_TabPin2; Digi-Key PN IRFL214PBFCT-ND
R601, R608, R613: 1.6M; R_0603; Tolerance 1%; Digi-Key PN 541-1.60MHCT-ND
R602: 330; R_0603; Tolerance 1%; Digi-Key PN 541-330HCT-ND
R603: 3.4k; R_0603; Tolerance 1%; Digi-Key PN 541-3.40KHCT-ND
R604: 14k; R_0603; Tolerance 1%; Digi-Key PN 541-CRCW060314K0FKTACT-ND
R605, R606, R612, R617: 10k; R_0603; Tolerance 1%; Digi-Key PN 541-10.0KHCT-ND
R607: 100k; R_0603; Tolerance 1%; Digi-Key PN 541-100KHCT-ND
R609: 1.33k; R_0603; Tolerance 1%; Digi-Key PN 541-1.33KHCT-ND
R610: 6.49k; R_0603; Tolerance 1%; Digi-Key PN 541-5537-1-ND
R611: 0.36; R_0805; Tolerance 1%; Digi-Key PN RL12S.36FCT-ND
R614: 28.7k; R_0603; Tolerance 1%; Digi-Key PN 541-28.7KHCT-ND
R615: 100; R_0603; Tolerance 1%; Digi-Key PN 541-3951-1-ND
R616: 1.5; R_0612; Tolerance 1%; Digi-Key PN RCL06121R20FKEA
TP401: TP; Test_Point
U601, U603: TLV6700; SOT-23-6; Digi-Key PN 296-51696-1-ND
U602: LT3757; DFN-10-1EP_3x3mm_Pitch0.5mm; Digi-Key PN LT3757IDD#PBF

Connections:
+24V: C601.1, C602.1, C603.1, C606.1, C614.1, L601.1, U602.10 (VIN); also elsewhere on the board
GND: C601.2, C602.2, C603.2, C604.2, C605.2, C606.2, C607.2, C608.2, C610.2, C612.2, C613.2, C614.2, R603.2, R604.2, R606.2, R610.2, R611.2, R614.2, U601.2 (GND), U602.5 (SYNC), U602.11 (GND), U603.2 (GND); also elsewhere on the board
unnamed: C607.1, R607.2
unnamed: C609.2, D601.2 (A), L601.2, Q601.2 (D)
unnamed: C609.1, D602.1 (K), D603.2 (A)
unnamed: C611.1, C613.1, D603.1 (K), R615.2, R616.1
unnamed: Q601.1 (G), U602.7 (GATE)
unnamed: Q601.3 (S), R611.1, U602.6 (SENSE)
unnamed: R601.2, R602.1, U601.3 (+INA)
unnamed: R602.2, R603.1, U601.4 (-INB)
unnamed: R613.2, R614.1, U602.2 (FBX)
unnamed: C608.1, U602.8 (INTVCC)
unnamed: R604.1, U602.4 (RT)
unnamed: C604.1, U602.3 (SS)
unnamed: R607.1, U602.1 (VC)
unnamed: R608.2, R609.1, U603.3 (+INA)
unnamed: R609.2, R610.1, U603.4 (-INB)
POS90_PGOOD: R612.2, U603.1 (OUTA), U603.6 (OUTB); also elsewhere on the board
POS180_PGOOD: R605.2, U601.1 (OUTA), U601.6 (OUTB); also elsewhere on the board
POS180_RUN: R606.1, U602.9 (~SHDN/UVLO); also elsewhere on the board
POS180_SNS+: R615.1; also elsewhere on the board
POS180_SNS-: R617.1; also elsewhere on the board

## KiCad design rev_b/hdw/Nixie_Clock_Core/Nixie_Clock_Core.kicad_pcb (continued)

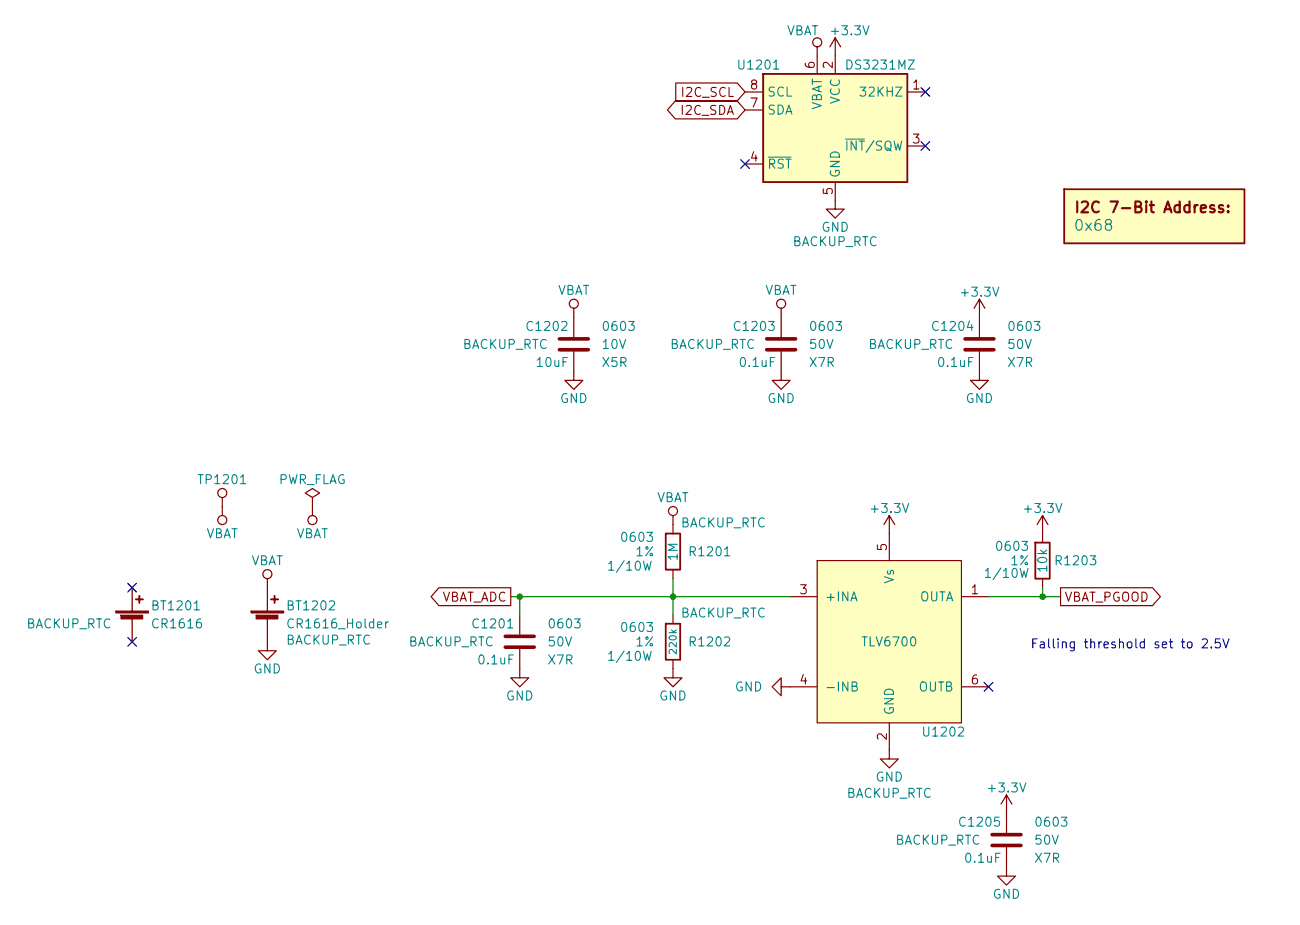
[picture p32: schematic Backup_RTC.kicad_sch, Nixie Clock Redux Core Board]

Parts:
BT1201: CR1616; Digi-Key PN P034-ND
BT1202: CR1616_Holder; BAT_BU1632SM-JJ-GTR; Digi-Key PN BU1632SM-JJ-GCT-ND
C1201, C1203, C1204, C1205: 0.1uF; C_0603; Voltage 50V; Digi-Key PN 1276-1935-1-ND
C1202: 10uF; C_0603; Voltage 10V; Digi-Key PN 1276-1871-1-ND
DOC1201: 0x68
R1201: 1M; R_0603; Tolerance 1%; Digi-Key PN 541-1.00MHCT-ND
R1202: 220k; R_0603; Tolerance 1%; Digi-Key PN 541-4039-1-ND
R1203: 10k; R_0603; Tolerance 1%; Digi-Key PN 541-10.0KHCT-ND
TP1201: TP; Test_Point
U1201: DS3231MZ; SOIC-8_3.9x4.9mm_P1.27mm; Digi-Key PN DS3231MZ+-ND
U1202: TLV6700; SOT-23-6; Digi-Key PN 296-51696-1-ND

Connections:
GND: BT1202.2 (-), C1201.2, C1202.2, C1203.2, C1204.2, C1205.2, R1202.2, U1201.5 (GND), U1202.2 (GND), U1202.4 (-INB); also elsewhere on the board
I2C_SCL: U1201.8 (SCL); also elsewhere on the board
I2C_SDA: U1201.7 (SDA); also elsewhere on the board
VBAT: BT1202.1 (+), C1202.1, C1203.1, R1201.1, TP1201.1 (TP), U1201.6 (VBAT)
VBAT_ADC: C1201.1, R1201.2, R1202.1, U1202.3 (+INA); also elsewhere on the board
VBAT_PGOOD: R1203.2, U1202.1 (OUTA); also elsewhere on the board

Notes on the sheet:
Falling threshold set to 2.5V

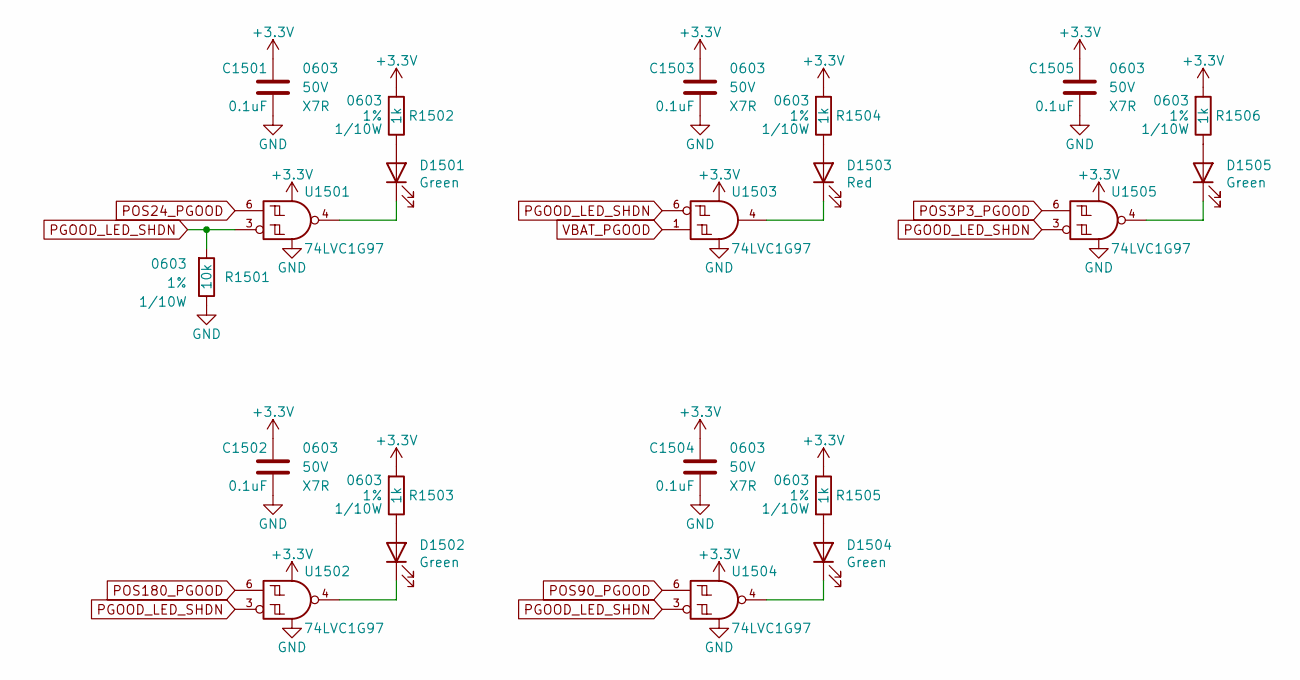
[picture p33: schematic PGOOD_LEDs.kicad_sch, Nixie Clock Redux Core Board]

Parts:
C1501, C1502, C1503, C1504, C1505: 0.1uF; C_0603; Voltage 50V; Digi-Key PN 1276-1935-1-ND
D1501, D1502, D1504, D1505: Green; LED_0603; Digi-Key PN 754-1121-1-ND
D1503: Red; LED_0603; Digi-Key PN 754-1117-1-ND
R1501: 10k; R_0603; Tolerance 1%; Digi-Key PN 541-10.0KHCT-ND
R1502, R1503, R1504, R1505, R1506: 1k; R_0603; Tolerance 1%; Digi-Key PN 541-1.00KHCT-ND
U1501, U1502, U1503, U1504, U1505: 74LVC1G97; SOT-363_SC-70-6; Digi-Key PN 296-15582-1-ND

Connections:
GND: C1501.2, C1502.2, C1503.2, C1504.2, C1505.2, R1501.2, U1501.2 (GND), U1502.2 (GND), U1503.2 (GND), U1503.3 (GND), U1504.2 (GND), U1505.2 (GND); also elsewhere on the board
unnamed: D1501.2 (A), R1502.2
unnamed: D1501.1 (K), U1501.4
unnamed: D1502.2 (A), R1503.2
unnamed: D1502.1 (K), U1502.4
unnamed: D1503.2 (A), R1504.2
unnamed: D1503.1 (K), U1503.4
unnamed: D1504.2 (A), R1505.2
unnamed: D1504.1 (K), U1504.4
unnamed: D1505.2 (A), R1506.2
unnamed: D1505.1 (K), U1505.4
PGOOD_LED_SHDN: R1501.1, U1501.3, U1502.3, U1503.6, U1504.3, U1505.3; also elsewhere on the board
POS3P3_PGOOD: U1505.6; also elsewhere on the board
POS24_PGOOD: U1501.6; also elsewhere on the board
POS90_PGOOD: U1504.6; also elsewhere on the board
POS180_PGOOD: U1502.6; also elsewhere on the board
VBAT_PGOOD: U1503.1; also elsewhere on the board

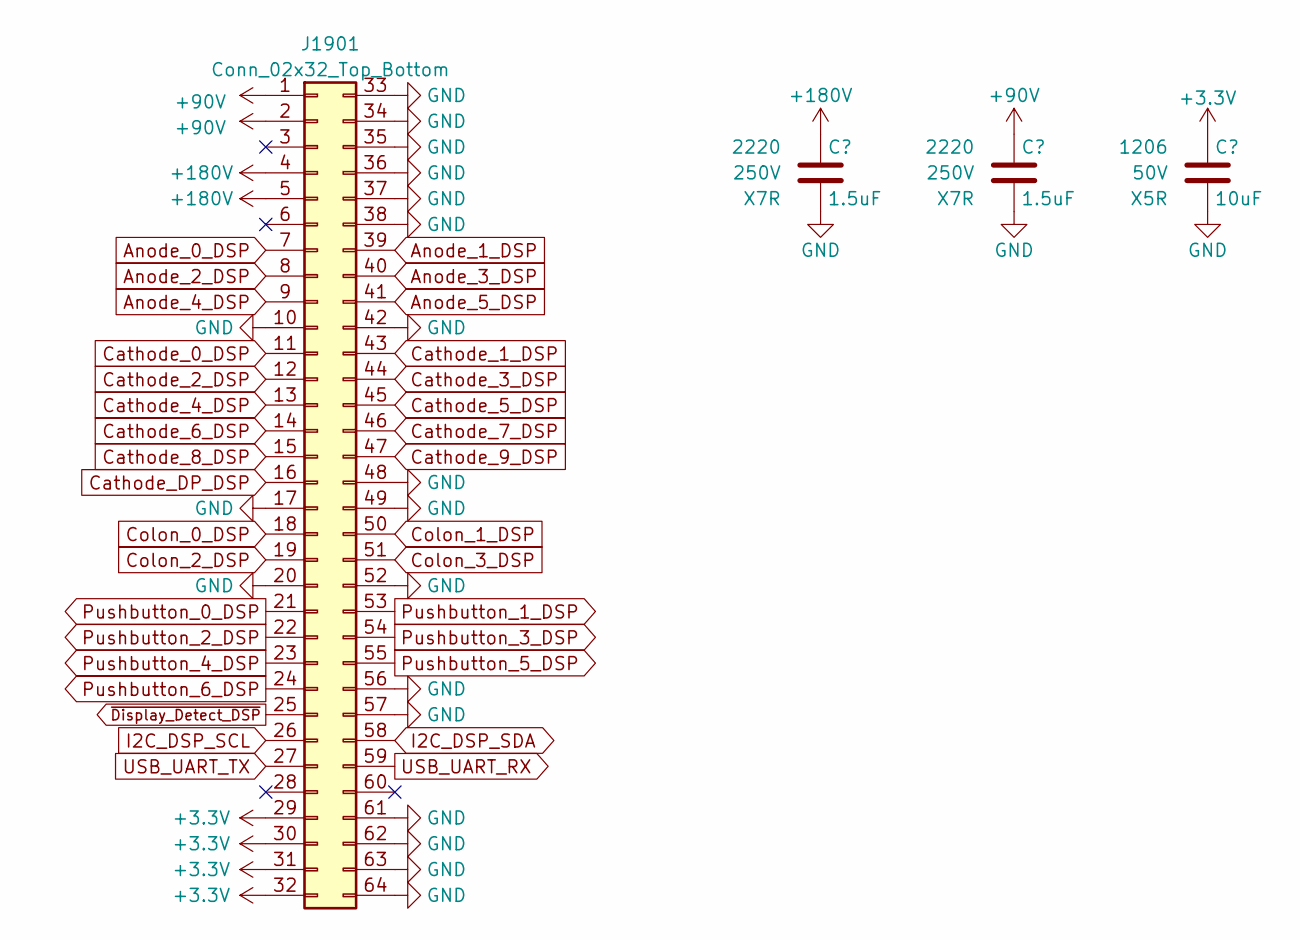
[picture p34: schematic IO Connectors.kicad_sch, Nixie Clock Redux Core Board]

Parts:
C1901, C1902: 1.5uF; C_2220; Voltage 250V; Digi-Key PN 565-4697-1-ND
C1903: 10uF; C_1206; Voltage 50V; Digi-Key PN 1276-6767-1-ND
J1901: Conn_02x32_Top_Bottom; CONN_5120527-1_TYC; Digi-Key PN A97407CT-ND

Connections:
Anode_0_DSP: J1901.7; also elsewhere on the board
Anode_1_DSP: J1901.39; also elsewhere on the board
Anode_2_DSP: J1901.8; also elsewhere on the board
Anode_3_DSP: J1901.40; also elsewhere on the board
Anode_4_DSP: J1901.9; also elsewhere on the board
Anode_5_DSP: J1901.41; also elsewhere on the board
Cathode_0_DSP: J1901.11; also elsewhere on the board
Cathode_1_DSP: J1901.43; also elsewhere on the board
Cathode_2_DSP: J1901.12; also elsewhere on the board
Cathode_3_DSP: J1901.44; also elsewhere on the board
Cathode_4_DSP: J1901.13; also elsewhere on the board
Cathode_5_DSP: J1901.45; also elsewhere on the board
Cathode_6_DSP: J1901.14; also elsewhere on the board
Cathode_7_DSP: J1901.46; also elsewhere on the board
Cathode_8_DSP: J1901.15; also elsewhere on the board
Cathode_9_DSP: J1901.47; also elsewhere on the board
Cathode_DP_DSP: J1901.16; also elsewhere on the board
Colon_0_DSP: J1901.18; also elsewhere on the board
Colon_1_DSP: J1901.50; also elsewhere on the board
Colon_2_DSP: J1901.19; also elsewhere on the board
Colon_3_DSP: J1901.51; also elsewhere on the board
GND: C1901.2, C1902.2, C1903.2, J1901.10, J1901.17, J1901.20, J1901.33, J1901.34, J1901.35, J1901.36, J1901.37, J1901.38, J1901.42, J1901.48, J1901.49, J1901.52, J1901.56, J1901.57, J1901.61, J1901.62, J1901.63, J1901.64; also elsewhere on the board
I2C_DSP_SCL: J1901.26; also elsewhere on the board
I2C_DSP_SDA: J1901.58; also elsewhere on the board
Pushbutton_0_DSP: J1901.21; also elsewhere on the board
Pushbutton_1_DSP: J1901.53; also elsewhere on the board
Pushbutton_2_DSP: J1901.22; also elsewhere on the board
Pushbutton_3_DSP: J1901.54; also elsewhere on the board
Pushbutton_4_DSP: J1901.23; also elsewhere on the board
Pushbutton_5_DSP: J1901.55; also elsewhere on the board
Pushbutton_6_DSP: J1901.24; also elsewhere on the board
USB_UART_RX: J1901.59; also elsewhere on the board
USB_UART_TX: J1901.27; also elsewhere on the board
~Display_Detect_DSP: J1901.25; also elsewhere on the board

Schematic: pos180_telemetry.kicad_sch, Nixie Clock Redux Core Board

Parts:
C701, C702, C703, C704, C705, C706, C707, C708, C709, C710: 0.1uF; C_0603; Voltage 50V; Digi-Key PN 1276-1935-1-ND
D701: BZX58550-C5V1X; D_SOD-523; Digi-Key PN 1727-BZX58550-C5V1XCT-ND
DOC701: 0x20
DOC702: 0x42
Q701: BSS192PH6327FTSA1; SOT-89-3; Digi-Key PN BSS192PH6327FTSA1CT-ND
R701: 2M; R_0603; Tolerance 1%; Digi-Key PN 541-5333-1-ND
R702: 100; R_0603; Tolerance 1%; Digi-Key PN 541-3951-1-ND
R703: 150k; R_0603; Tolerance 1%; Digi-Key PN 541-CRCW0603150KFKTACT-ND
R704, R706, R707, R708: 1k; R_0603; Tolerance 1%; Digi-Key PN 541-1.00KHCT-ND
R705: 75k; R_0603; Tolerance 1%; Digi-Key PN 541-5552-1-ND
U701, U704, U705: OPA333xxDCK; SOT-353_SC-70-5; Digi-Key PN 296-22188-1-ND
U702: MCP9804; DFN-8-1EP_3x2mm_P0.5mm_EP1.3x1.5mm; Digi-Key PN MCP9804T-E/MCCT-ND
U703: INA219BxDCN; SOT-23-8; Digi-Key PN 296-46420-1-ND

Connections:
GND: C701.2, C703.2, C704.2, C705.2, C706.2, C707.2, C708.2, C709.2, C710.2, R701.2, R702.2, R704.2, R706.2, U702.4 (GND), U702.5 (A2), U702.7 (A0), U702.9 (EP/GND), U703.2 (IN-), U703.3 (GND), U703.7 (A0), U704.2 (V-), U705.2 (V-); also elsewhere on the board
I2C_SCL: U702.2 (SCL), U703.5 (SCL); also elsewhere on the board
I2C_SDA: U702.1 (SDA), U703.6 (SDA); also elsewhere on the board
unnamed: C702.2, D701.2 (A), R701.1, U701.2 (V-)
unnamed: C703.1, Q701.2 (D), R702.1, U703.1 (IN+)
unnamed: Q701.1 (G), U701.4
unnamed: C705.1, R703.2, R704.1, U704.1 (+)
unnamed: R707.1, U704.3 (-), U704.4
unnamed: C706.1, R705.2, R706.1, U705.1 (+)
unnamed: R708.1, U705.3 (-), U705.4
POS90_ADC: C708.1, R708.2; also elsewhere on the board
POS180_ADC: C707.1, R707.2; also elsewhere on the board
POS180_SNS+: Q701.3 (S), U701.3 (-); also elsewhere on the board
POS180_SNS-: U701.1 (+); also elsewhere on the board

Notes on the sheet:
POS180 ADC gain = 151 POS90 ADC gain = 76
RSHUNT = 1.5 CLSB = 0.8uA
From TIDU849
Shunt = 1.5 Ohm R_mon = 100 Ohm POS180 Load = 30mA I_FET ~ 450uA V_mon = 45mV P_FET ~ 80mW

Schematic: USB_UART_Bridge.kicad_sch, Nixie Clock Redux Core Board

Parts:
C1301, C1302, C1303, C1305, C1306, C1307, C1310, C1312: 0.1uF; C_0603; Voltage 50V; Digi-Key PN 1276-1935-1-ND
C1304, C1311, C1313: 10uF; C_0603; Voltage 10V; Digi-Key PN 1276-1871-1-ND
C1308, C1309: 47pF; C_0603; Voltage 50V; Digi-Key PN 13-CC0603JPNPO9BN470CT-ND
D1301: Yellow; LED_0603; Digi-Key PN 754-1124-1-ND
D1302: Green; LED_0603; Digi-Key PN 754-1121-1-ND
DOC1301: COM_Port_Settings
J1301: USB_B_Mini; USB_Mini-B; Digi-Key PN 732-2109-1-ND
L1301, L1302: 600R 0.5A; L_0603; Digi-Key PN 490-1014-1-ND
R1301, R1310: 1k; R_0603; Tolerance 1%; Digi-Key PN 541-1.00KHCT-ND
R1302: 487k; R_0603; Tolerance 1%; Digi-Key PN 541-487KHCT-ND
R1303: 6.04k; R_0603; Tolerance 1%; Digi-Key PN 541-CRCW06036K04FKEBCT-ND
R1304: 40.2k; R_0603; Tolerance 1%; Digi-Key PN 541-5412-1-ND
R1305: 10k; R_0603; Tolerance 1%; Digi-Key PN 541-10.0KHCT-ND
R1306, R1307, R1311, R1312: 100k; R_0603; Tolerance 1%; Digi-Key PN 541-100KHCT-ND
R1308, R1309: 27; R_0603; Tolerance 1%; Digi-Key PN 541-5306-1-ND
TP1301: TP; Test_Point
U1301: TLV6700; SOT-23-6; Digi-Key PN 296-51696-1-ND
U1302: FT234XD; DFN-12-1EP_3x3mm_Pitch0.45mm; Digi-Key PN 768-1178-1-ND
U1303: 74LVC1G97; SOT-363_SC-70-6; Digi-Key PN 296-15582-1-ND
U1304: ISO7321C; SOIC-8_3.9x4.9mm_P1.27mm; Digi-Key PN 296-42102-1-ND
U1305: TPD3S014DBVR; SOT-23-6; Digi-Key PN 296-38835-1-ND

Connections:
+3.3V_USB: C1301.1, C1303.1, C1305.1, C1306.1, C1312.1, C1313.1, R1305.1, R1310.1, R1311.1, R1312.1, U1301.5 (Vs), U1302.3 (3V3OUT), U1302.9 (VCCIO), U1303.1 (VCC), U1303.5 (VCC), U1304.8 (VCC2)
+5V_USB: C1302.1, C1304.1, C1307.1, R1301.1, R1302.1, TP1301.1 (TP), U1302.4 (VCC), U1305.4 (OUT)
/USB UART Bridge/BRIDGE_USB+: R1308.2, U1302.12 (USBDP)
/USB UART Bridge/BRIDGE_USB-: R1309.2, U1302.1 (USBDM)
/USB UART Bridge/CONN_USB+: C1308.1, J1301.3 (D+), R1308.1, U1305.6 (D1)
/USB UART Bridge/CONN_USB-: C1309.1, J1301.2 (D-), R1309.1, U1305.5 (D2)
GND: C1310.2, C1311.2, U1304.4 (GND1); also elsewhere on the board
GND_USB: C1301.2, C1302.2, C1303.2, C1304.2, C1305.2, C1306.2, C1307.2, C1308.2, C1309.2, C1312.2, C1313.2, J1301.5 (GND), L1302.1, R1304.2, U1301.2 (GND), U1302.5 (GND), U1302.13 (GND), U1303.2 (GND), U1303.3 (GND), U1304.5 (GND2), U1305.2 (GND)
unnamed: D1301.2 (A), R1301.2
unnamed: D1302.2 (A), R1310.2
unnamed: D1302.1 (K), U1303.4
unnamed: J1301.6 (Shield), L1302.2
unnamed: J1301.1 (VBUS), L1301.1
unnamed: R1302.2, R1303.1, U1301.3 (+INA)
unnamed: R1303.2, R1304.1, U1301.4 (-INB)
unnamed: L1301.2, U1305.1 (EN), U1305.3 (IN)
POS5_USB_PGOOD: R1305.2, U1301.1 (OUTA), U1301.6 (OUTB), U1303.6
USB_UART_RX: R1307.2, U1304.2 (OUTA); also elsewhere on the board
USB_UART_RX_ISO: R1311.2, U1302.7 (TXD), U1304.7 (INA)
USB_UART_TX: R1306.2, U1304.3 (INB); also elsewhere on the board
USB_UART_TX_ISO: R1312.2, U1302.10 (RXD), U1304.6 (OUTB)
~USB_ACTIVE: D1301.1 (K), U1302.6 (CBUS0)

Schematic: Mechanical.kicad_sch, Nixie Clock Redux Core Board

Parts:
H2001, H2002, H2003, H2004, H2005, H2006, H2007, H2008: MountingHole; MountingHole_3mm

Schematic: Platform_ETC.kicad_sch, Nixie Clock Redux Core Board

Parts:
C1401, C1402, C1403: 10uF; C_0603; Voltage 10V; Digi-Key PN 1276-1871-1-ND
C1404: 0.1uF; C_0603; Voltage 50V; Digi-Key PN 1276-1935-1-ND
D1401: BAT48JFILM; D_SOD-323; Digi-Key PN 497-5711-1-ND
DOC1401: 0x6B
U1401: DS1683; SOIC-8_3.9x4.9mm_Pitch1.27mm; Digi-Key PN DS1683S+-ND

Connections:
GND: C1401.2, C1402.2, C1403.2, C1404.2, U1401.4 (GND); also elsewhere on the board
I2C_SCL: U1401.5 (SCL); also elsewhere on the board
I2C_SDA: U1401.6 (SDA); also elsewhere on the board
unnamed: C1401.1, C1402.1, C1403.1, C1404.1, D1401.1 (K), U1401.8 (VCC)

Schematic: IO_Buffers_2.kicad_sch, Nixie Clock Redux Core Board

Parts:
C1801, C1802, C1804: 0.1uF; C_0603; Voltage 50V; Digi-Key PN 1276-1935-1-ND
C1803, C1805: 4.7uF; C_0805; Voltage 16V; Digi-Key PN 1276-2970-1-ND
R1801, R1802, R1803, R1805, R1806: 10K; R_0603; Tolerance 1%; Digi-Key PN 541-10.0KHCT-ND
RN1801, RN1802: 10k; R_Array_Convex_8x0602; Tolerance 1%; Digi-Key PN Y1103CT-ND
U1801: TCA9803; VSSOP-8_3.0x3.0mm_P0.65mm; Digi-Key PN 296-47829-1-ND
U1802: 74VHC541; WQFN-20-1EP_2.5x4.5mm_P0.5mm_EP1x2.9mm; Digi-Key PN 1727-7068-1-ND

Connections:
GND: C1801.2, C1802.2, C1803.2, C1804.2, C1805.2, RN1801.1 (R1.1), RN1801.2 (R2.1), RN1801.3 (R3.1), RN1801.4 (R4.1), RN1801.5 (R5.1), RN1801.6 (R6.1), RN1801.7 (R7.1), RN1801.8 (R8.1), RN1802.1 (R1.1), RN1802.2 (R2.1), RN1802.3 (R3.1), RN1802.4 (R4.1), RN1802.5 (R5.1), RN1802.6 (R6.1), RN1802.7 (R7.1), RN1802.8 (R8.1), U1801.4 (GND), U1802.10 (GND), U1802.21 (GND); also elsewhere on the board
I2C_DSP_SCL: R1805.2, U1801.7 (SCLB); also elsewhere on the board
I2C_DSP_SDA: R1803.2, U1801.6 (SDAB); also elsewhere on the board
I2C_SCL: U1801.2 (SCLA); also elsewhere on the board
I2C_SDA: U1801.3 (SDAA); also elsewhere on the board
Pushbutton_0: RN1801.16 (R1.2), U1802.11 (Y7); also elsewhere on the board
Pushbutton_0_DSP: RN1802.9 (R8.2), U1802.9 (A7); also elsewhere on the board
Pushbutton_1: RN1801.15 (R2.2), U1802.12 (Y6); also elsewhere on the board
Pushbutton_1_DSP: RN1802.10 (R7.2), U1802.8 (A6); also elsewhere on the board
Pushbutton_2: RN1801.14 (R3.2), U1802.13 (Y5); also elsewhere on the board
Pushbutton_2_DSP: RN1802.11 (R6.2), U1802.7 (A5); also elsewhere on the board
Pushbutton_3: RN1801.13 (R4.2), U1802.14 (Y4); also elsewhere on the board
Pushbutton_3_DSP: RN1802.12 (R5.2), U1802.6 (A4); also elsewhere on the board
Pushbutton_4: RN1801.12 (R5.2), U1802.15 (Y3); also elsewhere on the board
Pushbutton_4_DSP: RN1802.13 (R4.2), U1802.5 (A3); also elsewhere on the board
Pushbutton_5: RN1801.11 (R6.2), U1802.16 (Y2); also elsewhere on the board
Pushbutton_5_DSP: RN1802.14 (R3.2), U1802.4 (A2); also elsewhere on the board
Pushbutton_6: RN1801.10 (R7.2), U1802.17 (Y1); also elsewhere on the board
Pushbutton_6_DSP: RN1802.15 (R2.2), U1802.3 (A1); also elsewhere on the board
~Display_Detect_DSP: R1806.2, U1802.2 (A0); also elsewhere on the board
~Display_Detect: R1801.2, U1802.18 (Y0); also elsewhere on the board
~IO_Level_Shift_Enable: R1802.2, U1801.5 (EN), U1802.1 (G1), U1802.19 (G2); also elsewhere on the board

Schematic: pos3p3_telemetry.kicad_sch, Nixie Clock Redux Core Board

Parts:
C501, C502, C503: 0.1uF; C_0603; Voltage 50V; Digi-Key PN 1276-1935-1-ND
DOC501: 0x41
DOC502: 0x19
U501: INA219BxDCN; SOT-23-8; Digi-Key PN 296-46420-1-ND
U502: MCP9804; DFN-8-1EP_3x2mm_P0.5mm_EP1.3x1.5mm; Digi-Key PN MCP9804T-E/MCCT-ND

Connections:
GND: C502.2, C503.2, U501.3 (GND), U501.8 (A1), U502.4 (GND), U502.5 (A2), U502.6 (A1), U502.9 (EP/GND); also elsewhere on the board
I2C_SCL: U501.5 (SCL), U502.2 (SCL); also elsewhere on the board
I2C_SDA: U501.6 (SDA), U502.1 (SDA); also elsewhere on the board
POS3P3_SNS+: C501.1, U501.1 (IN+); also elsewhere on the board
POS3P3_SNS-: C501.2, U501.2 (IN-); also elsewhere on the board

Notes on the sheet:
RSHUNT = 0.02 CLSB = 60uA

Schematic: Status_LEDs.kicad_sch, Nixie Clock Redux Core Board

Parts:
C1601, C1602, C1603, C1604: 0.1uF; C_0603; Voltage 50V; Digi-Key PN 1276-1935-1-ND
D1601: Green; LED_0603; Digi-Key PN 754-1121-1-ND
D1602, D1603, D1604: Red; LED_0603; Digi-Key PN 754-1117-1-ND
R1601, R1602, R1605, R1606: 10k; R_0603; Tolerance 1%; Digi-Key PN 541-10.0KHCT-ND
R1603, R1604, R1607, R1608: 1k; R_0603; Tolerance 1%; Digi-Key PN 541-1.00KHCT-ND
U1601, U1602, U1603, U1604: 74LVC1G97; SOT-363_SC-70-6; Digi-Key PN 296-15582-1-ND

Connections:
CPU_Trap_LED: R1606.1, U1604.6; also elsewhere on the board
Error_LED: R1602.1, U1602.6; also elsewhere on the board
GND: C1601.2, C1602.2, C1603.2, C1604.2, R1601.2, R1602.2, R1606.2, U1601.2 (GND), U1601.3 (GND), U1602.2 (GND), U1602.3 (GND), U1603.2 (GND), U1603.3 (GND), U1604.2 (GND), U1604.3 (GND); also elsewhere on the board
Heartbeat_LED: R1601.1, U1601.6; also elsewhere on the board
unnamed: D1601.2 (A), R1603.2
unnamed: D1601.1 (K), U1601.4
unnamed: D1602.2 (A), R1604.2
unnamed: D1602.1 (K), U1602.4
unnamed: D1603.2 (A), R1607.2
unnamed: D1603.1 (K), U1603.4
unnamed: D1604.2 (A), R1608.2
unnamed: D1604.1 (K), U1604.4
Reset_LED: R1605.2, U1603.6; also elsewhere on the board

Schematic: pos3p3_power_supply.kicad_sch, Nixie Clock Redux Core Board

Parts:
C401, C403, C407, C408: 10uF; C_1206; Voltage 50V; Digi-Key PN 1276-6767-1-ND
C402: 4.7uF; C_0805; Voltage 16V; Digi-Key PN 1276-2970-1-ND
C404: 10nF; C_0603; Voltage 50V; Digi-Key PN 1276-1009-1-ND
C405: 10uF; C_0603; Voltage 10V; Digi-Key PN 1276-1871-1-ND
C406: 0.1uF; C_0603; Voltage 50V; Digi-Key PN 1276-1935-1-ND
C409: 47pF; C_0603; Voltage 50V; Digi-Key PN 13-CC0603JPNPO9BN470CT-ND
D401: BAT48JFILM; D_SOD-323; Digi-Key PN 497-5711-1-ND
L401: 2.2uH; L_Vishay_IHLP-2020; Tolerance 20%; Digi-Key PN 541-1268-1-ND
Q401: BSS214NW; SOT-323_SC-70; Digi-Key PN BSS214NWH6327XTSA1CT-ND
Q402: ZXMS6004FFTA; SOT-23; Digi-Key PN ZXMS6004FFCT-ND
R401, R405, R407: 10; R_0603; Tolerance 1%; Digi-Key PN 541-10.0HCT-ND
R402, R404: 10k; R_0603; Tolerance 1%; Digi-Key PN 541-10.0KHCT-ND
R403: 18.2k; R_0603; Tolerance 1%; Digi-Key PN 541-18.2KHCT-ND
R406: 0.02; R_0612; Tolerance 1%; Digi-Key PN P16010CT-ND
R408: 1M; R_0603; Tolerance 1%; Digi-Key PN 541-1.00MHCT-ND
R409: 309k; R_0603; Tolerance 1%; Digi-Key PN 541-309KHCT-ND
TP401: TP; Test_Point
U401: LT8609A-DD; DFN-10-1EP_3x3mm_Pitch0.5mm; Digi-Key PN 505-LT8609AEDDM#TRPBFCT-ND

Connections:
+24V: C401.1, C403.1, U401.9 (VIN); also elsewhere on the board
GND: C401.2, C402.2, C403.2, C404.2, C405.2, C407.2, C408.2, Q401.2 (S), Q402.2 (S), R403.2, R409.2, U401.11 (GND); also elsewhere on the board
unnamed: C407.1, C408.1, L401.2, R405.2, R406.1
unnamed: C405.1, D401.1 (K), R404.1
unnamed: Q401.3 (D), Q402.1 (G), R404.2
unnamed: C406.1, U401.1 (BST)
unnamed: C409.2, R408.2, R409.1, U401.6 (FB)
unnamed: C402.1, U401.3 (INTVCC), U401.5 (SYNC)
unnamed: R403.1, U401.4 (RT)
unnamed: C406.2, L401.1, U401.2 (SW)
unnamed: C404.1, U401.7 (TR/SS)
POS3P3_PGOOD: R402.2, U401.8 (PG); also elsewhere on the board
POS3P3_RUN: Q401.1 (G), R401.2, U401.10 (EN/UV)
POS3P3_SNS+: R405.1; also elsewhere on the board
POS3P3_SNS-: R407.1; also elsewhere on the board
POS24_PGOOD: R401.1; also elsewhere on the board

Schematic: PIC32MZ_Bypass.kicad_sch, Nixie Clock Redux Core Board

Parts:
C901, C902, C905, C906, C909, C910, C913, C914: 0.1uF; C_0603; Voltage 50V; Digi-Key PN 1276-1935-1-ND
C903, C904, C907, C908, C911, C912, C915, C916: 10uF; C_0603; Voltage 10V; Digi-Key PN 1276-1871-1-ND
L901, L902: 600R 0.5A; L_0603; Digi-Key PN 490-1014-1-ND

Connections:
+3.3VA_MZ: C914.1, C916.1, L901.1; also elsewhere on the board
GND: C901.2, C902.2, C903.2, C904.2, C905.2, C906.2, C907.2, C908.2, C909.2, C910.2, C911.2, C912.2, C913.2, C915.2, L902.2; also elsewhere on the board
GNDA_MZ: C914.2, C916.2, L902.1; also elsewhere on the board

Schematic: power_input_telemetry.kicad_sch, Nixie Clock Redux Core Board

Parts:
C301, C302, C303: 0.1uF; C_0603; Voltage 50V; Digi-Key PN 1276-1935-1-ND
DOC301: 0x40
DOC302: 0x18
U301: INA219BxDCN; SOT-23-8; Digi-Key PN 296-46420-1-ND
U302: MCP9804; DFN-8-1EP_3x2mm_P0.5mm_EP1.3x1.5mm; Digi-Key PN MCP9804T-E/MCCT-ND

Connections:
GND: C302.2, C303.2, U301.3 (GND), U301.7 (A0), U301.8 (A1), U302.4 (GND), U302.5 (A2), U302.6 (A1), U302.7 (A0), U302.9 (EP/GND); also elsewhere on the board
I2C_SCL: U301.5 (SCL), U302.2 (SCL); also elsewhere on the board
I2C_SDA: U301.6 (SDA), U302.1 (SDA); also elsewhere on the board
POS24_SNS+: C301.1, U301.1 (IN+); also elsewhere on the board
POS24_SNS-: C301.2, U301.2 (IN-); also elsewhere on the board

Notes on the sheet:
RSHUNT = 0.02 CLSB = 60uA

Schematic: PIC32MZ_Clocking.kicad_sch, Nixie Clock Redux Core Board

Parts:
C1101, C1102, C1103: 0.1uF; C_0603; Voltage 50V; Digi-Key PN 1276-1935-1-ND
C1104, C1105: 10uF; C_0603; Voltage 10V; Digi-Key PN 1276-1871-1-ND
L1101, L1102: 600R 0.5A; L_0603; Digi-Key PN 490-1014-1-ND
R1101, R1102, R1105, R1106: 10k; R_0603; Tolerance 1%; Digi-Key PN 541-10.0KHCT-ND
R1103, R1104: 10; R_0603; Tolerance 1%; Digi-Key PN 541-10.0HCT-ND
TP1101: TP; Test_Point
U1101: 74LVC1G97; SOT-363_SC-70-6; Digi-Key PN 296-15582-1-ND
X1101: ASE-8.000MHz; Oscillator_SMD_Abracon_ASE-4Pin_3.2x2.5mm; Digi-Key PN 535-9558-1-ND
X1102: ECS-327KE; Digi-Key PN XC1751CT-ND

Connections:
GND: C1101.2, C1102.2, C1103.2, C1104.2, C1105.2, R1101.2, R1102.2, R1105.2, R1106.2, U1101.2 (GND), U1101.3 (GND), U1101.6 (GND), X1101.2 (GND), X1102.2 (GND); also elsewhere on the board
unnamed: R1103.1, R1105.1, X1101.3 (OUT)
unnamed: C1102.1, C1104.1, L1101.1, X1101.4 (Vdd)
unnamed: R1104.1, R1106.1, X1102.3 (OUT)
unnamed: C1103.1, C1105.1, L1102.1, X1102.4 (Vdd)
PIC32MZ_CLK_EN: R1102.1, U1101.4, X1101.1 (EN), X1102.1 (EN)
PIC32MZ_POSC_EC: R1103.2; also elsewhere on the board
PIC32MZ_REFCLK1: R1101.1, TP1101.1 (TP); also elsewhere on the board
PIC32MZ_SOSC_EC: R1104.2; also elsewhere on the board
POS3P3_PGOOD: U1101.1; also elsewhere on the board

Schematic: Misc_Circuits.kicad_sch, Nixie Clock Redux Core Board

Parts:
BZ2101: CST-931RP-A; MagneticBuzzer_CUI_CST-931RP-A; Digi-Key PN 102-1461-ND
C2101, C2102, C2103: 0.1uF; C_0603; Voltage 50V; Digi-Key PN 1276-1935-1-ND
D2101: SMD1200PL; D_SOD-123F; Digi-Key PN SMD1200PL-TPMSCT-ND
DOC2101: 0x1C
J2101: I2C; PinHeader_1x03_P2.54mm_Vertical
J2102: USB UART; PinHeader_1x03_P2.54mm_Vertical
Q2101: BSS214NW; SOT-323_SC-70; Digi-Key PN BSS214NWH6327XTSA1CT-ND
R2101: 1.07M; R_0603; Tolerance 1%; Digi-Key PN 541-1.07MHCT-ND
R2102, R2104, R2105, R2107, R2108, R2111: 10k; R_0603; Tolerance 1%; Digi-Key PN 541-10.0KHCT-ND
R2103, R2106, R2109, R2110: 10; R_0603; Tolerance 1%; Digi-Key PN 541-10.0HCT-ND
U2101: LTC6900; SOT-23-5; Digi-Key PN LTC6900CS5#TRMPBFCT-ND
U2102: 74LVC1G97; SOT-363_SC-70-6; Digi-Key PN 296-15582-1-ND
U2103: MCP9804; DFN-8-1EP_3x2mm_P0.5mm_EP1.3x1.5mm; Digi-Key PN MCP9804T-E/MCCT-ND

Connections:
Buzzer_Enable: R2107.2, U2102.3; also elsewhere on the board
ETC_Hardstrap: R2105.2, R2106.1; also elsewhere on the board
GND: C2101.2, C2102.2, C2103.2, J2101.3, J2102.3, Q2101.2 (S), R2103.2, R2104.1, R2106.2, R2107.1, R2109.2, R2111.1, U2101.2 (GND), U2102.1 (GND), U2102.2 (GND), U2103.4 (GND), U2103.6 (A1), U2103.7 (A0), U2103.9 (EP/GND); also elsewhere on the board
I2C_SCL: J2101.1, U2103.2 (SCL); also elsewhere on the board
I2C_SDA: J2101.2, U2103.1 (SDA); also elsewhere on the board
unnamed: BZ2101.2 (+), D2101.2 (A), Q2101.3 (D)
unnamed: Q2101.1 (G), R2110.1, R2111.2
unnamed: R2110.2, U2102.4
unnamed: R2104.2, U2101.5 (OUT), U2102.6
unnamed: R2101.2, U2101.3 (SET)
RTC_Hardstrap: R2108.2, R2109.1; also elsewhere on the board
Telemetry_Hardstrap: R2102.2, R2103.1; also elsewhere on the board
USB_UART_RX: J2102.2; also elsewhere on the board
USB_UART_TX: J2102.1; also elsewhere on the board

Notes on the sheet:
Fosc ~ 2kHz
Place away from power components

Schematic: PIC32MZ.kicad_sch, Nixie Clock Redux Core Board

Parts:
R1001, R1002: 10k; R_0603; Tolerance 1%; Digi-Key PN 541-10.0KHCT-ND
U1001: PIC32MZ2048EFG100_IPF; TQFP-100_14x14mm_Pitch0.5mm; Digi-Key PN PIC32MZ2048EFG100-I/PF-ND

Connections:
+3.3VA_MZ: U1001.30 (AVDD); also elsewhere on the board
Anode_0: U1001.25 (RB0/PGED1/AN0/RPB0); also elsewhere on the board
Anode_1: U1001.24 (RB1/PGEC1/AN1/RPB1); also elsewhere on the board
Anode_2: U1001.23 (RB2/AN2/C2INB/RPB2); also elsewhere on the board
Anode_3: U1001.22 (RB3/AN3/C2INA/RPB3); also elsewhere on the board
Anode_4: U1001.21 (RB4/AN4/C1INB); also elsewhere on the board
Anode_5: U1001.20 (RB5/AN45/C1INA/RPB5); also elsewhere on the board
Buzzer_Enable: U1001.68 (RD9/EBIA15/RPD9/PMCS2/PMA15); also elsewhere on the board
CPU_Trap_LED: U1001.94 (RE1/EBID1/PMD1); also elsewhere on the board
Cathode_0: U1001.32 (RB8/EBIA10/AN48/RPB8/PMA10); also elsewhere on the board
Cathode_1: U1001.33 (RB9/EBIA7/AN49/RPB9/PMA7); also elsewhere on the board
Cathode_2: U1001.34 (RB10/EBIA13/CVREFOUT/AN5/RPB10/PMA13); also elsewhere on the board
Cathode_3: U1001.35 (RB11/AN6/ERXERR/AETXERR); also elsewhere on the board
Cathode_4: U1001.41 (RB12/EBIA11/AN7/ERXD0/AECRS/PMA11); also elsewhere on the board
Cathode_5: U1001.42 (RB13/AN8/ERXD1/AECOL); also elsewhere on the board
Cathode_6: U1001.43 (RB14/EBIA1/AN9/ERXD2/AETXD3/RPB14/SCK3/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); also elsewhere on the board
Cathode_7: U1001.44 (RB15/EBIA0/AN10/ERXD3/AETXD2/RPB15/OCFB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); also elsewhere on the board
Cathode_8: U1001.19 (RE9/AN26/AERXD1/RPE9); also elsewhere on the board
Cathode_9: U1001.18 (RE8/AN25/AERXD0/RPE8); also elsewhere on the board
Cathode_DP: U1001.17 (RA0/TMS/EBIA16/AN24); also elsewhere on the board
Colon_0: U1001.100 (RE4/EBID4/AN18/PMD4); also elsewhere on the board
Colon_1: U1001.99 (RE3/EBID3/RPE3/PMD3); also elsewhere on the board
Colon_2: U1001.98 (RE2/EBID2/PMD2); also elsewhere on the board
Colon_3: U1001.97 (RG13/TRD0/SQID0); also elsewhere on the board
ETC_Hardstrap: U1001.40 (RF12/TDO/EBIA17/AN31/RPF12); also elsewhere on the board
Error_LED: U1001.2 (RA5/EBIA5/AN34/PMA5); also elsewhere on the board
GND: U1001.13 (VSS), U1001.36 (VSS), U1001.45 (VSS), U1001.52 (VBUS3V3), U1001.53 (VSS), U1001.63 (VSS), U1001.75 (VSS), U1001.84 (VSS), U1001.92 (VSS); also elsewhere on the board
GNDA_MZ: U1001.31 (AVSS); also elsewhere on the board
Heartbeat_LED: U1001.91 (RE0/EBID0/PMD0); also elsewhere on the board
I2C_SCL: R1002.2, U1001.65 (RF5/EBIA8/RPF5/SCL5/PMA8); also elsewhere on the board
I2C_SDA: R1001.2, U1001.64 (RF4/EBIA9/RPF4/SDA5/PMA9); also elsewhere on the board
PGOOD_LED_SHDN: U1001.96 (RG12/TRD1/SQID1); also elsewhere on the board
PIC32MZ_ICSPCLK: U1001.26 (RB6/PGEC2/AN46/RPB6); also elsewhere on the board
PIC32MZ_ICSPDAT: U1001.27 (RB7/PGED2/AN47/RPB7); also elsewhere on the board
PIC32MZ_POSC_EC: U1001.49 (RC12/OSC1/CLKI); also elsewhere on the board
PIC32MZ_REFCLK1: U1001.72 (RC13/SOSCI/RPC13); also elsewhere on the board
PIC32MZ_SOSC_EC: U1001.73 (RC14/SOSCO/RPC14/T1CK); also elsewhere on the board
POS3P3_PGOOD: U1001.87 (RG1/EBID9/ETXERR/RPG1/PMD9); also elsewhere on the board
POS24_PGOOD: U1001.88 (RG0/EBID8/RPG0/PMD8); also elsewhere on the board
POS90_ADC: U1001.9 (RC4/~EBIOE/AN19/RPC4/PMRD); also elsewhere on the board
POS90_PGOOD: U1001.38 (RA1/TCK/EBIA19/AN29); also elsewhere on the board
POS180_ADC: U1001.8 (RC3/~EBIWE/AN20/RPC3/PMWR); also elsewhere on the board
POS180_PGOOD: U1001.29 (RA10/VREF+/CVREF+/AN28/AERXD3); also elsewhere on the board
POS180_RUN: U1001.28 (RA9/VREF-/CVREF-/AN27/AERXD2); also elsewhere on the board
Pushbutton_0: U1001.71 (RD0/EMDIO/AEMDIO/RPD0/RTCC/INT0); also elsewhere on the board
Pushbutton_1: U1001.76 (RD1/RPD1/SCK1); also elsewhere on the board
Pushbutton_2: U1001.77 (RD2/EBID14/ETXEN/RPD2/PMD14); also elsewhere on the board
Pushbutton_3: U1001.78 (RD3/EBID15/ETXCLK/RPD3/PMD15); also elsewhere on the board
Pushbutton_4: U1001.79 (RD12/EBID12/ETXD2/RPD12/PMD12); also elsewhere on the board
Pushbutton_5: U1001.80 (RD13/EBID13/ETXD3/PMD13); also elsewhere on the board
Pushbutton_6: U1001.81 (RD4/~SQICS0/RPD4); also elsewhere on the board
RTC_Hardstrap: U1001.39 (RF13/TDI/EBIA18/AN30/RPF13/SCK5); also elsewhere on the board
Reset_LED: U1001.1 (RG15/AN23/AERXERR); also elsewhere on the board
Telemetry_Hardstrap: U1001.58 (RF8/EBIRDY2/RPF8/SCL3); also elsewhere on the board
USB_UART_RX: U1001.85 (RF0/EBID11/ETXD1/RPF0/PMD11); also elsewhere on the board
USB_UART_TX: U1001.86 (RF1/EBID10/ETXD0/RPF1/PMD10); also elsewhere on the board
VBAT_ADC: U1001.7 (RC2/EBIA12/AN21/RPC2/PMA12); also elsewhere on the board
VBAT_PGOOD: U1001.48 (RD15/AN33/AETXD1/RPD15/SCK6); also elsewhere on the board
~Display_Detect: U1001.82 (RD5/~SQICS1/RPD5); also elsewhere on the board
~IO_Level_Shift_Enable: U1001.90 (RA7/TRD3/SQID3); also elsewhere on the board
~PIC32MZ_MCLR: U1001.15 (~MCLR); also elsewhere on the board

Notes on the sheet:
POSC
OC1
U3RX
U3TX
AN20
ICSP2DAT
SDA5
REFCLKO1
AN19
ICSP2CLK
SCL5
SOSC
AN21

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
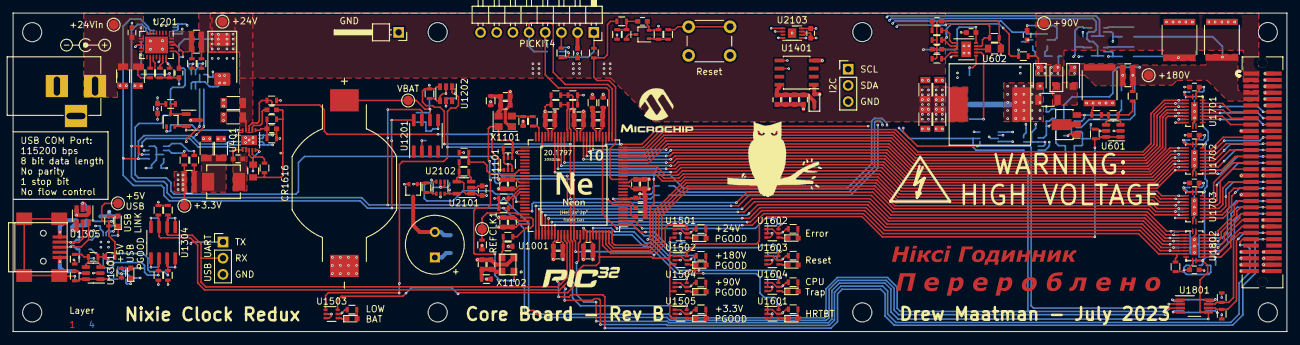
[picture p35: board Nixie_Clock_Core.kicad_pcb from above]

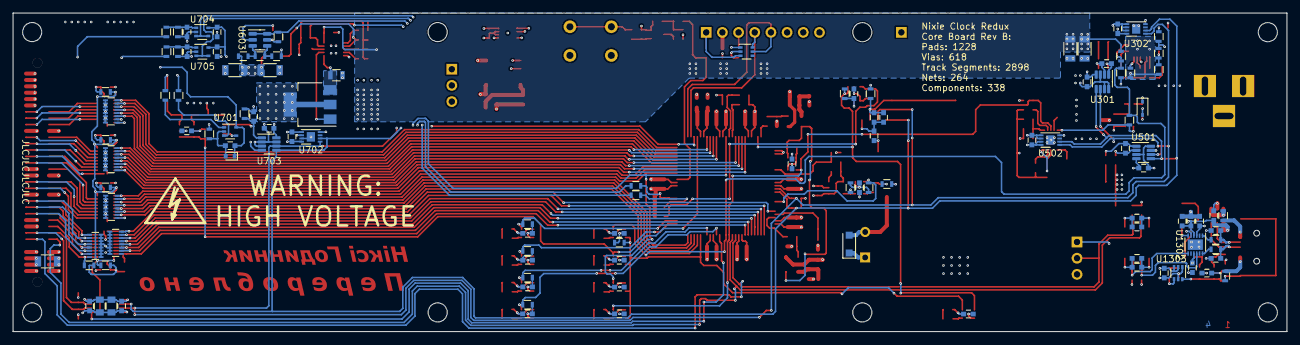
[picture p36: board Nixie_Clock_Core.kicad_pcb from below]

Board: 4 copper layers, 200.0 x 50.0 mm, 330 parts (115 on the bottom side), 201 nets.

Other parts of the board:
TP601, TP602: TP; Test_Point

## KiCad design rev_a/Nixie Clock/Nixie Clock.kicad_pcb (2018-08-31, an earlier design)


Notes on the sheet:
Table of Contents
1. Power Input 2. Controller Supply 3. Display Supply 4. Microcontroller 5. Lowside Decoder 6. Backup Supply 7. Highside Decoder 8. Lowside Switches 9. Highside Switches 10. Colon Switch 11. Input/Output 12. Time Set 13. External Oscillator 14. Connectors

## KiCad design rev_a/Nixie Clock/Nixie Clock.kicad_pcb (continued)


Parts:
C201: 0.1uF; C_0402; Voltage 50V; Tolerance 10%
C202: 10nF; C_0402; Voltage 50V; Tolerance 10%
C203: 1nF; C_0402; Voltage 50V; Tolerance 10%
D201, D202: SMD1200PL; D_SOD-123F
D203: 3.3V; D_SOD-323; Part Number PESD3V3L1BA
F201: 3A; R_1206
J201: Power Input; BARREL_JACK
Q201: Si4946; SOIC-8_3.9x4.9mm_Pitch1.27mm
R201: 100k; R_0402; Tolerance 5%
R202, R207: 1M; R_0402; Tolerance 5%
R203: 1.3M; R_0402; Tolerance 1%
R204, R208: 100; R_0402; Tolerance 5%
R205: 4.64k; R_0402; Tolerance 1%
R206: 25.5k; R_0402; Tolerance 1%
U201: LTC4365IDDB; DFN-8-1EP_2x3mm_Pitch0.5mm

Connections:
/Power Input/PlugSense: J201.3, R208.1
/Power Input/Vin_Gate: Q201.2 (G), Q201.4 (G), U201.5 (Gate)
/Power Input/Vin_OV: R205.2, R206.1, U201.2 (OV)
/Power Input/Vin_SHDN: R201.2, U201.8 (~SHDN)
/Power Input/Vin_Source: Q201.1 (S), Q201.3 (1)
/Power Input/Vin_UV: R203.2, R205.1, U201.3 (UV)
/Power Input/Vin_Unfused: F201.1, J201.1
GND: C201.2, C202.2, C203.2, D202.2 (A), D203.1, J201.2, R206.2, U201.1 (GND), U201.9 (GND); also elsewhere on the board
unnamed: R204.1, U201.7 (~FAULT)
PLUG: D201.2 (A), D202.1 (K), D203.2, R207.2, R208.2; also elsewhere on the board
VCC_BCKUP: D201.1 (K), R202.1, R207.1; also elsewhere on the board
VCOM: Q201.5, Q201.6 (D), U201.6 (VOUT); also elsewhere on the board
VCOM_PGOOD: R202.2, R204.2; also elsewhere on the board
Vin: C201.1, C202.1, C203.1, F201.2, Q201.7, Q201.8 (D), R201.1, R203.1, U201.4 (Vin)

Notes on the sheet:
Overvoltage/Undervoltage/Reverse Polarity Lockout
VIN: MIN 22V, NOM 24V, MAX 26V
Input Presence Detection


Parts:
C301: 0.47uF; C_0402; Voltage 25V; Tolerance 10%
C302: 4.7uF; C_1206; Voltage 35V; Tolerance 20%
C303: 22uF; C_0805; Voltage 6.3V; Tolerance 20%
C304: 15pF; C_0402; Voltage 50V; Tolerance 10%
L301: 10uH; IHLP-2525CZ-01; Tolerance 10%
R301, R304: 1M; R_0402; Tolerance 5%
R302: 100; R_0402; Tolerance 5%
R303: 2.2M; R_0402; Tolerance 1%
R305: 1.3M; R_0402; Tolerance 1%
R306: 115k; R_0402; Tolerance 1%
U301: LT3973-DD; DFN-10-1EP_3x3mm_Pitch0.5mm

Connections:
+3V3: C303.1, C304.1, L301.2, R303.1, U301.2 (OUT), U301.8 (BD); also elsewhere on the board
/Controller Supply/3P3_BOOST: C301.1, U301.7 (BOOST)
/Controller Supply/3P3_FB: C304.2, R303.2, R305.1, U301.1 (FB)
/Controller Supply/3P3_PGOODR: R301.2, R302.2, U301.9 (PG)
/Controller Supply/3P3_RT: R306.1, U301.10 (RT)
/Controller Supply/3P3_RUN: R304.2, U301.3 (EN/UVLO)
/Controller Supply/3P3_SW: C301.2, L301.1, U301.6 (SW)
GND: C302.2, C303.2, R305.2, R306.2, U301.5 (GND), U301.11 (GND); also elsewhere on the board
VCC_BCKUP: R301.1; also elsewhere on the board
VCC_PGOOD: R302.1; also elsewhere on the board
VCOM: C302.1, R304.1, U301.4 (VIN); also elsewhere on the board

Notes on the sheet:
Monolithic Buck Switching Regulator with Burst Mode and PGOOD flag +3.3 Volts, 300mA @ 2.2MHz


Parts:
C401, C402, C404: 0.1uF; C_0805; Voltage 100V; Tolerance 10%
C403: 1.5uF; C_2220; Voltage 250V; Tolerance 10%
C405: 10uF; C_1206; Voltage 35V; Tolerance 10%
C406, C409: 0.1uF; C_0402; Voltage 25V; Tolerance 10%
C407: 4.7uF; C_0805; Voltage 10V; Tolerance 10%
C408: 6.8nF; C_0402; Voltage 50V; Tolerance 10%
C410: 10nF; C_0402; Voltage 25V; Tolerance 10%
C411: 1nF; C_0402; Voltage 25V; Tolerance 10%
D401, D402, D403: SMD1200PL; D_SOD-123F
L401: 680uH; Wurth_7447709681; Tolerance 20%
Q401: IRFL214; SOT-223_3
R401: 27k; R_2512; Tolerance 5%
R402, R413: 100; R_0402; Tolerance 5%
R403: 10k; R_0402; Tolerance 5%
R404: 0.16; R_0805; Tolerance 1%
R405: 1.5M; R_0603; Tolerance 1%
R406: 14k; R_0402; Tolerance 5%
R407: 27k; R_0603; Tolerance 1%
R408: 22k; R_0402; Tolerance 1%
R409: 1M; R_0402; Tolerance 5%
R410: 1.6M; R_0402; Tolerance 1%
R411: 330; R_0402; Tolerance 1%
R412: 3.4k; R_0402; Tolerance 1%
U401: LT3757; DFN-10-1EP_3x3mm_Pitch0.5mm
U402: LT6700-1-S6; SOT-23-6

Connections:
+3V3: C409.1, C410.1, C411.1, U402.5 (Vs); also elsewhere on the board
/Display Supply/VVVINA: R410.2, R411.1, U402.3 (+INA)
/Display Supply/VVVINB: R411.2, R412.1, U402.4 (-INB)
/Display Supply/VVV_CS: Q401.3 (S), R404.1, U401.6 (SENSE)
/Display Supply/VVV_FBX: R405.2, R407.1, U401.2 (FBX)
/Display Supply/VVV_GATE: Q401.1 (G), U401.7 (GATE)
/Display Supply/VVV_RT: R406.1, U401.4 (RT)
/Display Supply/VVV_RUN_R: R402.2, R403.1, U401.9 (~SHDN~/UVLO)
/Display Supply/VVV_SS: C406.1, U401.3 (SS)
/Display Supply/VVV_SW1: C401.2, D403.2 (A), L401.2, Q401.2 (D), Q401.4
/Display Supply/VVV_SW2: C402.2, C404.1, D402.2 (A), D403.1 (K), R405.1
/Display Supply/VVV_SW3: C401.1, D401.2 (A), D402.1 (K)
GND: C403.2, C404.2, C405.2, C406.2, C407.2, C408.2, C409.2, C410.2, C411.2, R401.2, R403.2, R404.2, R406.2, R407.2, R412.2, U401.5 (SYNC), U401.11 (GND), U402.2 (GND); also elsewhere on the board
unnamed: C407.1, U401.8 (INTVCC)
unnamed: C408.1, R408.2
unnamed: R408.1, U401.1 (VC)
unnamed: R409.2, R413.1, U402.1 (OUTA), U402.6 (OUTB)
VCC_BCKUP: R409.1; also elsewhere on the board
VCOM: C405.1, L401.1, U401.10 (VIN); also elsewhere on the board
VVV_PGOOD: R413.2; also elsewhere on the board
VVV_RUN: R402.1; also elsewhere on the board
Vvv: C402.1, C403.1, D401.1 (K), R401.1, R410.1; also elsewhere on the board

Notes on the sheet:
Valve High Voltage Supply Hybrid Boost Converter/Voltage Multiplier 180V, 30mA @ 800kHz
VVV PGOOD Window Comparator


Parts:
C501: 0.1uF; C_0402; Voltage 25V; Tolerance 10%
C502: 10nF; C_0402; Voltage 25V; Tolerance 10%
C503: 1nF; C_0402; Voltage 25V; Tolerance 10%
C504, C505: 12pF; C_0402; Voltage 50V; Tolerance 10%
J501: PicKit3_Header; Pin_Header_Angled_1x06_Pitch2.54mm
R501: 10k; R_0402; Tolerance 5%
R502: 1M; R_0402; Tolerance 5%
U501: PIC16LF1519-I/MV; QFN-40-1EP_5x5mm_Pitch0.4mm
Y501: 20MHz; CX5032GB20000H0PESZZ; Part Number CX5032GB20000H0PESZZ

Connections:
24hr: U501.40 (TX/CK/AN18/RC6); also elsewhere on the board
BCDA: U501.34 (AN20/RD0); also elsewhere on the board
BCDB: U501.35 (AN21/RD1); also elsewhere on the board
BCDC: U501.36 (AN22/RD2); also elsewhere on the board
BCDD: U501.37 (AN23/RD3); also elsewhere on the board
BCOA: U501.2 (AN24/RD4); also elsewhere on the board
BCOB: U501.3 (AN25/RD5); also elsewhere on the board
BCOC: U501.4 (AN26/RD6); also elsewhere on the board
ColonDrive0: U501.33 (SCK/SCL/AN15/RC3); also elsewhere on the board
ColonDrive1: U501.38 (SDI/SDA/AN16/RC4); also elsewhere on the board
EXT_OSC: U501.30 (SOSCO/T1CKI/RC0); also elsewhere on the board
EnableInd: U501.23 (RE0/AN5); also elsewhere on the board
ErrorInd: U501.25 (RE2/AN7); also elsewhere on the board
GND: C501.2, C502.2, C503.2, C504.2, C505.2, J501.3 (Vss), R501.2, U501.6 (VSS), U501.27 (VSS), U501.41; also elsewhere on the board
ICSPCLK: J501.5 (ICSPCLK), U501.14 (RB6/ICSPCLK/ICDCLK)
ICSPDAT: J501.4 (ICSPDAT), U501.15 (RB7/ICSPDAT/ICDDAT)
LowSideBaseDec: U501.32 (CCP1/AN14/RC2); also elsewhere on the board
unnamed: R501.1, U501.21 (RA4/T0CKI)
OSC1: C505.1, U501.28 (RA7/OSC1/CLKIN), Y501.2
OSC2: C504.1, U501.29 (RA6/OSC2/CLKOUT), Y501.1
PLUG: U501.13 (RB5/AN13/T1G); also elsewhere on the board
TickInd: U501.24 (RE1/AN6); also elsewhere on the board
VCC_BCKUP: C501.1, C502.1, C503.1, J501.2 (Vdd), R502.1, U501.7 (VDD), U501.26 (VDD); also elsewhere on the board
VCC_BCKUP_PGOOD: U501.1 (RX/DT/AN19/RC7); also elsewhere on the board
VCC_PGOOD: U501.17 (RA0/AN0/~SS); also elsewhere on the board
VCOM_PGOOD: U501.22 (RA5/AN4/VCAP/~SS); also elsewhere on the board
VVV_PGOOD: U501.19 (RA2/AN2); also elsewhere on the board
VVV_RUN: U501.20 (RA3/AN3/Vref+); also elsewhere on the board
~ConnSense: U501.39 (SDO/AN17/RC5); also elsewhere on the board
~DSPLY_TGL: U501.11 (RB3/AN9/CCP2); also elsewhere on the board
~DecodeEN: U501.5 (AN27/RD7); also elsewhere on the board
~MCLR: J501.1 (Vpp/~MCLR), R502.2, U501.16 (RE3/~MCLR~/Vpp)
~SetHours: U501.10 (RB2/AN8); also elsewhere on the board
~SetMinutes: U501.9 (RB1/AN10); also elsewhere on the board
~SetSeconds: U501.8 (RB0/AN12/INT); also elsewhere on the board
~VCC_BCKUP_PFO: U501.12 (RB4/AN11); also elsewhere on the board

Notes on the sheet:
8 Bit PIC Microcontroller


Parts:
C601: 0.1uF; C_0402; Voltage 25V; Tolerance 10%
C602: 10nF; C_0402; Voltage 25V; Tolerance 10%
C603: 1nF; C_0402; Voltage 25V; Tolerance 10%
R601, R607, R608, R609, R610: 10k; R_0402; Tolerance 5%
R602, R603, R604, R605, R606: 100; R_0402; Tolerance 5%
U601: 74HC4514; SOIC-24W_7.5x15.4mm_Pitch1.27mm

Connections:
+3V3: C601.1, C602.1, C603.1, R601.1, U601.24 (VCC); also elsewhere on the board
/Lowside Decoder/BCDA_R: R603.1, R610.1, U601.2 (A0)
/Lowside Decoder/BCDB_R: R604.1, R609.1, U601.3 (A1)
/Lowside Decoder/BCDC_R: R605.1, R608.1, U601.21 (A2)
/Lowside Decoder/BCDD_R: R606.1, R607.1, U601.22 (A3)
/Lowside Decoder/BCDEN_R: R601.2, R602.1, U601.23 (~E)
BCDA: R603.2; also elsewhere on the board
BCDB: R604.2; also elsewhere on the board
BCDC: R605.2; also elsewhere on the board
BCDD: R606.2; also elsewhere on the board
GND: C601.2, C602.2, C603.2, R607.2, R608.2, R609.2, R610.2, U601.1 (~LE), U601.12 (GND); also elsewhere on the board
LowSideBase0: U601.11 (Y0); also elsewhere on the board
LowSideBase1: U601.9 (Y1); also elsewhere on the board
LowSideBase2: U601.10 (Y2); also elsewhere on the board
LowSideBase3: U601.8 (Y3); also elsewhere on the board
LowSideBase4: U601.7 (Y4); also elsewhere on the board
LowSideBase5: U601.6 (Y5); also elsewhere on the board
LowSideBase6: U601.5 (Y6); also elsewhere on the board
LowSideBase7: U601.4 (Y7); also elsewhere on the board
LowSideBase8: U601.18 (Y8); also elsewhere on the board
LowSideBase9: U601.17 (Y9); also elsewhere on the board
~DecodeEN: R602.2; also elsewhere on the board

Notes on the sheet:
BCD to Decimal Decoder


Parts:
C701: 100uF; CP_Tantalum_Case-B_EIA-3528-21_Reflow; Voltage 10V; Tolerance 20%
C702: 2.2uF; C_0402; Voltage 6.3V; Tolerance 20%
C703: 2.2uF; C_1206; Voltage 10V; Tolerance 10%
C704, C705: 3.3F; MAL219691214E3; Voltage 3V; Tolerance 20%
ECO1, ECO2: 0.1uF; Voltage 50V; Tolerance 20%
Q701: DMP3099L; SOT-23
R701: 1.96M; R_0402; Tolerance 5%
R702: 255k; R_0402; Tolerance 5%
R703, R711: 1.21M; R_0402; Tolerance 5%
R704: 80.6k; R_0402; Tolerance 5%
R705: 0; R_0402; Tolerance 5%
R706, R707: 1M; R_0402; Tolerance 5%
R708, R710: 100; R_0402; Tolerance 5%
R709: 3.83M; R_0402; Tolerance 5%
R712: 10k; R_0402; Tolerance 5%
R713: 536k; R_0402; Tolerance 5%
U701: LTC3226; QFN-16-1EP_3x3mm_Pitch0.5mm

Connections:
+3V3: C702.1, Q701.3 (D), R701.1, R705.1, U701.13 (VIN); also elsewhere on the board
/Backup Supply/BCKUP_EN_CHG: R705.2, R712.1, U701.8 (EN_CHG)
/Backup Supply/BCKUP_PROG: R713.1, U701.9 (PROG)
/Backup Supply/C+: C703.1, U701.15 (C+)
/Backup Supply/C-: C703.2, U701.12 (C-)
/Backup Supply/CAPGOODR: R707.2, R710.1, U701.11 (CAPGOOD)
/Backup Supply/CPO: C704.1, ECO1.1, R709.1, U701.16 (CPO)
/Backup Supply/CPO_FB: R709.2, R711.1, U701.10 (CPO_FB)
/Backup Supply/LDO_FB: R702.2, R704.1, U701.4 (LDO_FB), U701.6 (RST_FB)
/Backup Supply/PFI: R701.2, R703.1, U701.3 (PFI)
/Backup Supply/VMID: C704.2, C705.1, ECO1.2, ECO2.1, U701.14 (VMID)
/Backup Supply/~PFOR: R706.2, R708.1, U701.2 (~PFO)
GND: C701.2, C702.2, C705.2, ECO2.2, R703.2, R704.2, R711.2, R712.2, R713.2, U701.17 (GND); also elsewhere on the board
unnamed: Q701.1 (G), U701.5 (GATE)
VCC_BCKUP: C701.1, Q701.2 (S), R702.1, R706.1, R707.1, U701.1 (VOUT); also elsewhere on the board
VCC_BCKUP_PGOOD: R710.2; also elsewhere on the board
~VCC_BCKUP_PFO: R708.2; also elsewhere on the board

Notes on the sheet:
Backup VCC Supply


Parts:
C801: 0.1uF; C_0402; Voltage 25V; Tolerance 10%
C802: 10nF; C_0402; Voltage 25V; Tolerance 10%
C803: 1nF; C_0402; Voltage 25V; Tolerance 10%
R801, R806, R807, R808: 10k; R_0402; Tolerance 5%
R802, R803, R804, R805: 100; R_0402; Tolerance 5%
U801: 74HC238; SOIC-16_3.9x9.9mm_Pitch1.27mm
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

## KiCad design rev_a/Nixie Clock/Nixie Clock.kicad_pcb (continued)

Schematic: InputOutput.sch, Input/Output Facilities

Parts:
C1201, C1204: 0.1uF; C_0402; Voltage 25V; Tolerance 10%
C1202, C1205: 10nF; C_0402; Voltage 25V; Tolerance 10%
C1203, C1206: 1nF; C_0402; Voltage 25V; Tolerance 10%
D1201: PGOOD; LED_0603
D1202: Error; LED_0603
D1203: Tick; LED_0603
D1204, D1205: SMD1200PL; D_SOD-123F
D1206: 3.3V; D_SOD-323; Part Number PESD3V3L1BA
D1207: Enable; LED_0603
J1201: Display; Pin_Header_Straight_1x02_Pitch2.54mm
JP1201: 12Hr; Pin_Header_Straight_1x02_Pitch2.54mm
Q1201, Q1202, Q1203, Q1204: DMG1012UW; SOT-323_SC-70
R1201, R1205, R1206, R1212, R1213, R1216: 10k; R_0402; Tolerance 5%
R1202, R1207: 100; R_0402; Tolerance 5%
R1203, R1208, R1209, R1214: 1k; R_0402; Tolerance 5%
R1204, R1210, R1211, R1215: 10; R_0402; Tolerance 5%
U1201: MAX6816; SOT-143
U1202: 74LVC1G11; SOT-363_SC-70-6
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

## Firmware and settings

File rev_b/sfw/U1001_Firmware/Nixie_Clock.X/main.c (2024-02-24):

/* 
 * File:   main.c
 * Author: drewm
 *
 * Created on August 13, 2023, 7:25 PM
 */

#include <xc.h>
#include <stdio.h>
#include <stdbool.h>
#include <string.h>

#include "main.h"

// Core Drivers
#include "configuration.h"
#include "device_control.h"
#include "32mz_interrupt_control.h"
#include "heartbeat_timer.h"
#include "watchdog_timer.h"
#include "error_handler.h"
#include "prefetch.h"
#include "cause_of_reset.h"
#include "rtcc.h"


// Application
#include "heartbeat_services.h"
#include "power_saving.h"
#include "telemetry.h"
#include "carrier_spd.h"
#include "pgood_monitor.h"
#include "pin_macros.h"
#include "gpio_setup.h"

// display board specific code
#include "in12_carrier.h"
#include "generic_multiplexing_timers.h"
#include "carrier_spd.h"

//// I2C
#include "plib_i2c.h"
#include "plib_i2c_master.h"
#include "temperature_sensors.h"
#include "power_monitors.h"
#include "misc_i2c_devices.h"

//// USB
#include "terminal_control.h"
#include "uthash.h"
#include "usb_uart.h"
#include "usb_uart_rx_lookup_table.h"

//// ADC
#include "adc.h"
#include "adc_channels.h"


void main(void) {

    // Save the cause of the most recent device reset
    // This also checks for configuration errors
    reset_cause = getResetCause();
    
    // Clear the terminal
    terminalClearScreen();
    terminalSetCursorHome();
    
    // set serial terminal window name
    char *terminal_title_str;
    terminal_title_str = (char *) malloc(64);
    sprintf(terminal_title_str, "%s Serial Terminal", PROJECT_NAME_STR);
    terminalSetTitle(terminal_title_str);
    free(terminal_title_str);
    
    terminalTextAttributesReset();
    terminalTextAttributes(GREEN_COLOR, BLACK_COLOR, BOLD_FONT);
    printf("%s\r\n", PROJECT_NAME_STR);
    printf("Host Firmware Version: %s, Platform Hardware Revision: %s\r\n", FIRMWARE_VERSION_STR, PLATFORM_REVISION_STR);
    printf("Created by Drew Maatman, %s\r\n", PROJECT_DATE_STR);
    
    printf("\r\n");
    
    printf(""
        "  _   _ _______   _______ ______    _____ _      ____   _____ _  __\r\n"
        " | \\ | |_   _\\ \\ / /_   _|  ____|  / ____| |    / __ \\ / ____| |/ /\r\n"
        " |  \\| | | |  \\ V /  | | | |__    | |    | |   | |  | | |    | ' / \r\n"
        " | . ` | | |   > <   | | |  __|   | |    | |   | |  | | |    |  <  \r\n"
        " | |\\  |_| |_ / . \\ _| |_| |____  | |____| |___| |__| | |____| . \\ \r\n"
        " |_| \\_|_____/_/ \\_\\_____|______|  \\_____|______\\____/ \\_____|_|\\_\\ \r\n"
        "                                                                   \r\n"
        "                                                                   \r\n");
    
    printf(
        "    ____  __________  __  ___  __  \r\n"
        "   / __ \\/ ____/ __ \\/ / / / |/ / \r\n"
        "  / /_/ / __/ / / / / / / /|   /  \r\n"
        " / _, _/ /___/ /_/ / /_/ //   |   \r\n"
        "/_/ |_/_____/_____/\\____//_/|_|   \r\n\r\n");

    
    terminalTextAttributesReset();
    
     // Print cause of reset
    if (    reset_cause == Undefined ||
            reset_cause == Primary_Config_Registers_Error ||
            reset_cause == Primary_Secondary_Config_Registers_Error ||
            reset_cause == Config_Mismatch ||
            reset_cause == DMT_Reset ||
            reset_cause == WDT_Reset ||
            reset_cause == Software_Reset ||
            reset_cause == External_Reset ||
            reset_cause == BOR_Reset) {
    
        terminalTextAttributes(RED_COLOR, BLACK_COLOR, NORMAL_FONT);
        
    }
    
    else {
     
        terminalTextAttributes(GREEN_COLOR, BLACK_COLOR, NORMAL_FONT);
        
    }
    
    // only clear persistent error flags if we've seen a POR... keep old values after other resets
    if (reset_cause == POR_Reset) {
        clearErrorHandler();
    }

    live_telemetry_enable = 0;
    live_telemetry_print_request = 0;
    
    printf("\r\nCause of most recent device reset: %s\r\n\r\n", getResetCauseString(reset_cause));
    terminalTextAttributesReset();
    
    terminalTextAttributes(GREEN_COLOR, BLACK_COLOR, BOLD_FONT);
    printf("Beginning Host Initialization:\r\n");
    terminalTextAttributes(GREEN_COLOR, BLACK_COLOR, NORMAL_FONT);
    
    // setup GPIO pins
    gpioInitialize();
    printf("    GPIO Pins Initialized\n\r");
    
    // block on POS3P3 and POS24 power stability
    while(POS3P3_PGOOD_PIN == LOW);
    while(POS24_PGOOD_PIN == LOW);
    printf("    Input power is stable\r\n");
    
    // Disable global interrupts so clocks can be initialized properly
    disableGlobalInterrupts();
    
    // Initialize system clocks
    clockInitialize();
    printf("    Oscillators, Phase-Locked Loop, and System Clocks Initialized\n\r");
    
    // Configure interrupt controller
    interruptControllerInitialize();
    
    // Enable Global Interrupts
    enableGlobalInterrupts();
    printf("    Interrupt Controller Initialized, Global Interrupts Enabled\n\r");
    
    // Setup error handling
    errorHandlerInitialize();
    printf("    Error Handler Initialized\n\r");
    
    // Setup USB UART debugging
    usbUartInitialize();
    printf("    USB UART Initialized, DMA buffer method used\n\r");
    while(usbUartCheckIfBusy());
    
    // Setup prefetch module
    prefetchInitialize();
    printf("    CPU Instruction Prefetch Module Enabled\r\n");
    while(usbUartCheckIfBusy());
    
    // Disable unused peripherals for power savings
    PMDInitialize();
    printf("    Unused Peripheral Modules Disabled\n\r");
    while(usbUartCheckIfBusy());
        
    // Setup heartbeat timer
    heartbeatTimerInitialize();
    printf("    Heartbeat Timer Initialized\n\r");
    while(usbUartCheckIfBusy());
    
    // setup watchdog timer
    watchdogTimerInitialize();
    printf("    Watchdog Timer Initialized\n\r");
    while(usbUartCheckIfBusy());
    
    rtccInitialize();
    if (reset_cause == POR_Reset) rtccClear();
    printf("    Real Time Clock-Calendar Initialized\r\n");
    while(usbUartCheckIfBusy());
    
    // setup I2C
    I2CMaster_Initialize();
    printf("    I2C Bus Master Initialized\r\n");
    while(usbUartCheckIfBusy());
    
    if (TELEMETRY_HARDSTRAP_PIN == LOW) {
        terminalTextAttributes(GREEN_COLOR, BLACK_COLOR, BOLD_FONT);
        printf("    Telemetry Configuration Detected\r\n");
        while(usbUartCheckIfBusy());
        terminalTextAttributes(GREEN_COLOR, BLACK_COLOR, NORMAL_FONT);
        // setup I2C slaves
        tempSensorsInitialize();
        printf("    Temperature Sensors Initialized\r\n");
        while(usbUartCheckIfBusy());
        powerMonitorsInitialize();
        printf("    Power Monitors Initialized\r\n");
        while(usbUartCheckIfBusy());
        // Enable ADC
        ADCInitialize();
        printf("    Analog to Digital Converter Initialized\n\r");
        while(usbUartCheckIfBusy());
    }
    
    else {
        terminalTextAttributes(RED_COLOR, BLACK_COLOR, BOLD_FONT);
        printf("    Telemetry Configuration Not Detected\r\n");
        while(usbUartCheckIfBusy());
        terminalTextAttributes(GREEN_COLOR, BLACK_COLOR, NORMAL_FONT);
    }

    if (ETC_HARDSTRAP_PIN == LOW) {
        terminalTextAttributes(GREEN_COLOR, BLACK_COLOR, BOLD_FONT);
        printf("    Elapsed Time Configuration Detected\r\n");
        while(usbUartCheckIfBusy());
        terminalTextAttributes(GREEN_COLOR, BLACK_COLOR, NORMAL_FONT);
        platformETCInitialize();
        printf("    Platform Elapsed Time Counter Initialized\r\n");
        while(usbUartCheckIfBusy());
    }
    
    else {
        terminalTextAttributes(RED_COLOR, BLACK_COLOR, BOLD_FONT);
        printf("    Platform Elapsed Time Configuration Not Detected\r\n");
        while(usbUartCheckIfBusy());
        terminalTextAttributes(GREEN_COLOR, BLACK_COLOR, NORMAL_FONT);
    }
    
    // Setup the real time clock-calendar
    if (RTC_HARDSTRAP_PIN == LOW) {
        terminalTextAttributes(GREEN_COLOR, BLACK_COLOR, BOLD_FONT);
        printf("    Real Time Clock Configuration Detected\r\n");
        while(usbUartCheckIfBusy());
        terminalTextAttributes(GREEN_COLOR, BLACK_COLOR, NORMAL_FONT);
        
        
        backupRTCInitialize();
        printf("    Backup Real-Time Clock Initialized\r\n");
        backupRTCRestoreTime();
        printf("    Restored time backup from previous sessions\r\n");
        error_handler.flags.backup_rtc = 0;
        
    }
    
    else {
        terminalTextAttributes(RED_COLOR, BLACK_COLOR, BOLD_FONT);
        printf("    Real Time Clock Configuration Not Detected\r\n");
        while(usbUartCheckIfBusy());
        terminalTextAttributes(GREEN_COLOR, BLACK_COLOR, NORMAL_FONT);
    }
    
    // setup random number generator
    RNGInitialize();
    printf("    Hardware Random number Generator Initialized\r\n");
    while(usbUartCheckIfBusy());
    
    // determine if display carrier is present
    if (nDISPLAY_DETECT_PIN == LOW) {
        terminalTextAttributes(GREEN_COLOR, BLACK_COLOR, BOLD_FONT);
        printf("    Display Carrier Detected\r\n");
        while(usbUartCheckIfBusy());
        terminalTextAttributes(GREEN_COLOR, BLACK_COLOR, NORMAL_FONT);
        
        IO_LEVEL_SHIFT_ENABLE_PIN = HIGH;
        printf("    Display Carrier I2C Signals Enabled\r\n");
        while(usbUartCheckIfBusy());
        
        
        carrierPushbuttonInitialize();
        printf("    Display Carrier Generic Pushbutton Interrupts Initialized\r\n");
        while(usbUartCheckIfBusy());
        
        
        // read data from carrier board serial presence detect
        CarrierSPDGetData();
        CarrierSPDPrintString();
        while(usbUartCheckIfBusy());
        
        if (strcmp(&carrier_spd.tube_type, "IN-12") == 0) {
            terminalTextAttributes(GREEN_COLOR, BLACK_COLOR, BOLD_FONT);
            printf("Configuring IN-12 Carrier\r\n");
            terminalTextAttributes(GREEN_COLOR, BLACK_COLOR, NORMAL_FONT);
            IN12Initialize();
        }
        
    }
    
    else {
        terminalTextAttributes(RED_COLOR, BLACK_COLOR, BOLD_FONT);
        printf("    Display Carrier Not Detected\r\n");
        while(usbUartCheckIfBusy());
        terminalTextAttributes(GREEN_COLOR, BLACK_COLOR, NORMAL_FONT);
    }

    // Disable reset LED
    RESET_LED_PIN = LOW;
    terminalTextAttributes(GREEN_COLOR, BLACK_COLOR, NORMAL_FONT);
    printf("    Reset LED Disabled, boot complete\r\n");
    while(usbUartCheckIfBusy());
    
    // Print end of boot message, reset terminal for user input
    terminalTextAttributesReset();
    terminalTextAttributes(YELLOW_COLOR, BLACK_COLOR, NORMAL_FONT);
    printf("\n\rType 'Help' for list of supported commands\n\r\n\r");
    terminalTextAttributesReset();
    
    while(true) {
        
        // get temperature sensor data
        if (temp_sense_data_request) tempSensorsRetrieveData();

        // get power monitor data
        if (power_monitor_data_request) powerMonitorsGetData();
        
        // clear the watchdog if we need to
        if (wdt_clear_request) {
            kickTheDog();
            wdt_clear_request = 0;
        }
        
                
        // Only do these actions if a display is detected
        if (nDISPLAY_DETECT_PIN == LOW) {
         
            // update what's in the in12_display_buffer[] based on what we want to display
            if (strcmp(&carrier_spd.tube_type, "IN-12") == 0) {
                IN12updateClockDisplay();
                // check to see if we need to trigger the alarm
                IN12AlarmCheckMatch();
            }
            
        }
        
        // parse received USB strings if we have a new one received
        if (usb_uart_rx_ready) {
            usbUartRxLUTInterface(usb_uart_rx_buffer);
            // Determine length of received string
            uint32_t length = strlen(usb_uart_rx_buffer);
        
            // clear rx buffer
            uint32_t index;
            for (index = 0; index < length; index++) {
                usb_uart_rx_buffer[index] = '\0';
            }
        }
        
        if (live_telemetry_print_request && live_telemetry_enable) {
            
            // Clear the terminal
            terminalClearScreen();
            terminalSetCursorHome();
            
            terminalTextAttributesReset();
            terminalTextAttributes(CYAN_COLOR, BLACK_COLOR, BOLD_FONT);
            printf("Live system telemetry:\033[K\n\r\033[K");
            
            printCurrentTelemetry();
            
            terminalTextAttributes(YELLOW_COLOR, BLACK_COLOR, NORMAL_FONT);
            printf("Call 'Live Telemetry' command to disable\033[K\n\r");
            terminalTextAttributesReset();
            
            live_telemetry_print_request = 0;
            
        }
        
        // check to see if a clock fail has occurred and latch it
        clockFailCheck();
        
        // update error LEDs if needed
        if (update_error_leds_flag) updateErrorLEDs();

    }

}

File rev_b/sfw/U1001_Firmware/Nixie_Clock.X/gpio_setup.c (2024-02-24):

#include <xc.h>

#include "gpio_setup.h"

// initializes port A GPIO pins
void portAGPIOInitialize (void) {
    
    gpioPinSetup(gpio_port_a, 0, TRIS_OUTPUT, LAT_LOW, ODC_DISABLE, ANALOG_DISABLE);
    gpioPinSetup(gpio_port_a, 1, TRIS_INPUT, LAT_LOW, ODC_DISABLE, ANALOG_DISABLE);
    gpioPinSetup(gpio_port_a, 2, TRIS_OUTPUT, LAT_LOW, ODC_DISABLE, ANALOG_DISABLE);
    gpioPinSetup(gpio_port_a, 3, TRIS_OUTPUT, LAT_LOW, ODC_DISABLE, ANALOG_DISABLE);
    gpioPinSetup(gpio_port_a, 4, TRIS_OUTPUT, LAT_LOW, ODC_DISABLE, ANALOG_DISABLE);
    gpioPinSetup(gpio_port_a, 5, TRIS_OUTPUT, LAT_LOW, ODC_DISABLE, ANALOG_DISABLE);
    gpioPinSetup(gpio_port_a, 6, TRIS_OUTPUT, LAT_LOW, ODC_DISABLE, ANALOG_DISABLE);
    gpioPinSetup(gpio_port_a, 7, TRIS_OUTPUT, LAT_HIGH, ODC_DISABLE, ANALOG_DISABLE);
    gpioPinSetup(gpio_port_a, 9, TRIS_OUTPUT, LAT_LOW, ODC_DISABLE, ANALOG_DISABLE);
    gpioPinSetup(gpio_port_a, 10, TRIS_INPUT, LAT_LOW, ODC_DISABLE, ANALOG_DISABLE);
    gpioPinSetup(gpio_port_a, 14, TRIS_OUTPUT, LAT_LOW, ODC_DISABLE, ANALOG_DISABLE);
    gpioPinSetup(gpio_port_a, 15, TRIS_OUTPUT, LAT_LOW, ODC_DISABLE, ANALOG_DISABLE);
    
}

// initializes port B GPIO pins
void portBGPIOInitialize (void) {

    gpioPinSetup(gpio_port_b, 0, TRIS_OUTPUT, LAT_LOW, ODC_DISABLE, ANALOG_DISABLE);
    gpioPinSetup(gpio_port_b, 1, TRIS_OUTPUT, LAT_LOW, ODC_DISABLE, ANALOG_DISABLE);
    gpioPinSetup(gpio_port_b, 2, TRIS_OUTPUT, LAT_LOW, ODC_DISABLE, ANALOG_DISABLE);
    gpioPinSetup(gpio_port_b, 3, TRIS_OUTPUT, LAT_LOW, ODC_DISABLE, ANALOG_DISABLE);
    gpioPinSetup(gpio_port_b, 4, TRIS_OUTPUT, LAT_LOW, ODC_DISABLE, ANALOG_DISABLE);
    gpioPinSetup(gpio_port_b, 5, TRIS_OUTPUT, LAT_LOW, ODC_DISABLE, ANALOG_DISABLE);
    gpioPinSetup(gpio_port_b, 6, TRIS_OUTPUT, LAT_LOW, ODC_DISABLE, ANALOG_DISABLE);
    gpioPinSetup(gpio_port_b, 7, TRIS_OUTPUT, LAT_LOW, ODC_DISABLE, ANALOG_DISABLE);
    gpioPinSetup(gpio_port_b, 8, TRIS_OUTPUT, LAT_LOW, ODC_DISABLE, ANALOG_DISABLE);
    gpioPinSetup(gpio_port_b, 9, TRIS_OUTPUT, LAT_LOW, ODC_DISABLE, ANALOG_DISABLE);
    gpioPinSetup(gpio_port_b, 10, TRIS_OUTPUT, LAT_LOW, ODC_DISABLE, ANALOG_DISABLE);
    gpioPinSetup(gpio_port_b, 11, TRIS_OUTPUT, LAT_LOW, ODC_DISABLE, ANALOG_DISABLE);
    gpioPinSetup(gpio_port_b, 12, TRIS_OUTPUT, LAT_LOW, ODC_DISABLE, ANALOG_DISABLE);
    gpioPinSetup(gpio_port_b, 13, TRIS_OUTPUT, LAT_LOW, ODC_DISABLE, ANALOG_DISABLE);
    gpioPinSetup(gpio_port_b, 14, TRIS_OUTPUT, LAT_LOW, ODC_DISABLE, ANALOG_DISABLE);
    gpioPinSetup(gpio_port_b, 15, TRIS_OUTPUT, LAT_LOW, ODC_DISABLE, ANALOG_DISABLE);

}

// initializes port C GPIO pins
void portCGPIOInitialize (void) {

    gpioPinSetup(gpio_port_c, 1, TRIS_OUTPUT, LAT_LOW, ODC_DISABLE, ANALOG_DISABLE);
    gpioPinSetup(gpio_port_c, 2, TRIS_INPUT, LAT_LOW, ODC_DISABLE, ANALOG_ENABLE);
    gpioPinSetup(gpio_port_c, 3, TRIS_INPUT, LAT_LOW, ODC_DISABLE, ANALOG_ENABLE);  
    gpioPinSetup(gpio_port_c, 4, TRIS_INPUT, LAT_LOW, ODC_DISABLE, ANALOG_ENABLE);
    RPC13Rbits.RPC13R = REFCLKO1_PPS_OUTPUT;                                            // Assign RC13 as REFCLK1 Output
    gpioPinSetup(gpio_port_c, 15, TRIS_OUTPUT, LAT_LOW, ODC_DISABLE, ANALOG_DISABLE);
    
}

// initializes port D GPIO pins
void portDGPIOInitialize (void) {
    
    gpioPinSetup(gpio_port_d, 0, TRIS_INPUT, LAT_LOW, ODC_DISABLE, ANALOG_DISABLE);
    gpioPinSetup(gpio_port_d, 1, TRIS_INPUT, LAT_LOW, ODC_DISABLE, ANALOG_DISABLE);
    gpioPinSetup(gpio_port_d, 2, TRIS_INPUT, LAT_LOW, ODC_DISABLE, ANALOG_DISABLE);
    gpioPinSetup(gpio_port_d, 3, TRIS_INPUT, LAT_LOW, ODC_DISABLE, ANALOG_DISABLE);
    gpioPinSetup(gpio_port_d, 4, TRIS_INPUT, LAT_LOW, ODC_DISABLE, ANALOG_DISABLE);
    gpioPinSetup(gpio_port_d, 5, TRIS_INPUT, LAT_LOW, ODC_DISABLE, ANALOG_DISABLE);
    gpioPinSetup(gpio_port_d, 9, TRIS_OUTPUT, LAT_LOW, ODC_DISABLE, ANALOG_DISABLE);
    gpioPinSetup(gpio_port_d, 10, TRIS_OUTPUT, LAT_LOW, ODC_DISABLE, ANALOG_DISABLE);
    gpioPinSetup(gpio_port_d, 11, TRIS_OUTPUT, LAT_LOW, ODC_DISABLE, ANALOG_DISABLE);
    gpioPinSetup(gpio_port_d, 12, TRIS_INPUT, LAT_LOW, ODC_DISABLE, ANALOG_DISABLE);
    gpioPinSetup(gpio_port_d, 13, TRIS_INPUT, LAT_LOW, ODC_DISABLE, ANALOG_DISABLE);
    gpioPinSetup(gpio_port_d, 14, TRIS_OUTPUT, LAT_LOW, ODC_DISABLE, ANALOG_DISABLE);
    gpioPinSetup(gpio_port_d, 15, TRIS_INPUT, LAT_LOW, ODC_DISABLE, ANALOG_DISABLE);
    
}
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

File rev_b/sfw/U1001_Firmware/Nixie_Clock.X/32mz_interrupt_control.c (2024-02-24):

#include <xc.h>
#include <stdio.h>

#include "32mz_interrupt_control.h"
#include "terminal_control.h"

// This function configures the system for multi-interrupt operation and
// assigns shadow registers sets to priority level ISRs
void interruptControllerInitialize(void) {
 
    // Enable multi-vector interrupt mode
    INTCONbits.MVEC = 1;
    
    // Assign shadow register sets to interrupt priorities
    // assign shadow set #7-#1 to priority level #7-#1 ISRs
    PRISS = 0x76543210;

}

// This function enables global interrupts
void enableGlobalInterrupts(void) {
 
    // This is built into the XC32 compiler
    __builtin_enable_interrupts();
    
}

// This function disables global interrupts
void disableGlobalInterrupts(void) {
 
    // This is built into the XC32 compiler
    __builtin_disable_interrupts();
    
}

// This function returns the state of global interrupt enable
// Returns 0 if global interrupts are disabled
// returns 1 if global interrupts are enabled
uint8_t getGlobalInterruptsState(void) {
 
    return __builtin_get_isr_state();
    
}

// This function explicitly sets the state of global interrupts
void setGlobalInterruptsState(uint8_t input_state) {

    __builtin_set_isr_state(input_state);
    
}


// This function allows for the setting/clearing of a given interrupt
// It manipulates that interrupt's 'Interrupt Enable' bit
void setInterruptEnable(interrupt_source_t input_interrupt, uint8_t input_state) {
 
    // Mask off anything larger than 1 to 1
    // input_state = input_state >= 1;
    
    // Decide which interrupt control bits to manipulate based on which interrupt
    // is being enabled or disabled
    switch (input_interrupt) {
        
        case Core_Timer_Interrupt:
            IEC0bits.CTIE = input_state;
            break;
            
        case Core_Software_Interrupt_0:
            IEC0bits.CS0IE = input_state;
            break;
            
        case Core_Software_Interrupt_1:
            IEC0bits.CS1IE = input_state;
            break;
            
        case External_Interrupt_0:
            IEC0bits.INT0IE = input_state;
            break;
            
        case Timer1:
            IEC0bits.T1IE = input_state;
            break;
            
        case Input_Capture_1_Error:
            IEC0bits.IC1EIE = input_state;
            break;
            
        case Input_Capture_1:
            IEC0bits.IC1IE = input_state;
            break;
            
        case Output_Compare_1:
            IEC0bits.OC1IE = input_state;
            break;
            
        case External_Interrupt_1:
            IEC0bits.INT1IE = input_state;
            break;
            
        case Timer2:
            IEC0bits.T2IE = input_state;
            break;
            
        case Input_Capture_2_Error:
            IEC0bits.IC2EIE = input_state;
            break;
            
        case Input_Capture_2:
            IEC0bits.IC2IE = input_state;
            break;
            
        case Output_Compare_2:
            IEC0bits.OC2IE = input_state;
            break;
            
        case External_Interrupt_2:
            IEC0bits.INT2IE = input_state;
            break;
            
        case Timer3:
            IEC0bits.T3IE = input_state;
            break;
            
        case Input_Capture_3_Error:
            IEC0bits.IC3EIE = input_state;
            break;
            
        case Input_Capture_3:
            IEC0bits.IC3IE = input_state;
            break;
            
        case Output_Compare_3:
            IEC0bits.OC3IE = input_state;
            break;
            
        case External_Interrupt_3:
            IEC0bits.INT3IE = input_state;
            break;
            
        case Timer4:
            IEC0bits.T4IE = input_state;
            break;
            
        case Input_Capture_4_Error:
            IEC0bits.IC4EIE = input_state;
            break;
            
        case Input_Capture_4:
            IEC0bits.IC4IE = input_state;
            break;
            
        case Output_Compare_4:
            IEC0bits.OC4IE = input_state;
            break;
            
        case External_Interrupt_4:
            IEC0bits.INT4IE = input_state;
            break;
            
        case Timer5:
            IEC0bits.T5IE = input_state;
            break;
            
        case Input_Capture_5_Error:
            IEC0bits.IC5EIE = input_state;
            break;
            
        case Input_Capture_5:
            IEC0bits.IC5IE = input_state;
            break;
            
        case Output_Compare_5:
            IEC0bits.OC5IE = input_state;
            break;
            
        case Timer6:
            IEC0bits.T6IE = input_state;
            break;
            
        case Input_Capture_6_Error:
            IEC0bits.IC6EIE = input_state;
            break;
            
        case Input_Capture_6:
            IEC0bits.IC6IE = input_state;
            break;
            
        case Output_Compare_6:
            IEC0bits.OC6IE = input_state;
            break;
            
        case Timer7:
            IEC1bits.T7IE = input_state;
            break;
            
        case Input_Capture_7_Error:
            IEC1bits.IC7EIE = input_state;
            break;
            
        case Input_Capture_7:
            IEC1bits.IC7IE = input_state;
            break;
            
        case Output_Compare_7:
            IEC1bits.OC7IE = input_state;
            break;
            
        case Timer8:
            IEC1bits.T8IE = input_state;
            break;
            
        case Input_Capture_8_Error:
            IEC1bits.IC8EIE = input_state;
            break;
            
        case Input_Capture_8:
            IEC1bits.IC8IE = input_state;
            break;
            
        case Output_Compare_8:
            IEC1bits.OC8IE = input_state;
            break;
            
        case Timer9:
            IEC1bits.T9IE = input_state;
            break;
            
        case Input_Capture_9_Error:
            IEC1bits.IC9EIE = input_state;
            break;
            
        case Input_Capture_9:
            IEC1bits.IC9IE = input_state;
            break;
            
        case Output_Compare_9:
            IEC1bits.OC9IE = input_state;
            break;
            
        case ADC_Global_Interrupt:
            IEC1bits.ADCIE = input_state;
            break;
            
        case ADC_FIFO_Data_Ready_Interrupt:
            IEC1bits.ADCFIFOIE = input_state;
            break;
            
        case ADC_Digital_Comparator_1:
            IEC1bits.ADCDC1IE = input_state;
            break;
        
        case ADC_Digital_Comparator_2:
            IEC1bits.ADCDC2IE = input_state;
            break;
            
        case ADC_Digital_Comparator_3:
            IEC1bits.ADCDC3IE = input_state;
            break;
            
        case ADC_Digital_Comparator_4:
            IEC1bits.ADCDC4IE = input_state;
            break;
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

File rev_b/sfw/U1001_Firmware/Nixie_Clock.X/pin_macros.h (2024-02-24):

/* ************************************************************************** */
/** Descriptive File Name

  @Company
 Drew Maatman

  @File Name
    pin_macros.h

  @Summary
    Macros for setting and checking the state of GPIO pins

  @Description
    Macros for setting and checking the state of GPIO pins
 */
/* ************************************************************************** */

#ifndef _PIN_MACROS_H    /* Guard against multiple inclusion */
#define _PIN_MACROS_H

#include <xc.h>

#define HIGH    1
#define LOW     0

// These pin macros allow for easier manipulation of GPIO with matching
// signal names from the hardware schematic

// Port A
#define CATHODE_DP_PIN              LATAbits.LATA0
#define POS90_PGOOD_PIN             PORTAbits.RA1
#define ERROR_LED_PIN               LATAbits.LATA5
#define IO_LEVEL_SHIFT_ENABLE_PIN   LATAbits.LATA7
#define POS180_RUN_PIN              LATAbits.LATA9
#define POS180_PGOOD_PIN            PORTAbits.RA10

// Port B
#define ANODE_0_PIN                 LATBbits.LATB0
#define ANODE_1_PIN                 LATBbits.LATB1
#define ANODE_2_PIN                 LATBbits.LATB2
#define ANODE_3_PIN                 LATBbits.LATB3
#define ANODE_4_PIN                 LATBbits.LATB4
#define ANODE_5_PIN                 LATBbits.LATB5
#define CATHODE_0_PIN               LATBbits.LATB8
#define CATHODE_1_PIN               LATBbits.LATB9
#define CATHODE_2_PIN               LATBbits.LATB10
#define CATHODE_3_PIN               LATBbits.LATB11
#define CATHODE_4_PIN               LATBbits.LATB12
#define CATHODE_5_PIN               LATBbits.LATB13
#define CATHODE_6_PIN               LATBbits.LATB14
#define CATHODE_7_PIN               LATBbits.LATB15

// Port C not used for GPIO

// Port D
#define PUSHBUTTON_0_PIN            PORTDbits.RD0
#define PUSHBUTTON_1_PIN            PORTDbits.RD1
#define PUSHBUTTON_2_PIN            PORTDbits.RD2
#define PUSHBUTTON_3_PIN            PORTDbits.RD3
#define PUSHBUTTON_6_PIN            PORTDbits.RD4
#define nDISPLAY_DETECT_PIN         PORTDbits.RD5
#define BUZZER_ENABLE_PIN           LATDbits.LATD9
#define PUSHBUTTON_4_PIN            PORTDbits.RD12
#define PUSHBUTTON_5_PIN            PORTDbits.RD13
#define VBAT_PGOOD_PIN              PORTDbits.RD15

// Port E
#define HEARTBEAT_LED_PIN           LATEbits.LATE0
#define CPU_TRAP_LED_PIN            LATEbits.LATE1
#define COLON_2_PIN                 LATEbits.LATE2
#define COLON_1_PIN                 LATEbits.LATE3
#define COLON_0_PIN                 LATEbits.LATE4
#define CATHODE_9_PIN               LATEbits.LATE8
#define CATHODE_8_PIN               LATEbits.LATE9

// Port F
#define TELEMETRY_HARDSTRAP_PIN     PORTFbits.RF8
#define ETC_HARDSTRAP_PIN           PORTFbits.RF12
#define RTC_HARDSTRAP_PIN           PORTFbits.RF13

// Port G
#define POS24_PGOOD_PIN             PORTGbits.RG0
#define POS3P3_PGOOD_PIN            PORTGbits.RG1
#define PGOOD_LED_SHDN_PIN          LATGbits.LATG12
#define COLON_3_PIN                 LATGbits.LATG13
#define RESET_LED_PIN               LATGbits.LATG15

#endif /* _PIN_MACROS_H */

/* *****************************************************************************
 End of File
 */

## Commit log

2018-08-31 Initial commit of KiCad V4 project
    [BackupSupply.sch, BottomPlate.dxf, BottomPlate.skp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]
2018-08-31 Added MPLAB project for U501 firmware
    [NixieClock.X.production.obj]
2023-05-13 broke off onto rev B
    [BackupSupply-2023-05-12-21-46-44.sch, BackupSupply.sch, Backup_RTC.kicad_sch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]
2023-05-14 lots of rev B control board schematic progress
    [Backup_RTC.kicad_sch, IO_Buffers_1.kicad_sch, IO_Buffers_2.kicad_sch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]
2023-05-14 more rev b sch progress
    [Backup_RTC.kicad_sch, IO Connectors.kicad_sch, IO_Buffers_1.kicad_sch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]
2023-05-21 started IN-12B carrier board
    [Anode_Drive.kicad_sch, Anti_Ghost.kicad_sch, Cathode_Drive.kicad_sch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]
2023-05-29 more carrier board progress
    [IO Connectors.kicad_sch, IO_Buffers_1.kicad_sch, IO_Buffers_2.kicad_sch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]
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2023-06-03 more schematic progress, assigning signals to MCU"
    [IO Connectors.kicad_sch, IO_Buffers_1.kicad_sch, IO_Buffers_2.kicad_sch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]
2023-06-03 updated footprints, ran some DRC
    [Anode_Drive.kicad_sch, Anti_Ghost.kicad_sch, Backup_RTC.kicad_sch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]
2023-06-10 hid all passive refdes on core PCB
    [Backup_RTC.kicad_sch, IO Connectors.kicad_sch, IO_Buffers_1.kicad_sch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]
2023-06-10 started grouping MCU components on PCB
    [Nixie_Clock_Core.kicad_pcb, PIC32MZ_Clocking.kicad_sch]
2023-06-10 much more component placement on core board
    [IO_Buffers_2.kicad_sch, Nixie_Clock_Core.kicad_pcb]
2023-06-10 arranged USB components on PCB, added USB isolator Bypass
    [Nixie_Clock_Core.kicad_pcb, USB_UART_Bridge.kicad_sch, power_input.kicad_sch]
2023-06-10 much more core board component plcement
    [Nixie_Clock_Core.kicad_pcb]
2023-06-10 annotated, started arranging parts for IN12 carrier
    [Anode_Drive.kicad_sch, Anti_Ghost.kicad_sch, Capacitive_Pushbutons.kicad_sch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]
2023-06-11 more core board component placement
    [Nixie_Clock_Core.kicad_pcb, pos180_power_supply.kicad_sch]
2023-06-25 chose new IO connector, fixed some net connectivity issues
    [IO Connectors.kicad_sch, Nixie_Clock_Core.kicad_pcb]
2023-06-26 lots more PCB placement
    [IO_Buffers_2.kicad_sch, Nixie_Clock_Core.kicad_pcb, pos180_telemetry.kicad_sch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]
2023-06-26 started PCB design rules, some layout
    [Nixie_Clock_Core.kicad_pcb, power_input.kicad_sch]
2023-07-03 lots of core board routing
    [IO_Buffers_2.kicad_sch, Nixie_Clock_Core.kicad_pcb, pos180_telemetry.kicad_sch]
2023-07-04 lots more core board routing
    [IO Connectors.kicad_sch, Nixie_Clock_Core.kicad_pcb]
2023-07-07 routed all IO signals from buffers to PIC
    [Nixie_Clock_Core.kicad_pcb, PIC32MZ.kicad_sch]
2023-07-07 got to 0 unconnects
    [Nixie_Clock_Core.kicad_pcb, PIC32MZ.kicad_sch]
2023-07-07 dropped to four layers
    [Nixie_Clock_Core.kicad_pcb]
2023-07-07 lots of placement progress on IN12 carrier board
    [Anode_Drive.kicad_sch, Capacitive_Pushbutons.kicad_sch, Cathode_Drive.kicad_sch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]
2023-07-07 lots more IN12 carrier placement
    [Capacitive_Pushbutons.kicad_sch, IN12_carrier.kicad_pcb]
2023-07-10 lots of routing and design progress on IN12 carrier board
    [Capacitive_Pushbutons.kicad_sch, IN12_carrier.kicad_pcb, IN12_carrier.kicad_sch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]
2023-07-11 carrier board layout progress
    [IN12_carrier.kicad_pcb]
2023-07-11 added cap touch sensors back
    [Capacitive_Pushbutons.kicad_sch, IN12_carrier.kicad_pcb, IN12_carrier.kicad_sch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]
2023-07-12 all components within IN12 carrier board outline
    [Capacitive_Pushbutons.kicad_sch, IN12_carrier.kicad_pcb, Menu_LEDs.kicad_sch]
2023-07-13 some misc signal routing on IN12 carrier
    [IN12_carrier.kicad_pcb]
2023-07-14 more small signal routing on IN12 carrier
    [IN12_carrier.kicad_pcb]
2023-07-15 got IN12 carrier board unconnects to 0
    [IN12_carrier.kicad_pcb, IO_Connector.kicad_sch, LED_Driver.kicad_sch]
2023-07-19 added BOM for IN12 carrier, finished routing, some schematic tweaks, adjusted design rules for ERC
    [Capacitive_Pushbutons.kicad_sch, Elapsed_Time_Counter.kicad_sch, IN12_Tubes.kicad_sch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]
2023-07-21 lots of PCB improvements/touch ups
    [IN12_carrier.kicad_pcb, Nixie_Clock_Core.kicad_pcb]
2023-07-28 fixed some core board ERC issues
    [Nixie_Clock_Core.kicad_pcb]
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2023-08-03 assigned digikey pns to IN12 carrier board parts
    [Anode_Drive.kicad_sch, Anti_Ghost.kicad_sch, Capacitive_Pushbutons.kicad_sch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]
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2023-08-14 wrote pin macros, pulled in configuration.h
    [Microcontroller_Peripheral_Map.xlsx, configuration.h]
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2023-09-09 ported prefetch and cause of reset
    [main.c]
2023-09-09 updated MCU peripheral excel sheet, ported PMD code
    [Microcontroller_Peripheral_Map.xlsx]
2023-09-09 ported RTCC code, fixed some bugs with sscanf in format specifiers due to compiler update
    [main.c]
2023-09-09 ported I2C master driver
    [Microcontroller_Peripheral_Map.xlsx]
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2023-09-23 rebuilt bare metal project
    [configuration.h]
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2023-09-25 ported some ADC code, external channels not working very well
    [32mz_interrupt_control.c, adc_channels.c, adc_channels.h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]
2023-09-25 fixed ADC channel mapping bug
    [adc_channels.c]
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2023-10-13 fixed typo in IN-12 ETC string
    [in12_carrier.c]
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2023-11-11 added user5 layer to IN12 carrier layout for acrylic panel
    [IN12_carrier.kicad_pcb]
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2023-11-26 updated F360 project for case
    [Nixie_Clock_Case v40.f3z]
2023-11-29 added CAD drawings for case walls
    [Nixie_Clock_Case v40.f3z, in12_Nixie_Clock_Case v41.f3z]
2023-12-01 updated laser cut to add 1/8th inch margin on all sides, LED holes, wider tube gaps
    [IN12_carrier.kicad_pcb]
2023-12-03 updated CAD design to use 3D printed connector plate
    [Connector Plate v3.stl, Nixie_Clock_Case v66.f3z, Nixie_Clock_Case_v64.f3z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]
2023-12-15 seem to be making progress on flickering bug
    [in12_carrier.c]
2023-12-15 more fruitless attempts at fixing flickering bug
    [in12_carrier.c, main.c]
2023-12-16 got flicker resolved, using XC32 2.30
    [main.c]
2023-12-16 fixed outdated code comment
    [in12_carrier.c]
2023-12-16 some more random enclosure odds and ends
    [Connector Plate v3.stl, Nixie_Clock_Case v66.f3z, Nixie_Clock_Case v67.f3z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]
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2023-12-25 fixed some stuff in the IN12 BOM
    [in12_carrier_bom.xlsx]
2024-01-03 fixed enclosure CAD drawings
2024-02-24 fixed bugs with setting AM/PM mode and alarm arm through pushbuttons
    [in12_carrier.c]
2024-02-24 slowed I2C baud rate to try to prevent LED driver bus hangs
    [in12_carrier.c, plib_i2c.c]
